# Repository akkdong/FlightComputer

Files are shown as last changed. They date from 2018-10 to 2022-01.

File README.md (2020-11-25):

# Flight Computer(Assistant)

## Hardware 
* Raspberry PI Zero
* E-Ink
* STM32H7 Dual core
* Peripherals
  * 10DOF IMU
  * GPS
  * SD-Card
  * Battery change
  * Codec
  * ...
  <p>
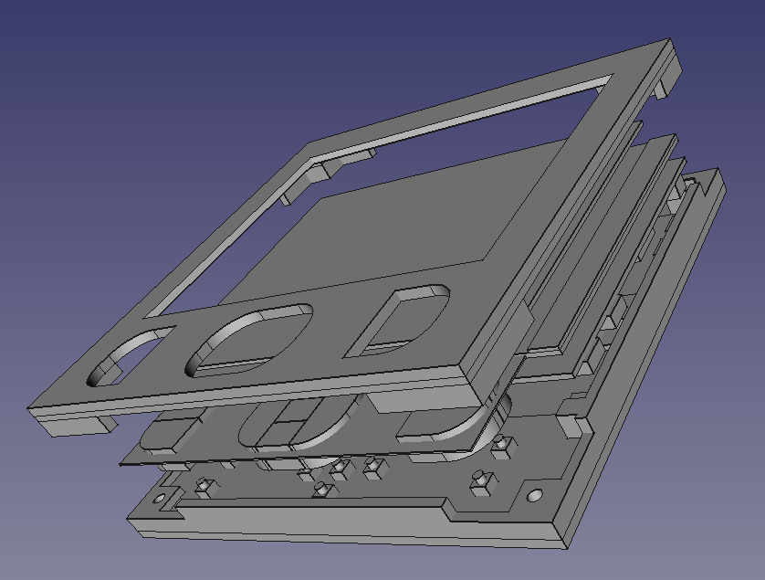
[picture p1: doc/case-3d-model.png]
  
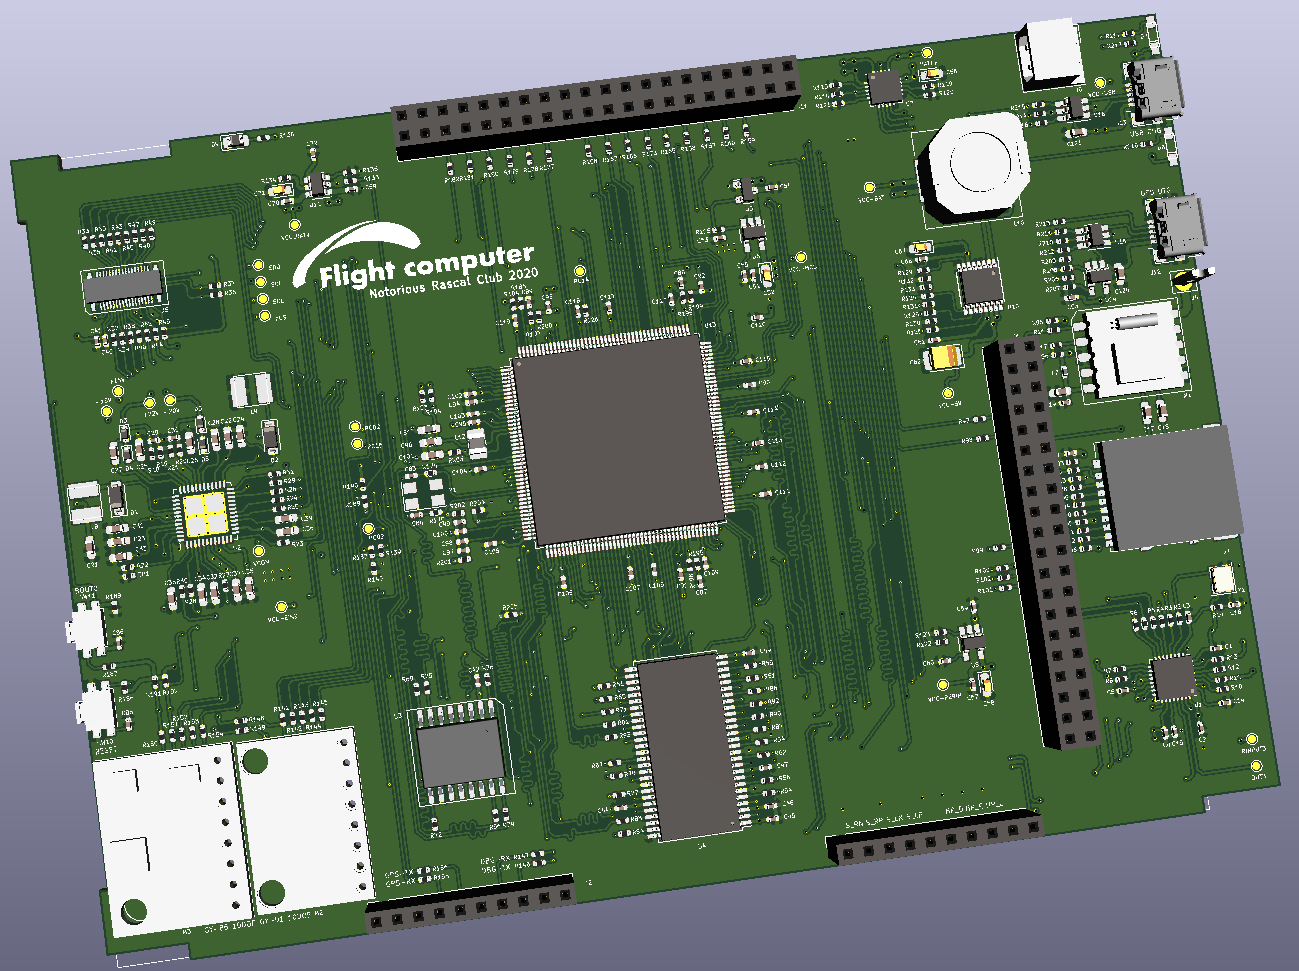
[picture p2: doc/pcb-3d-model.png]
  
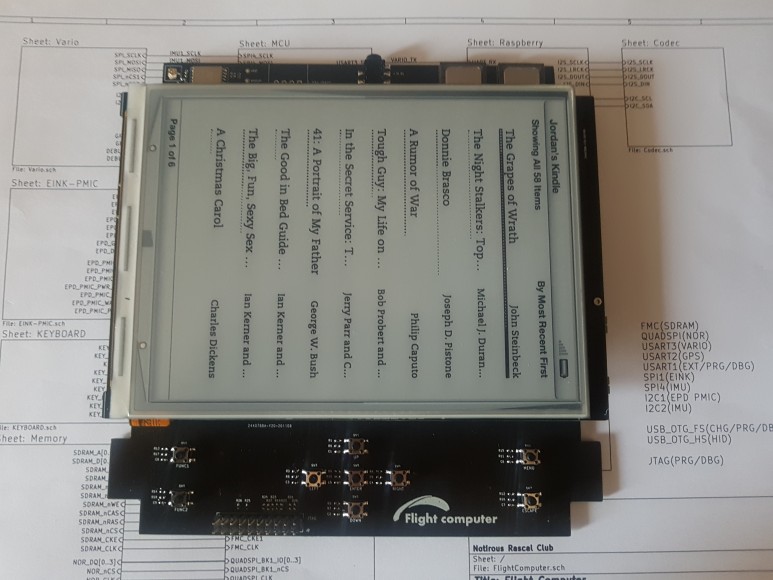
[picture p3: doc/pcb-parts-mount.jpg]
  
  <p>
* ...

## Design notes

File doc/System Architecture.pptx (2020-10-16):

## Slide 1

E-INK

GPIO

STM32H745IIT

RPi

GPS

UART

GPIO/I2C

E-INK PMU

USB

OTG

IMU

SPI

I2C

GPIO

Power booster

SDIO

SD-CARD

KEYs

GPIO

GPIO

Regulator

Regulator

LEDs

EXT

GPIO

UART

Charger

I2S, I2C

CODEC

16bit Bus

SDRAM(32M)

I2C

RADIO(?)

USB Device
Debug(Power)

USBFS

QSPI

QSPI Flash(32M)

USB Host
(HID)

USBHS

UART, SPI

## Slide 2

External
Power
(USB-FS)

Battery

VCC_USB

+BATT

Charger

VCC_BAT

VCC_BAT

REG 3V3

VCC_MCU

MCU

Load
SW

ADC_BATTERY

LED

VCC_BAT+

IMU

REG 3V3

VCC_PERIH

VCC_PERIH

KEYs

UART-EXT

REG 3V3

E-INK PMIU

Power booster
5V

VCC_MEM

GPS

MEMs

+22/-20/+15/-15/VCC_EINK

E-INK

VCC_3V3

USB-HS

CODEC

VCC_5V

RPI

VCC_3V3

SD-CARD/Radio

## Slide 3

GPS w/t Antenna

Debug Port

Audio Jack

Speaker-L

Speaker-R

E-INK

USB-OTG #1

SD-Card

HDMI

USB Device
&
Charge

USB-OTG #2

Up

Func1

Left

Enter/
Power

Right

Func2

Menu

Down

Escape

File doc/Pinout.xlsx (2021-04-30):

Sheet: STM32L4x1_LQFP48
Pins | Pin name | Type | I/O Level | Main | Alternate
 |  |  |  |  | Default | Remap
1 | Vbat | S |  | Vbat |  |  | VCC
2 | PC13-TAMPER-RTC | I/O |  | PC13 | TAMPER-RTC
3 | PC14-OSS32_IN | I/O |  | PC14 | OSC32_IN
4 | PC15-OSC32_OUT | I/O |  | PC15 | OSC32_OUT
5 | OSC_IN | I |  | OSC_IN |  |  | OSC_IN
6 | OSC_OUT | O |  | OSC_OUT |  |  | OSC_OUT
7 | NRST | I/O |  | NRST |  |  | nRST
8 | VSSA | S |  | VSSA |  |  | GND
9 | VDDA | S |  | VDDA |  |  | VCC
10 | PA0-WKUP | I/O |  | PA0 | WKUP/USART2_CTS/ADC12_IN0/TIM2_CH1_ETR
11 | PA1 | I/O |  | PA1 | USART2_RTS/ADC12_IN1/TIM2_CH2
12 | PA2 | I/O |  | PA2 | USART2_TX/ADC12_IN2/TIM2_CH3 |  | UART2_TX
13 | PA3 | I/O |  | PA3 | USART2_RX/ADC12_IN3/TIM2_CH4 |  | UART2_RX
14 | PA4 | I/O |  | PA4 | SP1I_NSS/USART2_CK/ADC12_IN4 |  | SPI_nCS
15 | PA5 | I/O |  | PA5 | SPI1_SCK/ADC12_IN5 |  | SPI_SCLK
16 | PA6 | I/O |  | PA6 | SPI1_MISO/ADC12_IN6/TIM3_CH1 | TIM1_BKIN | SPI_MISO
17 | PA7 | I/O |  | PA7 | SPI1_MOSI/ADC12_IN7/TIM3_CH2 | TIM1_CH1N | SPI_MOSI
18 | PB0 | I/O |  | PB0 | ADC12_IN8/TIM3_CH3 | TIM1_CH2N
19 | PB1 | I/O |  | PB1 | ADC12_IN9/TIM3_CH4 | TIM1_CH3N
20 | PB2 | I/O | FT | PB2/BOOT1 |  |  | BOOT1
21 | PB10 | I/O | FT | PB10 | I2C2_SCL/USART3_TX | TIM2_CH3
22 | PB11 | I/O | FT | PB11 | I2C2_SDA/USART3_RX | TIM2_CH4
23 | VSS_1 | S |  | VSS_1 |  |  | GND
24 | VDD_1 | S |  | VDD_1 |  |  | VCC
25 | PB12 | I/O | FT | PB12 | SPI2_NSS/I2C2_SMBAI/USART3_CK/TIM1_BKIN
26 | PB13 | I/O | FT | PB13 | SPI2_SCK/USART3_CTS/TIM1_CH1N
27 | PB14 | I/O | FT | PB14 | SPI2_MISO/USART3_RTS/TIM1_CH2N
28 | PB15 | I/O | FT | PB15 | SPI2_MOSI/TIM1_CH3N
29 | PA8 | I/O | FT | PA8 | USART1_CK/TIM1_CH1/MCO
30 | PA9 | I/O | FT | PA9 | USART1_TX/TIM1_CH2 |  | UART1_TX
31 | PA10 | I/O | FT | PA10 | USART1_RX/TIM1_CH3 |  | UART1_RX
32 | PA11 | I/O | FT | PA11 | USART1_CTS/CANRX/USBDM/TIM1_CH4 |  | USB_DN
33 | PA12 | I/O | FT | PA12 | USART1_RTS/CANTX/USBDP/TIM1_ETR |  | USB_DP
34 | PA13 | I/O | FT | JTMS/SWDIO |  | PA13 | JTAG_TMS
35 | VSS_2 | S |  | VSS_2 |  |  | GND
36 | VDD_2 | S |  | VDD_2 |  |  | VCC
37 | PA14 | I/O | FT | JTCK/SWCLK |  | PA14 | JTAG_TCK
38 | PA15 | I/O | FT | JTDI |  | TIM2_CH1_ETR/PA15/SPI1_NSS | JTAG_TDI
39 | PB3 | I/O | FT | JTDO |  | TIM2_CH2/PB3/TRACESWO/SPI1_SCK | JTAG_TDO
40 | PB4 | I/O | FT | JNTRST |  | TIM3_CH1/PB4/SPI1_MISO | JTAG_RST
41 | PB5 | I/O |  | PB5 | I2C1_SMBAI | TIM3_CH2/SPI1_MOSI
42 | PB6 | I/O | FT | PB6 | I2C1_SCL/TIM4_CH1 | USART1_TX | I2C_SCL
43 | PB7 | I/O | FT | PB7 | I2C1_SDA/TIM4_CH2 | USART1_RX | I2C_SDA
44 | PH3/BOOT0 | I |  | BOOT0 |  |  | KEY0_BOOT0
45 | PB8 | I/O | FT | PB8 | TIM4_CH3 | I2C1_SCL/CANRX
46 | PB9 | I/O | FT | PB9 | TIM4_CH4 | I2C1_SDA/CANTX
47 | VSS_3 | S |  | VSS_3 |  |  | GND
48 | VDD_3 | S |  | VDD_3 |  |  | VCC
FT = 5V tolerant
I = input, O = output, S = supply

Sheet: STM32F103xx_LQFP48
Pins | Pin name | Type | I/O Level | Main | Alternate
 |  |  |  |  | Default | Remap | Revision 1
1 | Vbat | S |  | Vbat |  |  | Vbat
2 | PC13-TAMPER-RTC | I/O |  | PC13 | TAMPER-RTC |  |  |  | Key
3 | PC14-OSS32_IN | I/O |  | PC14 | OSC32_IN |  |  |  | Up
4 | PC15-OSC32_OUT | I/O |  | PC15 | OSC32_OUT |  |  |  | Down
5 | OSC_IN | I |  | OSC_IN |  |  | OSC |  | Left
6 | OSC_OUT | O |  | OSC_OUT |  |  | OSC |  | Right
7 | NRST | I/O |  | NRST |  |  | RESET |  | Enter
8 | VSSA | S |  | VSSA |  |  | AGND |  | Escape
9 | VDDA | S |  | VDDA |  |  | ACC |  | Func1
10 | PA0-WKUP | I/O |  | PA0 | WKUP/USART2_CTS/ADC12_IN0/TIM2_CH1_ETR |  | Wakeup/KEY_ENTER |  | Func2
11 | PA1 | I/O |  | PA1 | USART2_RTS/ADC12_IN1/TIM2_CH2 |  | KEY_ESC
12 | PA2 | I/O |  | PA2 | USART2_TX/ADC12_IN2/TIM2_CH3 |  | UART2_TX(RPI)
13 | PA3 | I/O |  | PA3 | USART2_RX/ADC12_IN3/TIM2_CH4 |  | UART2_RX(RPI)
14 | PA4 | I/O |  | PA4 | SP1I_NSS/USART2_CK/ADC12_IN4 |  | ADC_BATTERY
15 | PA5 | I/O |  | PA5 | SPI1_SCK/ADC12_IN5 |  | SPI1_SCK
16 | PA6 | I/O |  | PA6 | SPI1_MISO/ADC12_IN6/TIM3_CH1 | TIM1_BKIN | SPI1_MISO |  | IMU1
17 | PA7 | I/O |  | PA7 | SPI1_MOSI/ADC12_IN7/TIM3_CH2 | TIM1_CH1N | SPI1_MOSI |  | I2C
18 | PB0 | I/O |  | PB0 | ADC12_IN8/TIM3_CH3 | TIM1_CH2N | SPI1_CS1 |  | RDY
19 | PB1 | I/O |  | PB1 | ADC12_IN9/TIM3_CH4 | TIM1_CH3N | SPI1_CS2 |  | INT
20 | PB2 | I/O | FT | PB2/BOOT1 |  |  | BOOT1 |  | SYNC
21 | PB10 | I/O | FT | PB10 | I2C2_SCL/USART3_TX | TIM2_CH3 | UART3_TX(GPS)
22 | PB11 | I/O | FT | PB11 | I2C2_SDA/USART3_RX | TIM2_CH4 | UART3_RX(GPS)
23 | VSS_1 | S |  | VSS_1 |  |  | GND
24 | VDD_1 | S |  | VDD_1 |  |  | VCC |  | IM2
25 | PB12 | I/O | FT | PB12 | SPI2_NSS/I2C2_SMBAI/USART3_CK/TIM1_BKIN |  | KEY_UP |  | SPI
26 | PB13 | I/O | FT | PB13 | SPI2_SCK/USART3_CTS/TIM1_CH1N |  | KEY_DOWN |  | CS1
27 | PB14 | I/O | FT | PB14 | SPI2_MISO/USART3_RTS/TIM1_CH2N |  | KEY_RIGHT |  | CS2
28 | PB15 | I/O | FT | PB15 | SPI2_MOSI/TIM1_CH3N |  | KEY_LEFT
29 | PA8 | I/O | FT | PA8 | USART1_CK/TIM1_CH1/MCO |  | LED_STATUS |  | USB_DETECT
30 | PA9 | I/O | FT | PA9 | USART1_TX/TIM1_CH2 |  | UART1_TX(DEBUG) |  | ADC_BAT
31 | PA10 | I/O | FT | PA10 | USART1_RX/TIM1_CH3 |  | UART1_RX(DEBUG)
32 | PA11 | I/O | FT | PA11 | USART1_CTS/CANRX/USBDM/TIM1_CH4 |  | KEY_FUNC1 |  | ENABLE
33 | PA12 | I/O | FT | PA12 | USART1_RTS/CANTX/USBDP/TIM1_ETR |  | KEY_FUNC2 |  | RPI_5V
34 | PA13 | I/O | FT | JTMS/SWDIO |  | PA13 | IMU_DRDY | Input PU on reset | LCD_5V
35 | VSS_2 | S |  | VSS_2 |  |  | GND |  | EN_PERIPH
36 | VDD_2 | S |  | VDD_2 |  |  | VCC |  | EN_BAT
37 | PA14 | I/O | FT | JTCK/SWCLK |  | PA14 | IMU_FSYNC | Input PD on reset
38 | PA15 | I/O | FT | JTDI |  | TIM2_CH1_ETR/PA15/SPI1_NSS | IMU_INT | Input PU on reset
39 | PB3 | I/O | FT | JTDO |  | TIM2_CH2/PB3/TRACESWO/SPI1_SCK |  | Input floating on reset
40 | PB4 | I/O | FT | JNTRST |  | TIM3_CH1/PB4/SPI1_MISO | ENABLE_PERIPH | Input PU on reset
41 | PB5 | I/O |  | PB5 | I2C1_SMBAI | TIM3_CH2/SPI1_MOSI | ENABLE_BAT
42 | PB6 | I/O | FT | PB6 | I2C1_SCL/TIM4_CH1 | USART1_TX | I2C1_SCL
43 | PB7 | I/O | FT | PB7 | I2C1_SDA/TIM4_CH2 | USART1_RX | I2C1_SDA
44 | BOOT0 | I |  | BOOT0 |  |  | BOOT0
45 | PB8 | I/O | FT | PB8 | TIM4_CH3 | I2C1_SCL/CANRX | ENABLE_5V
46 | PB9 | I/O | FT | PB9 | TIM4_CH4 | I2C1_SDA/CANTX | ENABLE_LCD
47 | VSS_3 | S |  | VSS_3 |  |  | GND
48 | VDD_3 | S |  | VDD_3 |  |  | VCC
FT = 5V tolerant
I = input, O = output, S = supply

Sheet: Raspberry PI
Pins | Pin name | SDIO | UART | PCM | WiringPi | I2C | SPI | E-INK | GPIO
 |  |  |  |  |  |  |  |  |  | Revision 1
1 | 3v3 Power
2 | 5v Power
3 | BCM 2 |  |  |  | GPIO 8 | DAT1 |  |  |  | I2C_DAT
4 | 5v Power
5 | BCM 3 |  |  |  | GPIO 9 | SCL1 |  |  |  | I2C_SCL
6 | GND
7 | BCM 4 |  |  |  | GPIO 7
8 | BCM 14 |  | TXD |  | GPIO 15 |  |  |  |  | UART_TXD
9 | GND
10 | BCM 15 |  | RXD |  | GPIO 16 |  |  |  |  | UART_RXD
11 | BCM 17 |  |  |  | GPIO 0 |  | SPI1 CE1
12 | BCM 18 |  |  | CLK | GPIO 1 |  | SPI1 CE0 |  |  | I2S_SCLK
13 | BCM 27 | DAT3 |  |  | GPIO 2 |  |  |  |  | SDIO_DAT3
14 | GND
15 | BCM 22 | CLK |  |  | GPIO 3 |  |  |  |  | SDIO_CLK
16 | BCM 23 | CMD |  |  | GPIO 4 |  |  |  |  | SDIO_CMD
17 | 3v3 Power
18 | BCM 24 | DAT0 |  |  | GPIO 5 |  |  |  |  | SDIO_DAT0
19 | BCM 10 |  |  |  | GPIO 12 |  | SPI0 MOSI | DIN
20 | GND
21 | BCM 9 |  |  |  | GPIO13 |  | SPI0 MISO
22 | BCM 25 | DAT1 |  |  | GPIO 6 |  |  |  |  | SDIO_DAT1
23 | BCM 11 |  |  |  | GPIO 14 |  | SPI0 SCLK | CLK
24 | BCM 8 |  |  |  | GPIO 10 |  | SPI0 CE0 | CS
25 | GND
26 | BCM 7 |  |  |  | GPIO 11 |  | SPI0 CE1
27 | BCM 0 |  |  |  | GPIO 30 | DAT0
28 | BCM 1 |  |  |  | GPIO 31 | SCL0
29 | BCM 5 |  |  |  | GPIO 21 |  |  | DC
30 | GND
31 | BCM 6 |  |  |  | GPIO 22 |  |  | RST
32 | BCM 12 |  |  |  | GPIO 26
33 | BCM 13 |  |  |  | GPIO 23 |  |  | BUSY
34 | GND
35 | BCM 19 |  |  | FS | GPIO 24 |  | SPI1 MISO |  |  | I2S_LRCK
36 | BCM 16 |  |  |  | GPIO 27 |  | SPI1 CE2 |  | EN_OTG
37 | BCM 26 | DAT2 |  |  | GPIO 25 |  |  |  |  | SDIO_DAT2
38 | BCM 20 |  |  | DIN | GPIO 28 |  | SPI1 MOSI |  |  | I2S_DIN
39 | GND
40 | BCM 21 |  |  | DOUT | GPIO 29 |  | SPI1 SCLK |  |  | I2S_DCOUT
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

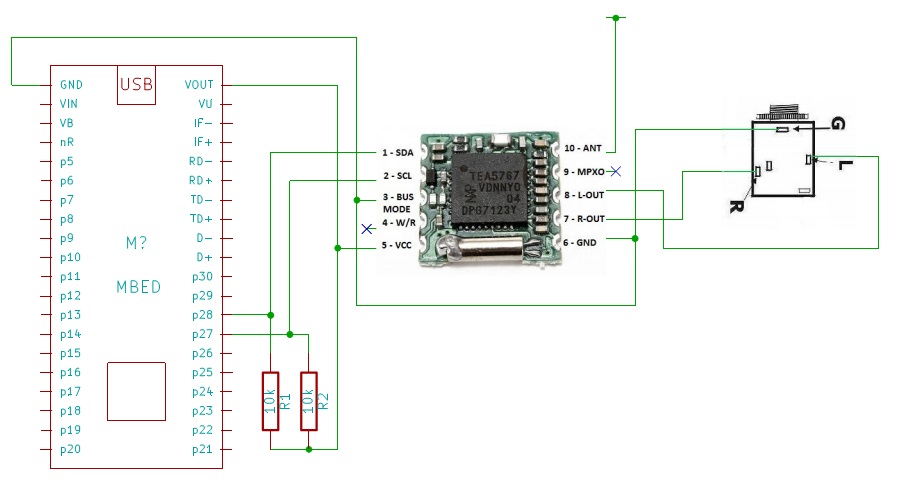
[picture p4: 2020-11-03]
doc/datasheet/tea5767-schematic.jpg

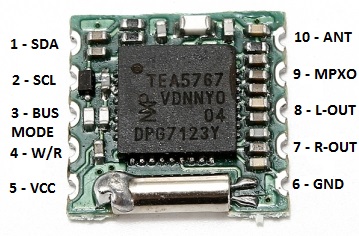
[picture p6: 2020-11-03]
doc/datasheet/tea5767_pinout.jpg

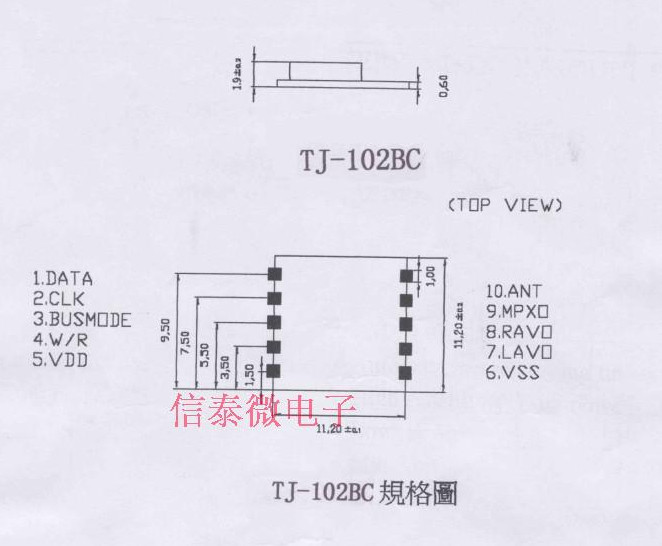
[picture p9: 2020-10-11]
doc/datasheet/TJ-102BC.jpg

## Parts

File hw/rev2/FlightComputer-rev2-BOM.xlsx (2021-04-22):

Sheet: FlightComputer-rev2-BOM
Reference(s) | References | Qty | Flag | Value | Parts | Manufacturer Part# | LibPart | Footprint | Datasheet
C27 | C27 | 1 |  | 0.01uF | a |  | Device:C_Small | Capacitor_SMD:C_0603_1608Metric_Pad1.05x0.95mm_HandSolder | Multilayer Ceramic Capacitors MLCC - SMD/SMT 25V 0.01uF X7R 0603 10% AEC-Q200
C28 | C27, C28 | 2 | Last | 0.01uF | a |  | Device:C_Small | Capacitor_SMD:C_0603_1608Metric_Pad1.05x0.95mm_HandSolder | Multilayer Ceramic Capacitors MLCC - SMD/SMT 25V 0.01uF X7R 0603 10% AEC-Q200
C25 | C25 | 1 |  | 0.1uF | b |  | Device:C_Small | Capacitor_SMD:C_0603_1608Metric_Pad1.05x0.95mm_HandSolder | Multilayer Ceramic Capacitors MLCC - SMD/SMT .1uF 25V 10% AEC-Q200
C26 | C25, C26 | 2 | Last | 0.1uF | b |  | Device:C_Small | Capacitor_SMD:C_0603_1608Metric_Pad1.05x0.95mm_HandSolder | Multilayer Ceramic Capacitors MLCC - SMD/SMT .1uF 25V 10% AEC-Q200
C1 | C1 | 1 |  | 0.1uF | C0402 |  | Device:C_Small | FlightComputer_Library:C_0402_1005Metric_Pad0.74x0.62mm_HandSolder | ~
C100 | C1, C100 | 2 |  | 0.1uF | C0402 |  | Device:C_Small | FlightComputer_Library:C_0402_1005Metric_Pad0.74x0.62mm_HandSolder | ~
C1005 | C1, C100, C1005 | 3 |  | 0.1uF | C0402 |  | Device:C_Small | FlightComputer_Library:C_0402_1005Metric_Pad0.74x0.62mm_HandSolder | ~
C1006 | C1, C100, C1005, C1006 | 4 |  | 0.1uF | C0402 |  | Device:C_Small | FlightComputer_Library:C_0402_1005Metric_Pad0.74x0.62mm_HandSolder | ~
C1007 | C1, C100, C1005, C1006, C1007 | 5 |  | 0.1uF | C0402 |  | Device:C_Small | FlightComputer_Library:C_0402_1005Metric_Pad0.74x0.62mm_HandSolder | ~
C1017 | C1, C100, C1005, C1006, C1007, C1017 | 6 |  | 0.1uF | C0402 |  | Device:C_Small | FlightComputer_Library:C_0402_1005Metric_Pad0.74x0.62mm_HandSolder | ~
C1018 | C1, C100, C1005, C1006, C1007, C1017, C1018 | 7 |  | 0.1uF | C0402 |  | Device:C_Small | FlightComputer_Library:C_0402_1005Metric_Pad0.74x0.62mm_HandSolder | ~
C1019 | C1, C100, C1005, C1006, C1007, C1017, C1018, C1019 | 8 |  | 0.1uF | C0402 |  | Device:C_Small | FlightComputer_Library:C_0402_1005Metric_Pad0.74x0.62mm_HandSolder | ~
C102 | C1, C100, C1005, C1006, C1007, C1017, C1018, C1019, C102 | 9 |  | 0.1uF | C0402 |  | Device:C_Small | FlightComputer_Library:C_0402_1005Metric_Pad0.74x0.62mm_HandSolder | ~
C103 | C1, C100, C1005, C1006, C1007, C1017, C1018, C1019, C102, C103 | 10 |  | 0.1uF | C0402 |  | Device:C_Small | FlightComputer_Library:C_0402_1005Metric_Pad0.74x0.62mm_HandSolder | ~
C104 | C1, C100, C1005, C1006, C1007, C1017, C1018, C1019, C102, C103, C104 | 11 |  | 0.1uF | C0402 |  | Device:C_Small | FlightComputer_Library:C_0402_1005Metric_Pad0.74x0.62mm_HandSolder | ~
C105 | C1, C100, C1005, C1006, C1007, C1017, C1018, C1019, C102, C103, C104, C105 | 12 |  | 0.1uF | C0402 |  | Device:C_Small | FlightComputer_Library:C_0402_1005Metric_Pad0.74x0.62mm_HandSolder | ~
C106 | C1, C100, C1005, C1006, C1007, C1017, C1018, C1019, C102, C103, C104, C105, C106 | 13 |  | 0.1uF | C0402 |  | Device:C_Small | FlightComputer_Library:C_0402_1005Metric_Pad0.74x0.62mm_HandSolder | ~
C107 | C1, C100, C1005, C1006, C1007, C1017, C1018, C1019, C102, C103, C104, C105, C106, C107 | 14 |  | 0.1uF | C0402 |  | Device:C_Small | FlightComputer_Library:C_0402_1005Metric_Pad0.74x0.62mm_HandSolder | ~
C108 | C1, C100, C1005, C1006, C1007, C1017, C1018, C1019, C102, C103, C104, C105, C106, C107, C108 | 15 |  | 0.1uF | C0402 |  | Device:C_Small | FlightComputer_Library:C_0402_1005Metric_Pad0.74x0.62mm_HandSolder | ~
C109 | C1, C100, C1005, C1006, C1007, C1017, C1018, C1019, C102, C103, C104, C105, C106, C107, C108, C109 | 16 |  | 0.1uF | C0402 |  | Device:C_Small | FlightComputer_Library:C_0402_1005Metric_Pad0.74x0.62mm_HandSolder | ~
C111 | C1, C100, C1005, C1006, C1007, C1017, C1018, C1019, C102, C103, C104, C105, C106, C107, C108, C109, C111 | 17 |  | 0.1uF | C0402 |  | Device:C_Small | FlightComputer_Library:C_0402_1005Metric_Pad0.74x0.62mm_HandSolder | ~
C112 | C1, C100, C1005, C1006, C1007, C1017, C1018, C1019, C102, C103, C104, C105, C106, C107, C108, C109, C111, C112 | 18 |  | 0.1uF | C0402 |  | Device:C_Small | FlightComputer_Library:C_0402_1005Metric_Pad0.74x0.62mm_HandSolder | ~
C113 | C1, C100, C1005, C1006, C1007, C1017, C1018, C1019, C102, C103, C104, C105, C106, C107, C108, C109, C111, C112, C113 | 19 |  | 0.1uF | C0402 |  | Device:C_Small | FlightComputer_Library:C_0402_1005Metric_Pad0.74x0.62mm_HandSolder | ~
C114 | C1, C100, C1005, C1006, C1007, C1017, C1018, C1019, C102, C103, C104, C105, C106, C107, C108, C109, C111, C112, C113, C114 | 20 |  | 0.1uF | C0402 |  | Device:C_Small | FlightComputer_Library:C_0402_1005Metric_Pad0.74x0.62mm_HandSolder | ~
C115 | C1, C100, C1005, C1006, C1007, C1017, C1018, C1019, C102, C103, C104, C105, C106, C107, C108, C109, C111, C112, C113, C114, C115 | 21 |  | 0.1uF | C0402 |  | Device:C_Small | FlightComputer_Library:C_0402_1005Metric_Pad0.74x0.62mm_HandSolder | ~
C116 | C1, C100, C1005, C1006, C1007, C1017, C1018, C1019, C102, C103, C104, C105, C106, C107, C108, C109, C111, C112, C113, C114, C115, C116 | 22 |  | 0.1uF | C0402 |  | Device:C_Small | FlightComputer_Library:C_0402_1005Metric_Pad0.74x0.62mm_HandSolder | ~
C117 | C1, C100, C1005, C1006, C1007, C1017, C1018, C1019, C102, C103, C104, C105, C106, C107, C108, C109, C111, C112, C113, C114, C115, C116, C117 | 23 |  | 0.1uF | C0402 |  | Device:C_Small | FlightComputer_Library:C_0402_1005Metric_Pad0.74x0.62mm_HandSolder | ~
C118 | C1, C100, C1005, C1006, C1007, C1017, C1018, C1019, C102, C103, C104, C105, C106, C107, C108, C109, C111, C112, C113, C114, C115, C116, C117, C118 | 24 |  | 0.1uF | C0402 |  | Device:C_Small | FlightComputer_Library:C_0402_1005Metric_Pad0.74x0.62mm_HandSolder | ~
C119 | C1, C100, C1005, C1006, C1007, C1017, C1018, C1019, C102, C103, C104, C105, C106, C107, C108, C109, C111, C112, C113, C114, C115, C116, C117, C118, C119 | 25 |  | 0.1uF | C0402 |  | Device:C_Small | FlightComputer_Library:C_0402_1005Metric_Pad0.74x0.62mm_HandSolder | ~
C16 | C1, C100, C1005, C1006, C1007, C1017, C1018, C1019, C102, C103, C104, C105, C106, C107, C108, C109, C111, C112, C113, C114, C115, C116, C117, C118, C119, C16 | 26 |  | 0.1uF | C0402 |  | Device:C_Small | FlightComputer_Library:C_0402_1005Metric_Pad0.74x0.62mm_HandSolder | ~
C19 | C1, C100, C1005, C1006, C1007, C1017, C1018, C1019, C102, C103, C104, C105, C106, C107, C108, C109, C111, C112, C113, C114, C115, C116, C117, C118, C119, C16, C19 | 27 |  | 0.1uF | C0402 |  | Device:C_Small | FlightComputer_Library:C_0402_1005Metric_Pad0.74x0.62mm_HandSolder | ~
C2 | C1, C100, C1005, C1006, C1007, C1017, C1018, C1019, C102, C103, C104, C105, C106, C107, C108, C109, C111, C112, C113, C114, C115, C116, C117, C118, C119, C16, C19, C2 | 28 |  | 0.1uF | C0402 |  | Device:C_Small | FlightComputer_Library:C_0402_1005Metric_Pad0.74x0.62mm_HandSolder | ~
C3 | C1, C100, C1005, C1006, C1007, C1017, C1018, C1019, C102, C103, C104, C105, C106, C107, C108, C109, C111, C112, C113, C114, C115, C116, C117, C118, C119, C16, C19, C2, C3 | 29 |  | 0.1uF | C0402 |  | Device:C_Small | FlightComputer_Library:C_0402_1005Metric_Pad0.74x0.62mm_HandSolder | ~
C41 | C1, C100, C1005, C1006, C1007, C1017, C1018, C1019, C102, C103, C104, C105, C106, C107, C108, C109, C111, C112, C113, C114, C115, C116, C117, C118, C119, C16, C19, C2, C3, C41 | 30 |  | 0.1uF | C0402 |  | Device:C_Small | FlightComputer_Library:C_0402_1005Metric_Pad0.74x0.62mm_HandSolder | ~
C42 | C1, C100, C1005, C1006, C1007, C1017, C1018, C1019, C102, C103, C104, C105, C106, C107, C108, C109, C111, C112, C113, C114, C115, C116, C117, C118, C119, C16, C19, C2, C3, C41, C42 | 31 |  | 0.1uF | C0402 |  | Device:C_Small | FlightComputer_Library:C_0402_1005Metric_Pad0.74x0.62mm_HandSolder | ~
C43 | C1, C100, C1005, C1006, C1007, C1017, C1018, C1019, C102, C103, C104, C105, C106, C107, C108, C109, C111, C112, C113, C114, C115, C116, C117, C118, C119, C16, C19, C2, C3, C41, C42, C43 | 32 |  | 0.1uF | C0402 |  | Device:C_Small | FlightComputer_Library:C_0402_1005Metric_Pad0.74x0.62mm_HandSolder | ~
C44 | C1, C100, C1005, C1006, C1007, C1017, C1018, C1019, C102, C103, C104, C105, C106, C107, C108, C109, C111, C112, C113, C114, C115, C116, C117, C118, C119, C16, C19, C2, C3, C41, C42, C43, C44 | 33 |  | 0.1uF | C0402 |  | Device:C_Small | FlightComputer_Library:C_0402_1005Metric_Pad0.74x0.62mm_HandSolder | ~
C45 | C1, C100, C1005, C1006, C1007, C1017, C1018, C1019, C102, C103, C104, C105, C106, C107, C108, C109, C111, C112, C113, C114, C115, C116, C117, C118, C119, C16, C19, C2, C3, C41, C42, C43, C44, C45 | 34 |  | 0.1uF | C0402 |  | Device:C_Small | FlightComputer_Library:C_0402_1005Metric_Pad0.74x0.62mm_HandSolder | ~
C46 | C1, C100, C1005, C1006, C1007, C1017, C1018, C1019, C102, C103, C104, C105, C106, C107, C108, C109, C111, C112, C113, C114, C115, C116, C117, C118, C119, C16, C19, C2, C3, C41, C42, C43, C44, C45, C46 | 35 |  | 0.1uF | C0402 |  | Device:C_Small | FlightComputer_Library:C_0402_1005Metric_Pad0.74x0.62mm_HandSolder | ~
C47 | C1, C100, C1005, C1006, C1007, C1017, C1018, C1019, C102, C103, C104, C105, C106, C107, C108, C109, C111, C112, C113, C114, C115, C116, C117, C118, C119, C16, C19, C2, C3, C41, C42, C43, C44, C45, C46, C47 | 36 |  | 0.1uF | C0402 |  | Device:C_Small | FlightComputer_Library:C_0402_1005Metric_Pad0.74x0.62mm_HandSolder | ~
C48 | C1, C100, C1005, C1006, C1007, C1017, C1018, C1019, C102, C103, C104, C105, C106, C107, C108, C109, C111, C112, C113, C114, C115, C116, C117, C118, C119, C16, C19, C2, C3, C41, C42, C43, C44, C45, C46, C47, C48 | 37 |  | 0.1uF | C0402 |  | Device:C_Small | FlightComputer_Library:C_0402_1005Metric_Pad0.74x0.62mm_HandSolder | ~
C49 | C1, C100, C1005, C1006, C1007, C1017, C1018, C1019, C102, C103, C104, C105, C106, C107, C108, C109, C111, C112, C113, C114, C115, C116, C117, C118, C119, C16, C19, C2, C3, C41, C42, C43, C44, C45, C46, C47, C48, C49 | 38 |  | 0.1uF | C0402 |  | Device:C_Small | FlightComputer_Library:C_0402_1005Metric_Pad0.74x0.62mm_HandSolder | ~
C50 | C1, C100, C1005, C1006, C1007, C1017, C1018, C1019, C102, C103, C104, C105, C106, C107, C108, C109, C111, C112, C113, C114, C115, C116, C117, C118, C119, C16, C19, C2, C3, C41, C42, C43, C44, C45, C46, C47, C48, C49, C50 | 39 |  | 0.1uF | C0402 |  | Device:C_Small | FlightComputer_Library:C_0402_1005Metric_Pad0.74x0.62mm_HandSolder | ~
C51 | C1, C100, C1005, C1006, C1007, C1017, C1018, C1019, C102, C103, C104, C105, C106, C107, C108, C109, C111, C112, C113, C114, C115, C116, C117, C118, C119, C16, C19, C2, C3, C41, C42, C43, C44, C45, C46, C47, C48, C49, C50, C51 | 40 |  | 0.1uF | C0402 |  | Device:C_Small | FlightComputer_Library:C_0402_1005Metric_Pad0.74x0.62mm_HandSolder | ~
C57 | C1, C100, C1005, C1006, C1007, C1017, C1018, C1019, C102, C103, C104, C105, C106, C107, C108, C109, C111, C112, C113, C114, C115, C116, C117, C118, C119, C16, C19, C2, C3, C41, C42, C43, C44, C45, C46, C47, C48, C49, C50, C51, C57 | 41 |  | 0.1uF | C0402 |  | Device:C_Small | FlightComputer_Library:C_0402_1005Metric_Pad0.74x0.62mm_HandSolder | ~
C70 | C1, C100, C1005, C1006, C1007, C1017, C1018, C1019, C102, C103, C104, C105, C106, C107, C108, C109, C111, C112, C113, C114, C115, C116, C117, C118, C119, C16, C19, C2, C3, C41, C42, C43, C44, C45, C46, C47, C48, C49, C50, C51, C57, C70 | 42 |  | 0.1uF | C0402 |  | Device:C_Small | FlightComputer_Library:C_0402_1005Metric_Pad0.74x0.62mm_HandSolder | ~
C76 | C1, C100, C1005, C1006, C1007, C1017, C1018, C1019, C102, C103, C104, C105, C106, C107, C108, C109, C111, C112, C113, C114, C115, C116, C117, C118, C119, C16, C19, C2, C3, C41, C42, C43, C44, C45, C46, C47, C48, C49, C50, C51, C57, C70, C76 | 43 |  | 0.1uF | C0402 |  | Device:C_Small | FlightComputer_Library:C_0402_1005Metric_Pad0.74x0.62mm_HandSolder | ~
C80 | C1, C100, C1005, C1006, C1007, C1017, C1018, C1019, C102, C103, C104, C105, C106, C107, C108, C109, C111, C112, C113, C114, C115, C116, C117, C118, C119, C16, C19, C2, C3, C41, C42, C43, C44, C45, C46, C47, C48, C49, C50, C51, C57, C70, C76, C80 | 44 |  | 0.1uF | C0402 |  | Device:C_Small | FlightComputer_Library:C_0402_1005Metric_Pad0.74x0.62mm_HandSolder | ~
C81 | C1, C100, C1005, C1006, C1007, C1017, C1018, C1019, C102, C103, C104, C105, C106, C107, C108, C109, C111, C112, C113, C114, C115, C116, C117, C118, C119, C16, C19, C2, C3, C41, C42, C43, C44, C45, C46, C47, C48, C49, C50, C51, C57, C70, C76, C80, C81 | 45 |  | 0.1uF | C0402 |  | Device:C_Small | FlightComputer_Library:C_0402_1005Metric_Pad0.74x0.62mm_HandSolder | ~
C85 | C1, C100, C1005, C1006, C1007, C1017, C1018, C1019, C102, C103, C104, C105, C106, C107, C108, C109, C111, C112, C113, C114, C115, C116, C117, C118, C119, C16, C19, C2, C3, C41, C42, C43, C44, C45, C46, C47, C48, C49, C50, C51, C57, C70, C76, C80, C81, C85 | 46 |  | 0.1uF | C0402 |  | Device:C_Small | FlightComputer_Library:C_0402_1005Metric_Pad0.74x0.62mm_HandSolder | ~
C86 | C1, C100, C1005, C1006, C1007, C1017, C1018, C1019, C102, C103, C104, C105, C106, C107, C108, C109, C111, C112, C113, C114, C115, C116, C117, C118, C119, C16, C19, C2, C3, C41, C42, C43, C44, C45, C46, C47, C48, C49, C50, C51, C57, C70, C76, C80, C81, C85, C86 | 47 |  | 0.1uF | C0402 |  | Device:C_Small | FlightComputer_Library:C_0402_1005Metric_Pad0.74x0.62mm_HandSolder | ~
C87 | C1, C100, C1005, C1006, C1007, C1017, C1018, C1019, C102, C103, C104, C105, C106, C107, C108, C109, C111, C112, C113, C114, C115, C116, C117, C118, C119, C16, C19, C2, C3, C41, C42, C43, C44, C45, C46, C47, C48, C49, C50, C51, C57, C70, C76, C80, C81, C85, C86, C87 | 48 |  | 0.1uF | C0402 |  | Device:C_Small | FlightComputer_Library:C_0402_1005Metric_Pad0.74x0.62mm_HandSolder | ~
C88 | C1, C100, C1005, C1006, C1007, C1017, C1018, C1019, C102, C103, C104, C105, C106, C107, C108, C109, C111, C112, C113, C114, C115, C116, C117, C118, C119, C16, C19, C2, C3, C41, C42, C43, C44, C45, C46, C47, C48, C49, C50, C51, C57, C70, C76, C80, C81, C85, C86, C87, C88 | 49 |  | 0.1uF | C0402 |  | Device:C_Small | FlightComputer_Library:C_0402_1005Metric_Pad0.74x0.62mm_HandSolder | ~
C89 | C1, C100, C1005, C1006, C1007, C1017, C1018, C1019, C102, C103, C104, C105, C106, C107, C108, C109, C111, C112, C113, C114, C115, C116, C117, C118, C119, C16, C19, C2, C3, C41, C42, C43, C44, C45, C46, C47, C48, C49, C50, C51, C57, C70, C76, C80, C81, C85, C86, C87, C88, C89 | 50 |  | 0.1uF | C0402 |  | Device:C_Small | FlightComputer_Library:C_0402_1005Metric_Pad0.74x0.62mm_HandSolder | ~
C94 | C1, C100, C1005, C1006, C1007, C1017, C1018, C1019, C102, C103, C104, C105, C106, C107, C108, C109, C111, C112, C113, C114, C115, C116, C117, C118, C119, C16, C19, C2, C3, C41, C42, C43, C44, C45, C46, C47, C48, C49, C50, C51, C57, C70, C76, C80, C81, C85, C86, C87, C88, C89, C94 | 51 |  | 0.1uF | C0402 |  | Device:C_Small | FlightComputer_Library:C_0402_1005Metric_Pad0.74x0.62mm_HandSolder | ~
C98 | C1, C100, C1005, C1006, C1007, C1017, C1018, C1019, C102, C103, C104, C105, C106, C107, C108, C109, C111, C112, C113, C114, C115, C116, C117, C118, C119, C16, C19, C2, C3, C41, C42, C43, C44, C45, C46, C47, C48, C49, C50, C51, C57, C70, C76, C80, C81, C85, C86, C87, C88, C89, C94, C98 | 52 | Last | 0.1uF | C0402 |  | Device:C_Small | FlightComputer_Library:C_0402_1005Metric_Pad0.74x0.62mm_HandSolder | ~
C122 | C122 | 1 | Last | 0.47uF |  |  | Device:C_Small | FlightComputer_Library:C_0402_1005Metric_Pad0.74x0.62mm_HandSolder | ~
R124 | R124 | 1 |  | 0R |  |  | Device:R_US | FlightComputer_Library:R_0402_1005Metric_Pad0.72x0.64mm_HandSolder | ~
R125 | R124, R125 | 2 |  | 0R |  |  | Device:R_US | FlightComputer_Library:R_0402_1005Metric_Pad0.72x0.64mm_HandSolder | ~
R127 | R124, R125, R127 | 3 |  | 0R |  |  | Device:R_US | FlightComputer_Library:R_0402_1005Metric_Pad0.72x0.64mm_HandSolder | ~
R128 | R124, R125, R127, R128 | 4 |  | 0R |  |  | Device:R_US | FlightComputer_Library:R_0402_1005Metric_Pad0.72x0.64mm_HandSolder | ~
R129 | R124, R125, R127, R128, R129 | 5 |  | 0R |  |  | Device:R_US | FlightComputer_Library:R_0402_1005Metric_Pad0.72x0.64mm_HandSolder | ~
R131 | R124, R125, R127, R128, R129, R131 | 6 |  | 0R |  |  | Device:R_US | FlightComputer_Library:R_0402_1005Metric_Pad0.72x0.64mm_HandSolder | ~
R139 | R124, R125, R127, R128, R129, R131, R139 | 7 |  | 0R |  |  | Device:R_US | FlightComputer_Library:R_0402_1005Metric_Pad0.72x0.64mm_HandSolder | ~
R15 | R124, R125, R127, R128, R129, R131, R139, R15 | 8 |  | 0R |  |  | Device:R_US | FlightComputer_Library:R_0402_1005Metric_Pad0.72x0.64mm_HandSolder | ~
R157 | R124, R125, R127, R128, R129, R131, R139, R15, R157 | 9 |  | 0R |  |  | Device:R_US | FlightComputer_Library:R_0402_1005Metric_Pad0.72x0.64mm_HandSolder | ~
R158 | R124, R125, R127, R128, R129, R131, R139, R15, R157, R158 | 10 |  | 0R |  |  | Device:R_US | FlightComputer_Library:R_0402_1005Metric_Pad0.72x0.64mm_HandSolder | ~
R159 | R124, R125, R127, R128, R129, R131, R139, R15, R157, R158, R159 | 11 |  | 0R |  |  | Device:R_US | FlightComputer_Library:R_0402_1005Metric_Pad0.72x0.64mm_HandSolder | ~
R160 | R124, R125, R127, R128, R129, R131, R139, R15, R157, R158, R159, R160 | 12 |  | 0R |  |  | Device:R_US | FlightComputer_Library:R_0402_1005Metric_Pad0.72x0.64mm_HandSolder | ~
R165 | R124, R125, R127, R128, R129, R131, R139, R15, R157, R158, R159, R160, R165 | 13 |  | 0R |  |  | Device:R_US | FlightComputer_Library:R_0402_1005Metric_Pad0.72x0.64mm_HandSolder | ~
R166 | R124, R125, R127, R128, R129, R131, R139, R15, R157, R158, R159, R160, R165, R166 | 14 |  | 0R |  |  | Device:R_US | FlightComputer_Library:R_0402_1005Metric_Pad0.72x0.64mm_HandSolder | ~
R167 | R124, R125, R127, R128, R129, R131, R139, R15, R157, R158, R159, R160, R165, R166, R167 | 15 |  | 0R |  |  | Device:R_US | FlightComputer_Library:R_0402_1005Metric_Pad0.72x0.64mm_HandSolder | ~
R168 | R124, R125, R127, R128, R129, R131, R139, R15, R157, R158, R159, R160, R165, R166, R167, R168 | 16 |  | 0R |  |  | Device:R_US | FlightComputer_Library:R_0402_1005Metric_Pad0.72x0.64mm_HandSolder | ~
R173 | R124, R125, R127, R128, R129, R131, R139, R15, R157, R158, R159, R160, R165, R166, R167, R168, R173 | 17 |  | 0R |  |  | Device:R_US | FlightComputer_Library:R_0402_1005Metric_Pad0.72x0.64mm_HandSolder | ~
R174 | R124, R125, R127, R128, R129, R131, R139, R15, R157, R158, R159, R160, R165, R166, R167, R168, R173, R174 | 18 |  | 0R |  |  | Device:R_US | FlightComputer_Library:R_0402_1005Metric_Pad0.72x0.64mm_HandSolder | ~
R175 | R124, R125, R127, R128, R129, R131, R139, R15, R157, R158, R159, R160, R165, R166, R167, R168, R173, R174, R175 | 19 | Last | 0R |  |  | Device:R_US | FlightComputer_Library:R_0402_1005Metric_Pad0.72x0.64mm_HandSolder | ~
L11 | L11 | 1 | Last | 1.0uH |  |  | pspice:INDUCTOR | FlightComputer_Library:SRP1038C-1R0M | ~
R1005 | R1005 | 1 |  | 100K |  |  | Device:R_US | FlightComputer_Library:R_0402_1005Metric_Pad0.72x0.64mm_HandSolder | ~
R1006 | R1005, R1006 | 2 |  | 100K |  |  | Device:R_US | FlightComputer_Library:R_0402_1005Metric_Pad0.72x0.64mm_HandSolder | ~
R1008 | R1005, R1006, R1008 | 3 |  | 100K |  |  | Device:R_US | FlightComputer_Library:R_0402_1005Metric_Pad0.72x0.64mm_HandSolder | ~
R1009 | R1005, R1006, R1008, R1009 | 4 |  | 100K |  |  | Device:R_US | FlightComputer_Library:R_0402_1005Metric_Pad0.72x0.64mm_HandSolder | ~
R1010 | R1005, R1006, R1008, R1009, R1010 | 5 |  | 100K |  |  | Device:R_US | FlightComputer_Library:R_0402_1005Metric_Pad0.72x0.64mm_HandSolder | ~
R113 | R1005, R1006, R1008, R1009, R1010, R113 | 6 |  | 100K |  |  | Device:R_US | FlightComputer_Library:R_0402_1005Metric_Pad0.72x0.64mm_HandSolder | ~
R116 | R1005, R1006, R1008, R1009, R1010, R113, R116 | 7 |  | 100K |  |  | Device:R_US | FlightComputer_Library:R_0402_1005Metric_Pad0.72x0.64mm_HandSolder | ~
R120 | R1005, R1006, R1008, R1009, R1010, R113, R116, R120 | 8 |  | 100K |  |  | Device:R_US | FlightComputer_Library:R_0402_1005Metric_Pad0.72x0.64mm_HandSolder | ~
R123 | R1005, R1006, R1008, R1009, R1010, R113, R116, R120, R123 | 9 |  | 100K |  |  | Device:R_US | FlightComputer_Library:R_0402_1005Metric_Pad0.72x0.64mm_HandSolder | ~
R130 | R1005, R1006, R1008, R1009, R1010, R113, R116, R120, R123, R130 | 10 |  | 100K |  |  | Device:R_US | FlightComputer_Library:R_0402_1005Metric_Pad0.72x0.64mm_HandSolder | ~
R136 | R1005, R1006, R1008, R1009, R1010, R113, R116, R120, R123, R130, R136 | 11 |  | 100K |  |  | Device:R_US | FlightComputer_Library:R_0402_1005Metric_Pad0.72x0.64mm_HandSolder | ~
R186 | R1005, R1006, R1008, R1009, R1010, R113, R116, R120, R123, R130, R136, R186 | 12 |  | 100K |  |  | Device:R_US | FlightComputer_Library:R_0402_1005Metric_Pad0.72x0.64mm_HandSolder | ~
R188 | R1005, R1006, R1008, R1009, R1010, R113, R116, R120, R123, R130, R136, R186, R188 | 13 |  | 100K |  |  | Device:R_US | FlightComputer_Library:R_0402_1005Metric_Pad0.72x0.64mm_HandSolder | ~
R193 | R1005, R1006, R1008, R1009, R1010, R113, R116, R120, R123, R130, R136, R186, R188, R193 | 14 |  | 100K |  |  | Device:R_US | FlightComputer_Library:R_0402_1005Metric_Pad0.72x0.64mm_HandSolder | ~
RV1001 | R1005, R1006, R1008, R1009, R1010, R113, R116, R120, R123, R130, R136, R186, R188, R193, RV1001 | 15 | Last | 100K |  |  | Device:R_POT_TRIM_US | Potentiometer_SMD:Potentiometer_Bourns_3214J_Horizontal | ~
C1011 | C1011 | 1 |  | 100pF |  |  | Device:C_Small | FlightComputer_Library:C_0402_1005Metric_Pad0.74x0.62mm_HandSolder | ~
C1012 | C1011, C1012 | 2 | Last | 100pF |  |  | Device:C_Small | FlightComputer_Library:C_0402_1005Metric_Pad0.74x0.62mm_HandSolder | ~
C64 | C64 | 1 |  | 100uF |  |  | Device:CP1_Small | Capacitor_Tantalum_SMD:CP_EIA-3216-10_Kemet-I_Pad1.58x1.35mm_HandSolder | ~
C75 | C64, C75 | 2 | Last | 100uF |  |  | Device:CP1_Small | Capacitor_Tantalum_SMD:CP_EIA-3528-15_AVX-H_Pad1.50x2.35mm_HandSolder | ~
R1017 | R1017 | 1 |  | 10K |  |  | Device:R_US | FlightComputer_Library:R_0402_1005Metric_Pad0.72x0.64mm_HandSolder | ~
R14 | R1017, R14 | 2 |  | 10K |  |  | Device:R_US | FlightComputer_Library:R_0402_1005Metric_Pad0.72x0.64mm_HandSolder | ~
R184 | R1017, R14, R184 | 3 |  | 10K |  |  | Device:R_US | FlightComputer_Library:R_0402_1005Metric_Pad0.72x0.64mm_HandSolder | ~
R189 | R1017, R14, R184, R189 | 4 |  | 10K |  |  | Device:R_US | FlightComputer_Library:R_0402_1005Metric_Pad0.72x0.64mm_HandSolder | ~
R190 | R1017, R14, R184, R189, R190 | 5 |  | 10K |  |  | Device:R_US | FlightComputer_Library:R_0402_1005Metric_Pad0.72x0.64mm_HandSolder | ~
R191 | R1017, R14, R184, R189, R190, R191 | 6 |  | 10K |  |  | Device:R_US | FlightComputer_Library:R_0402_1005Metric_Pad0.72x0.64mm_HandSolder | ~
R192 | R1017, R14, R184, R189, R190, R191, R192 | 7 |  | 10K |  |  | Device:R_US | FlightComputer_Library:R_0402_1005Metric_Pad0.72x0.64mm_HandSolder | ~
R207 | R1017, R14, R184, R189, R190, R191, R192, R207 | 8 |  | 10K |  |  | Device:R_US | FlightComputer_Library:R_0402_1005Metric_Pad0.72x0.64mm_HandSolder | ~
R36 | R1017, R14, R184, R189, R190, R191, R192, R207, R36 | 9 |  | 10K |  |  | Device:R_US | FlightComputer_Library:R_0402_1005Metric_Pad0.72x0.64mm_HandSolder | ~
R37 | R1017, R14, R184, R189, R190, R191, R192, R207, R36, R37 | 10 |  | 10K |  |  | Device:R_US | FlightComputer_Library:R_0402_1005Metric_Pad0.72x0.64mm_HandSolder | ~
R46 | R1017, R14, R184, R189, R190, R191, R192, R207, R36, R37, R46 | 11 | Last | 10K |  |  | Device:R_US | FlightComputer_Library:R_0402_1005Metric_Pad0.72x0.64mm_HandSolder | ~
C78 | C78 | 1 | Last | 10nF |  |  | Device:C_Small | FlightComputer_Library:C_0402_1005Metric_Pad0.74x0.62mm_HandSolder | ~
C101 | C101 | 1 |  | 10uF |  |  | Device:C_Small | Capacitor_SMD:C_0603_1608Metric_Pad1.05x0.95mm_HandSolder | ~
C120 | C101, C120 | 2 |  | 10uF |  |  | Device:C_Small | Capacitor_SMD:C_0603_1608Metric_Pad1.05x0.95mm_HandSolder | ~
C121 | C101, C120, C121 | 3 |  | 10uF |  |  | Device:C_Small | Capacitor_SMD:C_0603_1608Metric_Pad1.05x0.95mm_HandSolder | ~
C123 | C101, C120, C121, C123 | 4 |  | 10uF |  |  | Device:C_Small | Capacitor_SMD:C_0603_1608Metric_Pad1.05x0.95mm_HandSolder | ~
C17 | C101, C120, C121, C123, C17 | 5 |  | 10uF |  |  | Device:C_Small | Capacitor_SMD:C_0603_1608Metric_Pad1.05x0.95mm_HandSolder | ~
C18 | C101, C120, C121, C123, C17, C18 | 6 |  | 10uF |  |  | Device:C_Small | Capacitor_SMD:C_0603_1608Metric_Pad1.05x0.95mm_HandSolder | ~
C20 | C101, C120, C121, C123, C17, C18, C20 | 7 |  | 10uF |  |  | Device:CP1_Small | Capacitor_SMD:C_0603_1608Metric_Pad1.05x0.95mm_HandSolder | ~
C21 | C101, C120, C121, C123, C17, C18, C20, C21 | 8 |  | 10uF |  |  | Device:C_Small | Capacitor_SMD:C_0603_1608Metric_Pad1.05x0.95mm_HandSolder | ~
C22 | C101, C120, C121, C123, C17, C18, C20, C21, C22 | 9 |  | 10uF |  |  | Device:C_Small | Capacitor_SMD:C_0603_1608Metric_Pad1.05x0.95mm_HandSolder | ~
C35 | C101, C120, C121, C123, C17, C18, C20, C21, C22, C35 | 10 |  | 10uF |  |  | Device:C_Small | Capacitor_SMD:C_0603_1608Metric_Pad1.05x0.95mm_HandSolder | ~
C61 | C101, C120, C121, C123, C17, C18, C20, C21, C22, C35, C61 | 11 |  | 10uF |  |  | Device:C_Small | Capacitor_SMD:C_0603_1608Metric_Pad1.05x0.95mm_HandSolder | ~
C65 | C101, C120, C121, C123, C17, C18, C20, C21, C22, C35, C61, C65 | 12 |  | 10uF |  |  | Device:C_Small | Capacitor_SMD:C_0603_1608Metric_Pad1.05x0.95mm_HandSolder | ~
C82 | C101, C120, C121, C123, C17, C18, C20, C21, C22, C35, C61, C65, C82 | 13 |  | 10uF |  |  | Device:CP1_Small | Capacitor_SMD:C_0603_1608Metric_Pad1.05x0.95mm_HandSolder | ~
C96 | C101, C120, C121, C123, C17, C18, C20, C21, C22, C35, C61, C65, C82, C96 | 14 |  | 10uF |  |  | Device:C_Small | Capacitor_SMD:C_0603_1608Metric_Pad1.05x0.95mm_HandSolder | ~
C52 | C101, C120, C121, C123, C17, C18, C20, C21, C22, C35, C61, C65, C82, C96, C52 | 15 |  | 10uF |  |  | Device:CP1_Small | Capacitor_Tantalum_SMD:CP_EIA-1608-08_AVX-J_Pad1.25x1.05mm_HandSolder | ~
C56 | C101, C120, C121, C123, C17, C18, C20, C21, C22, C35, C61, C65, C82, C96, C52, C56 | 16 |  | 10uF |  |  | Device:CP1_Small | Capacitor_Tantalum_SMD:CP_EIA-1608-08_AVX-J_Pad1.25x1.05mm_HandSolder | ~
C58 | C101, C120, C121, C123, C17, C18, C20, C21, C22, C35, C61, C65, C82, C96, C52, C56, C58 | 17 |  | 10uF |  |  | Device:CP1_Small | Capacitor_Tantalum_SMD:CP_EIA-1608-08_AVX-J_Pad1.25x1.05mm_HandSolder | ~
C71 | C101, C120, C121, C123, C17, C18, C20, C21, C22, C35, C61, C65, C82, C96, C52, C56, C58, C71 | 18 |  | 10uF |  |  | Device:CP1_Small | Capacitor_Tantalum_SMD:CP_EIA-1608-08_AVX-J_Pad1.25x1.05mm_HandSolder | ~
C79 | C101, C120, C121, C123, C17, C18, C20, C21, C22, C35, C61, C65, C82, C96, C52, C56, C58, C71, C79 | 19 |  | 10uF |  |  | Device:CP1_Small | Capacitor_Tantalum_SMD:CP_EIA-1608-08_AVX-J_Pad1.25x1.05mm_HandSolder | ~
C8 | C101, C120, C121, C123, C17, C18, C20, C21, C22, C35, C61, C65, C82, C96, C52, C56, C58, C71, C79, C8 | 20 |  | 10uF |  |  | Device:CP1_Small | Capacitor_Tantalum_SMD:CP_EIA-1608-08_AVX-J_Pad1.25x1.05mm_HandSolder | ~
C9 | C101, C120, C121, C123, C17, C18, C20, C21, C22, C35, C61, C65, C82, C96, C52, C56, C58, C71, C79, C8, C9 | 21 | Last | 10uF |  |  | Device:CP1_Small | Capacitor_Tantalum_SMD:CP_EIA-1608-08_AVX-J_Pad1.25x1.05mm_HandSolder | ~
C1010 | C1010 | 1 | Last | 10uF | a |  | Device:CP1_Small | FlightComputer_Library:C_0402_1005Metric_Pad0.74x0.62mm_HandSolder | ~
R1018 | R1018 | 1 | Last | 110K |  |  | Device:R_US | FlightComputer_Library:R_0402_1005Metric_Pad0.72x0.64mm_HandSolder | ~
R1012 | R1012 | 1 | Last | 120K |  |  | Device:R_US | FlightComputer_Library:R_0402_1005Metric_Pad0.72x0.64mm_HandSolder | ~
R121 | R121 | 1 | Last | 15K |  |  | Device:R_US | FlightComputer_Library:R_0402_1005Metric_Pad0.72x0.64mm_HandSolder | ~
C83 | C83 | 1 |  | 18pF |  |  | Device:C_Small | FlightComputer_Library:C_0402_1005Metric_Pad0.74x0.62mm_HandSolder | ~
C84 | C83, C84 | 2 | Last | 18pF |  |  | Device:C_Small | FlightComputer_Library:C_0402_1005Metric_Pad0.74x0.62mm_HandSolder | ~
R118 | R118 | 1 |  | 1K |  |  | Device:R_US | FlightComputer_Library:R_0402_1005Metric_Pad0.72x0.64mm_HandSolder | ~
R119 | R118, R119 | 2 |  | 1K |  |  | Device:R_US | FlightComputer_Library:R_0402_1005Metric_Pad0.72x0.64mm_HandSolder | ~
R132 | R118, R119, R132 | 3 |  | 1K |  |  | Device:R_US | FlightComputer_Library:R_0402_1005Metric_Pad0.72x0.64mm_HandSolder | ~
R133 | R118, R119, R132, R133 | 4 |  | 1K |  |  | Device:R_US | FlightComputer_Library:R_0402_1005Metric_Pad0.72x0.64mm_HandSolder | ~
R134 | R118, R119, R132, R133, R134 | 5 |  | 1K |  |  | Device:R_US | FlightComputer_Library:R_0402_1005Metric_Pad0.72x0.64mm_HandSolder | ~
R138 | R118, R119, R132, R133, R134, R138 | 6 |  | 1K |  |  | Device:R_US | FlightComputer_Library:R_0402_1005Metric_Pad0.72x0.64mm_HandSolder | ~
R171 | R118, R119, R132, R133, R134, R138, R171 | 7 |  | 1K |  |  | Device:R_US | FlightComputer_Library:R_0402_1005Metric_Pad0.72x0.64mm_HandSolder | ~
R187 | R118, R119, R132, R133, R134, R138, R171, R187 | 8 |  | 1K |  |  | Device:R_US | FlightComputer_Library:R_0402_1005Metric_Pad0.72x0.64mm_HandSolder | ~
R217 | R118, R119, R132, R133, R134, R138, R171, R187, R217 | 9 |  | 1K |  |  | Device:R_US | FlightComputer_Library:R_0402_1005Metric_Pad0.72x0.64mm_HandSolder | ~
R28 | R118, R119, R132, R133, R134, R138, R171, R187, R217, R28 | 10 |  | 1K |  |  | Device:R_US | FlightComputer_Library:R_0402_1005Metric_Pad0.72x0.64mm_HandSolder | ~
R29 | R118, R119, R132, R133, R134, R138, R171, R187, R217, R28, R29 | 11 |  | 1K |  |  | Device:R_US | FlightComputer_Library:R_0402_1005Metric_Pad0.72x0.64mm_HandSolder | ~
R30 | R118, R119, R132, R133, R134, R138, R171, R187, R217, R28, R29, R30 | 12 |  | 1K |  |  | Device:R_US | FlightComputer_Library:R_0402_1005Metric_Pad0.72x0.64mm_HandSolder | ~
R31 | R118, R119, R132, R133, R134, R138, R171, R187, R217, R28, R29, R30, R31 | 13 | Last | 1K |  |  | Device:R_US | FlightComputer_Library:R_0402_1005Metric_Pad0.72x0.64mm_HandSolder | ~
R115 | R115 | 1 |  | 1M |  |  | Device:R_US | FlightComputer_Library:R_0402_1005Metric_Pad0.72x0.64mm_HandSolder | ~
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

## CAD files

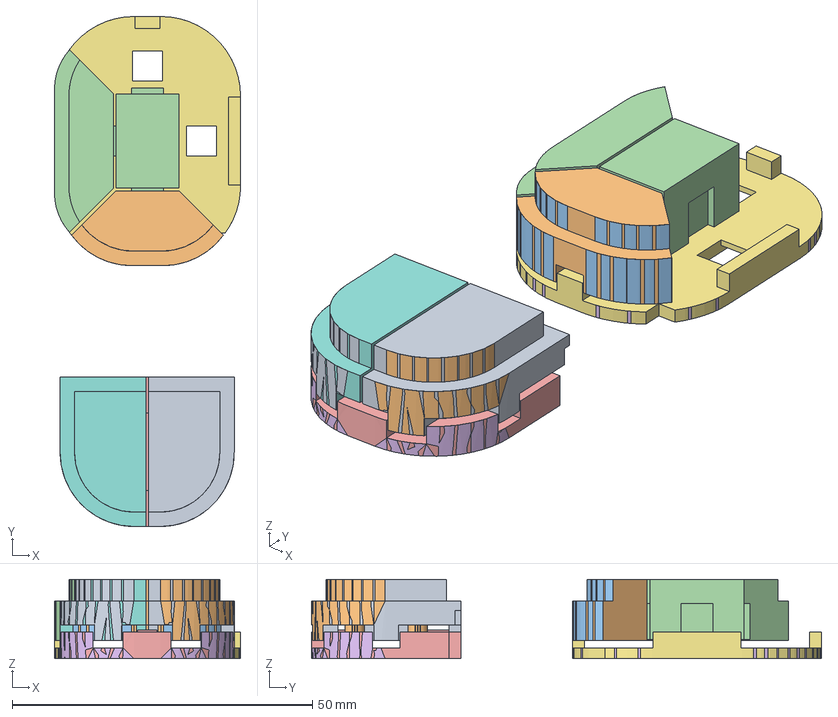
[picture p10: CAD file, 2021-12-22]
hw/case/FlightComputer_ButtonDesign.FCStd
31.0 x 85.0 x 13.2 mm
BTN-Side-Up
BTN_Side-Down
BTN-Center-LeftRight
BTN-Center-UpDown
BTN-Center-Center
BTN-Side-Guide
BTN-Center-Guide
BTN-Side-Up (Meshed)
BTN_Side-Down (Meshed)
BTN-Center-LeftRight (Meshed)
BTN-Center-UpDown (Meshed)
BTN-Center-Center (Meshed)
BTN-Side-Guide (Meshed)
BTN-Center-Guide (Meshed)

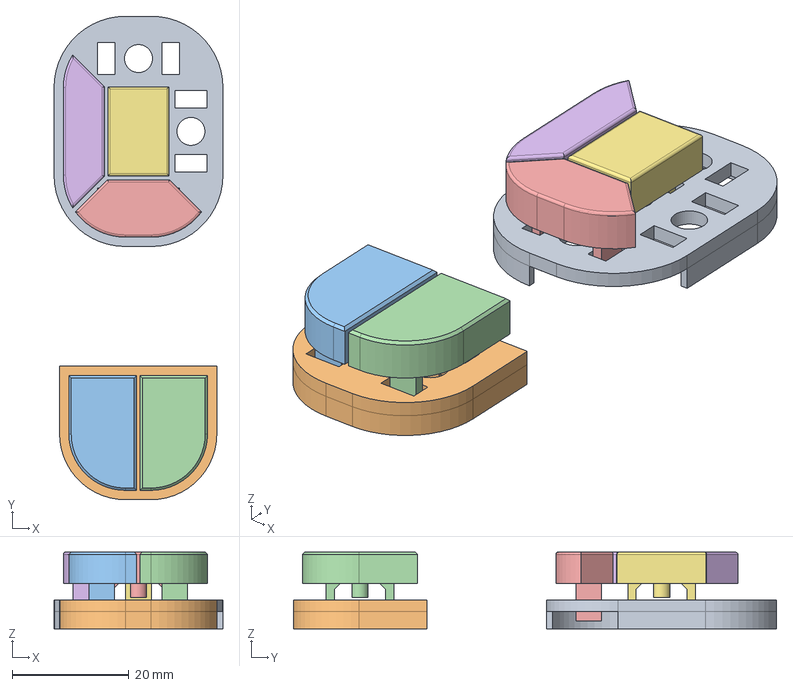
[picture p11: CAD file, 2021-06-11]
hw/case/FlightComputer.FCStd
29.0 x 83.0 x 13.2 mm
BTN-Fix-Center
BTN-Fix-Side
BTN-Side-Up
BTN_Side-Down
BTN-Center-LeftRight
BTN-Center-UpDown
BTN-Center-Center

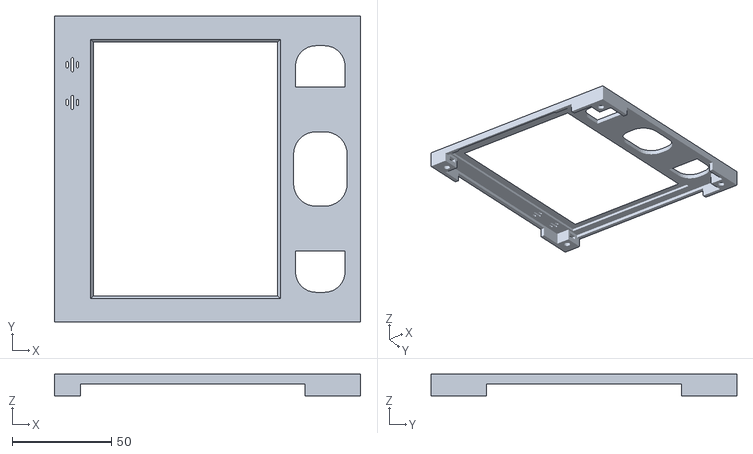
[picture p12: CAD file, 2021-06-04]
hw/case/FC-Cover.stl
154.4 x 154.4 x 11.0

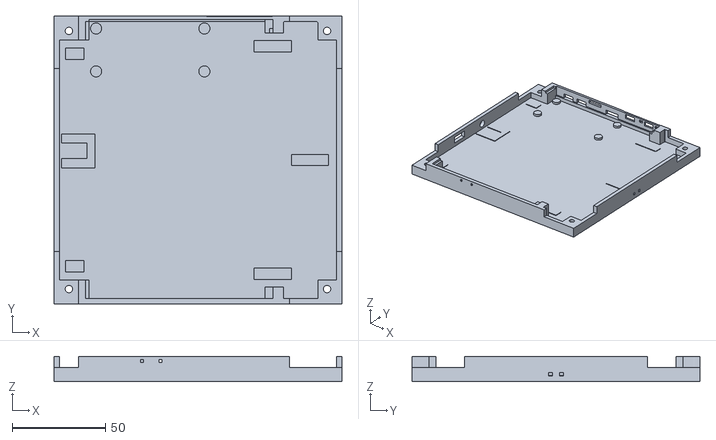
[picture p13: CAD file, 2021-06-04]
hw/case/FC-Bottom-Fix.stl
154.4 x 154.4 x 13.6

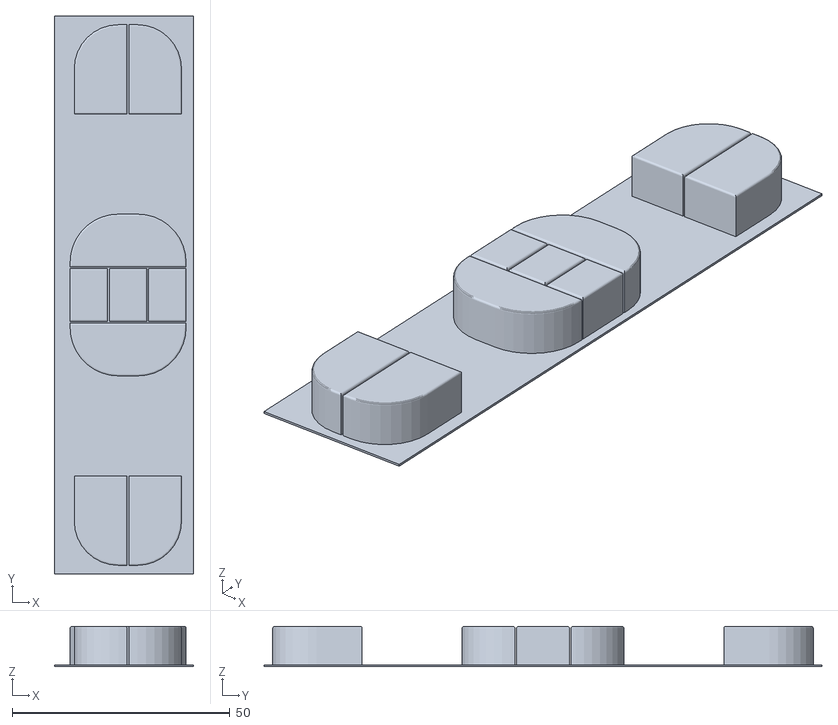
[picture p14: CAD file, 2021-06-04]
hw/case/FC-Button.stl
32.0 x 128.0 x 9.20

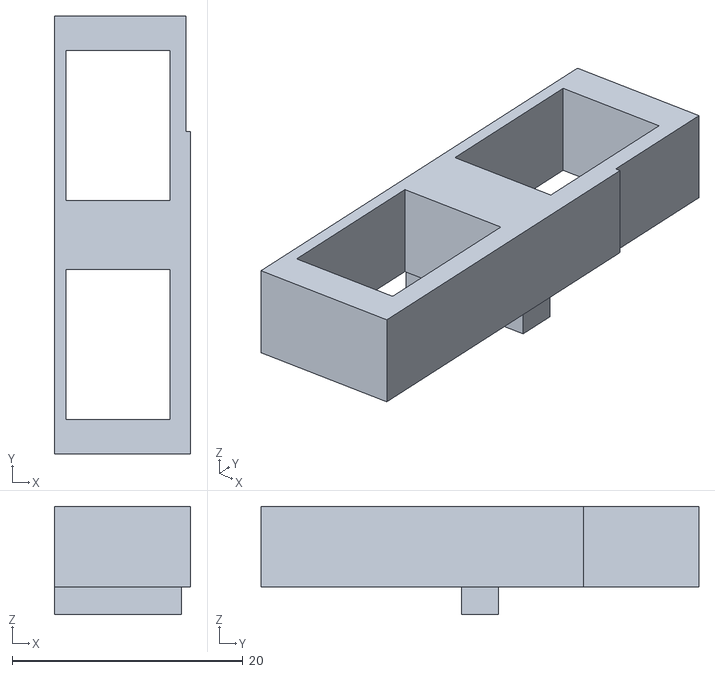
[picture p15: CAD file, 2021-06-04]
hw/case/FC-Enclosure.stl
11.8 x 38.0 x 9.40

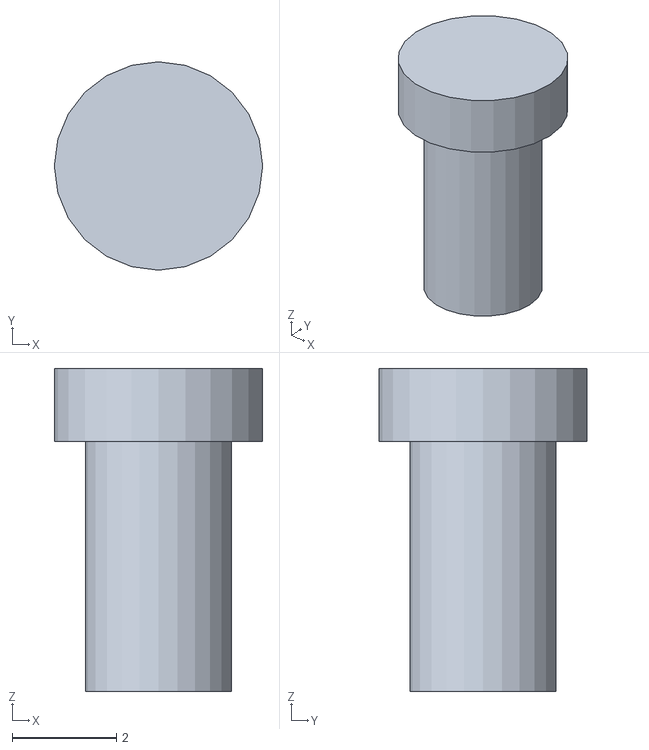
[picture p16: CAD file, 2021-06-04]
hw/case/FC-ButtonGuide.stl
4.00 x 4.00 x 6.20

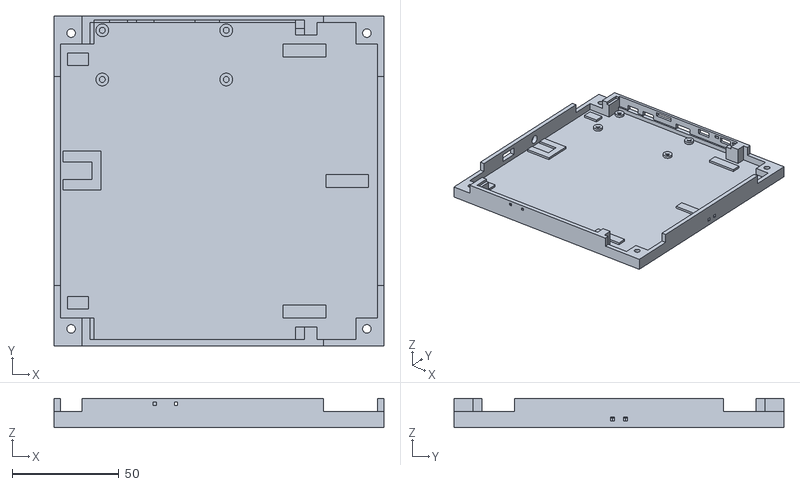
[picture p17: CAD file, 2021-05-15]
hw/case/FC-Bottom.stl
154.4 x 154.4 x 13.6

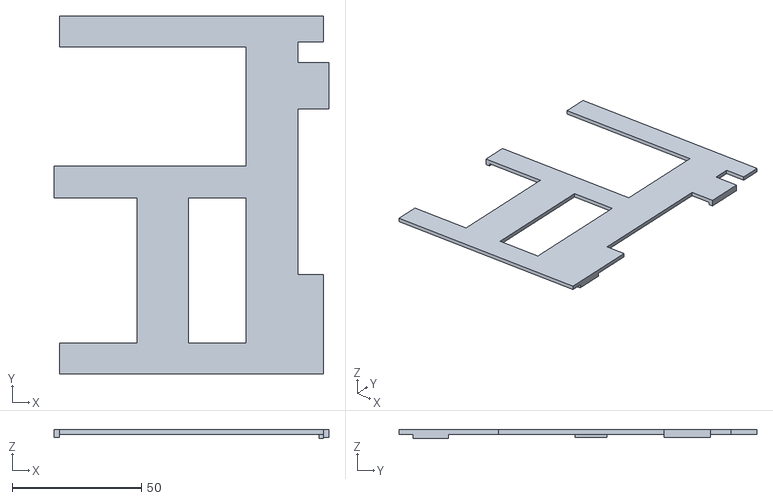
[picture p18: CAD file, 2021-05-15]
hw/case/FC-EPaperSpacer.stl
106.2 x 138.4 x 3.40

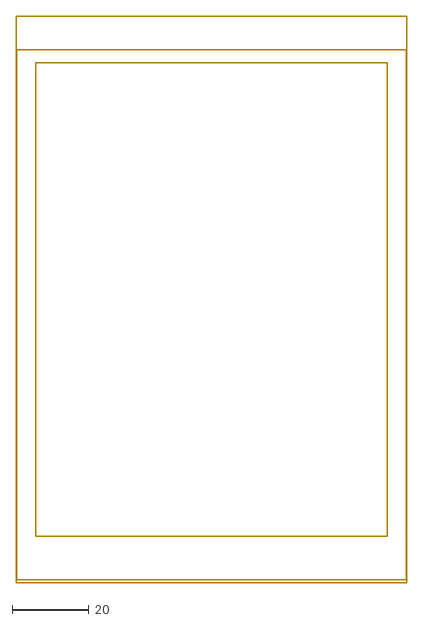
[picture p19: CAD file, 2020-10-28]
hw/case/FlightComputer-EINK.dxf
102.0 x 148.0

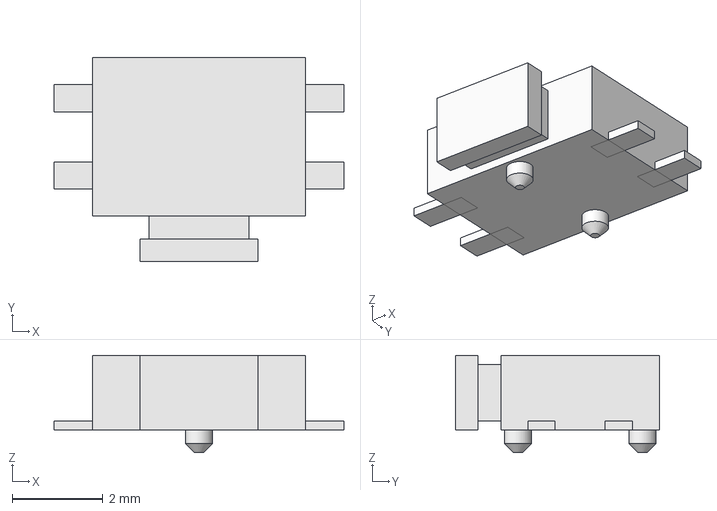
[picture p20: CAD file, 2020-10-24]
hw/case/FlightComputer_Library.3dshapes.FCStd
6.40 x 4.50 x 2.15 mm

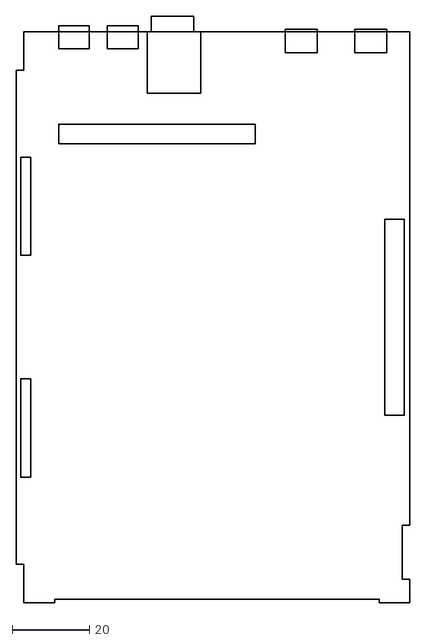
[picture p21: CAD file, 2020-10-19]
hw/case/FlightComputer-Parts.dxf
102.0 x 152.0

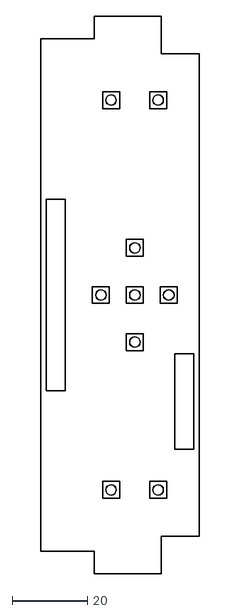
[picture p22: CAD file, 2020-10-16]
hw/case/FlightComputer-Keypad.dxf
42.0 x 148.0

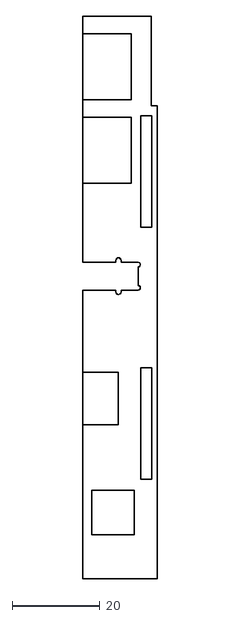
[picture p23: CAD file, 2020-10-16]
hw/case/FlightComputer-Extra-Parts.dxf
16.9 x 128.0

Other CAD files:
hw/case/FlightComputer-Extra-Outline.dxf
hw/case/FlightComputer-Keypad-Parts.dxf
hw/case/FlightComputer.dxf

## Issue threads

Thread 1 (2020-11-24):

H/W Check

akkdong, 2020-11-24:
CHARGING:
POWER-MCU: OK
POWER-BAT+: OK
POWER-PERIPH: OK
POWER-5V: OK

MCU-JTAG: OK
MCU-SERIAL: OK(?)
MCU-RESET: OK
MCU-BOOTMODE: OK
MCU-FS-USB:
MCU-HS-USB

SDRAM: OK
QSPI: ...

PMIC-COMMUNICATION
PMIC-POWER-RAIL

IMU-GY91: FAILED (PIN MISSMATCH)
IMU-GY86: N/A

GPS: OK

RPI ZERO:
  UART
  SPI
  CODEC
  SDCARD

FM-TUNER: N/A

akkdong, 2020-11-25:
GPS: OK
NOR-FLASH: Direct(OK), MemoryMapped(FAIL: NEED MORE TIME)
IMU(SPI): H/W Fault -> swapped Pin 3,4
PMIC: Communication(OK), Turn on Power Rail(FAIL)

akkdong, 2020-11-26:
PMIC: read/write register is OK but enable power rail not work properly --> it may be caused by H/W fault. i think....
IMU: spi communication work well(may be) but imu does not response (sometimes it response with dummy(?) data)
  --> change communication interface to i2c & test it!

akkdong, 2020-11-27:
Test MSC for QSPI NOR --> Device recongnize, READ & WRTE OK --> BUT Format FAILED on Windows

akkdong, 2020-11-29:
All features are OK except PMIC --> no power up : VN under current!!

akkdong, 2020-12-08:
IMU SPI tested --> CS pin swapped.  nCS1: MPU9250, nCS2: BMP280

rework PCB --> redesign PMIC, added connection between MCU & RPI(EINK-CMD, EINK_BUSY, RPI_STATUS), change 5V booster chip

Closed 2020-12-08.

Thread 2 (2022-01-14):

A Wire.requestFrom() should not be followed by a Wire.endTransmission().

Koepel, 2022-01-14:
The Wire.requestFrom() is followed by the Wire.endTransmission() in three files: EPaperPMIC.cpp, EPaperDisplayB.cpp and MS4525DO.cpp. The Wire.endTransmission() does not work together with Wire.requestFrom().

Explanation: [Common-mistakes#2](https://github.com/Koepel/How-to-use-the-Arduino-Wire-library/wiki/Common-mistakes#2)
See also my [alternative explanation of the functions of the Wire library](https://github.com/Koepel/How-to-use-the-Arduino-Wire-library/wiki/Explanation-of-the-functions-of-the-Wire-library).

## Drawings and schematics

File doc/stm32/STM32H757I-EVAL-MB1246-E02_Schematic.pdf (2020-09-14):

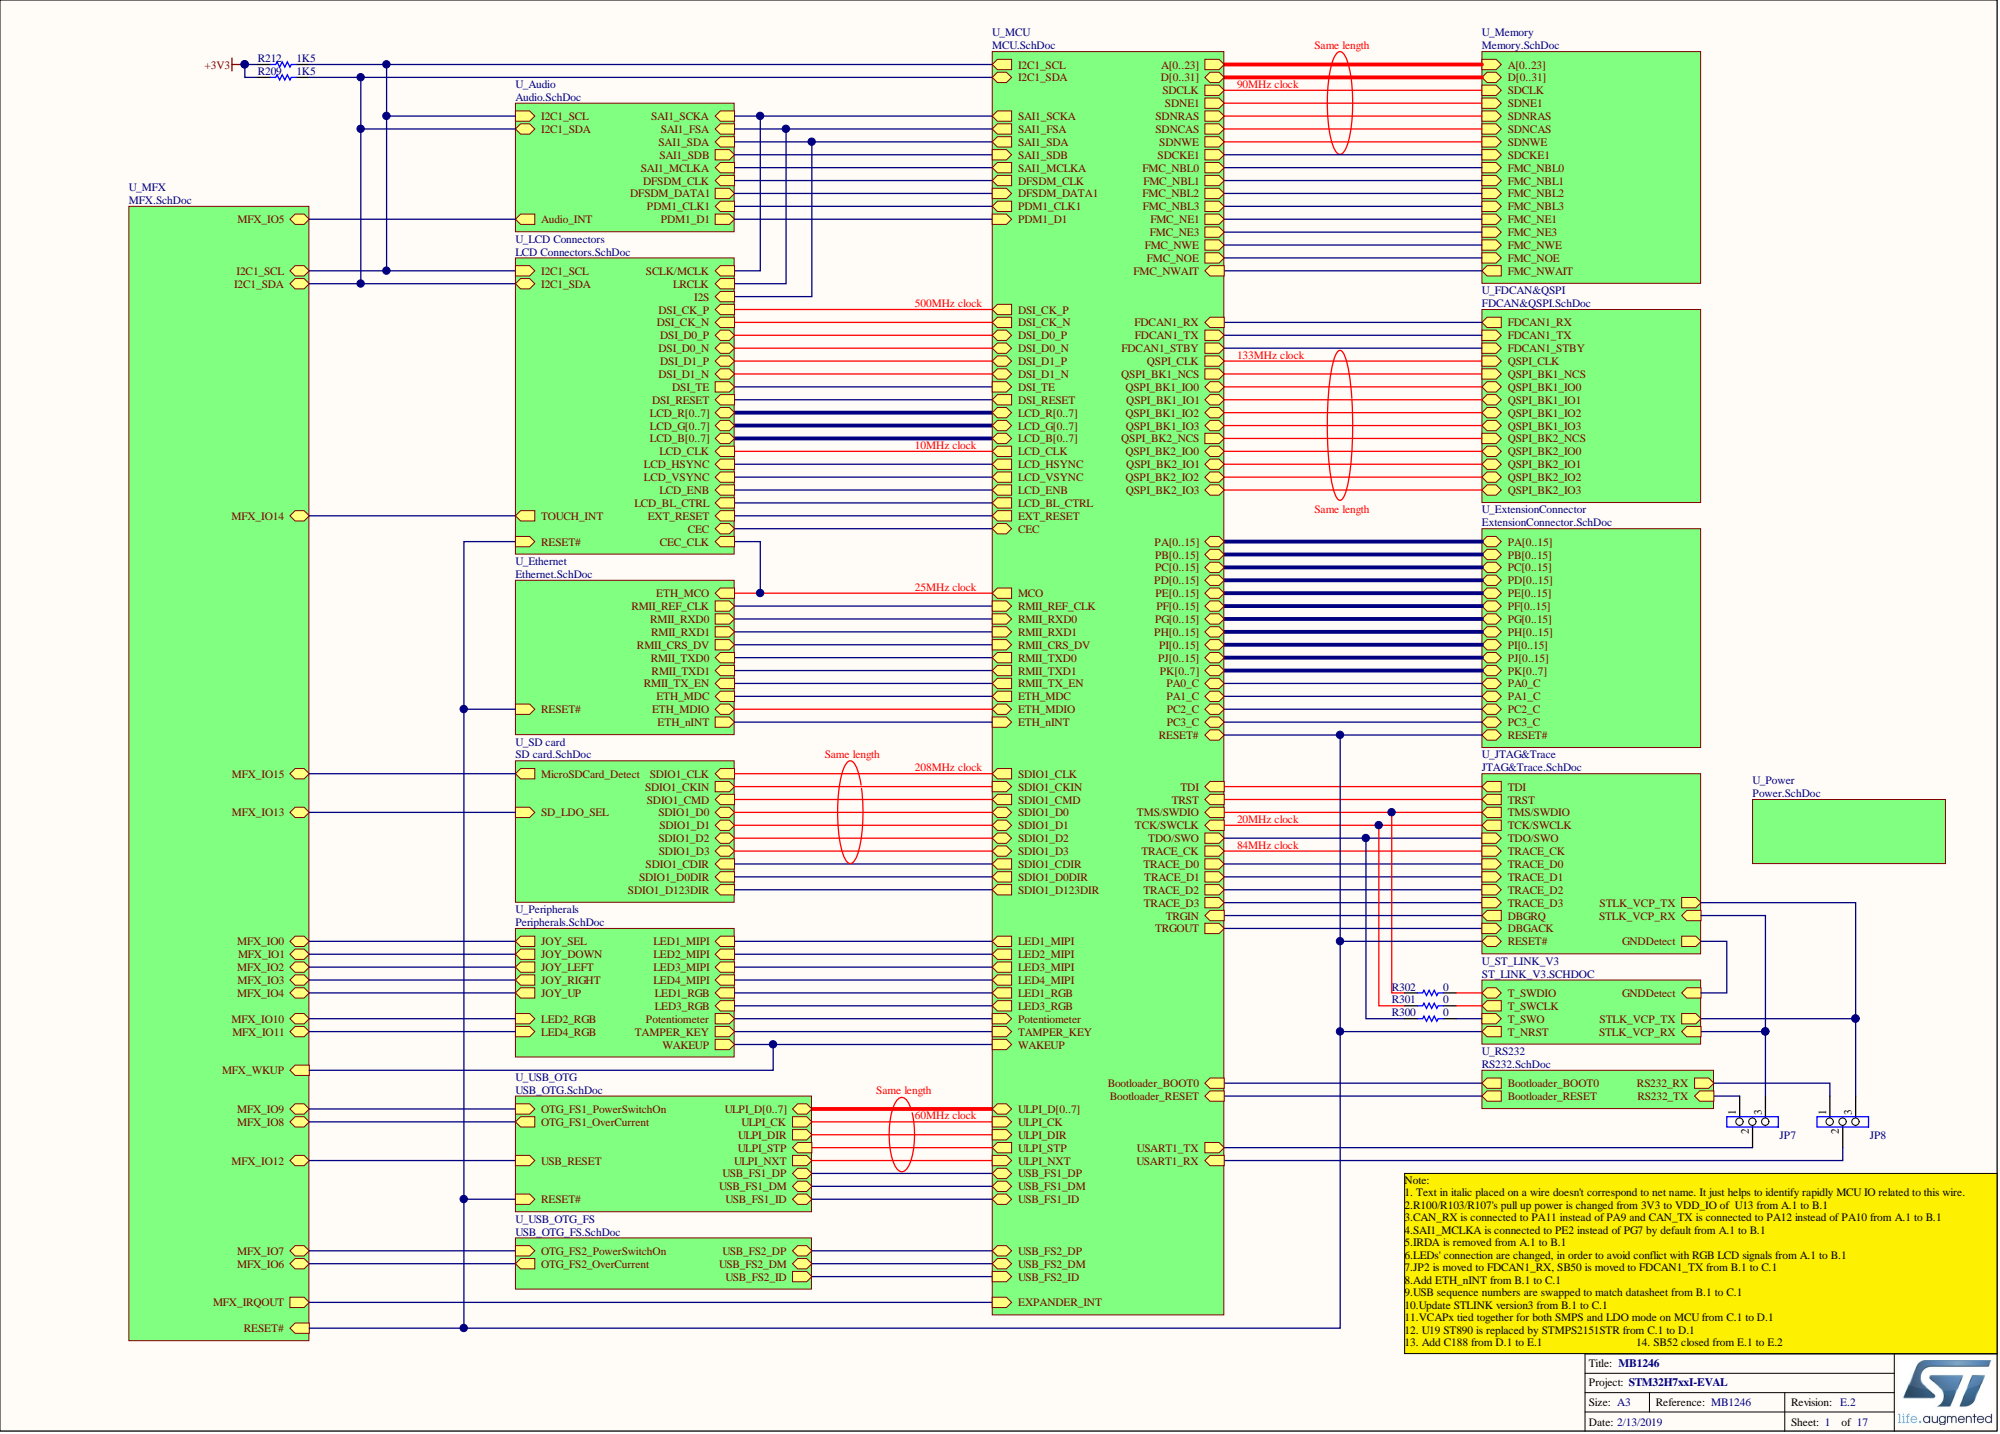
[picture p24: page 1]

Same length | U_RS232 RS232.SchDoc

U_USB_OTG USB_OTG.SchDoc

Note:
1. Text in italic placed on a wire doesn't correspond to net name. It just helps to identify rapidly MCU IO related to this wire.
2.R100/R103/R107's pull up power is changed from 3V3 to VDD_IO of U13 from A.1 to B.1
3.CAN_RX is connected to PA11 instead of PA9 and CAN_TX is connected to PA12 instead of PA10 from A.1 to B.1
4.SAI1_MCLKA is connected to PE2 instead of PG7 by default from A.1 to B.1
5.IRDA is removed from A.1 to B.1
6.LEDs' connection are changed, in order to avoid conflict with RGB LCD signals from A.1 to B.1
7.JP2 is moved to FDCAN1_RX, SB50 is moved to FDCAN1_TX from B.1 to C.1
8.Add ETH_nINT from B.1 to C.1
9.USB sequence numbers are swapped to match datasheet from B.1 to C.1
10.Update STLINK version3 from B.1 to C.1
11.VCAPx tied together for both SMPS and LDO mode on MCU from C.1 to D.1
12. U19 ST890 is replaced by STMPS2151STR from C.1 to D.1

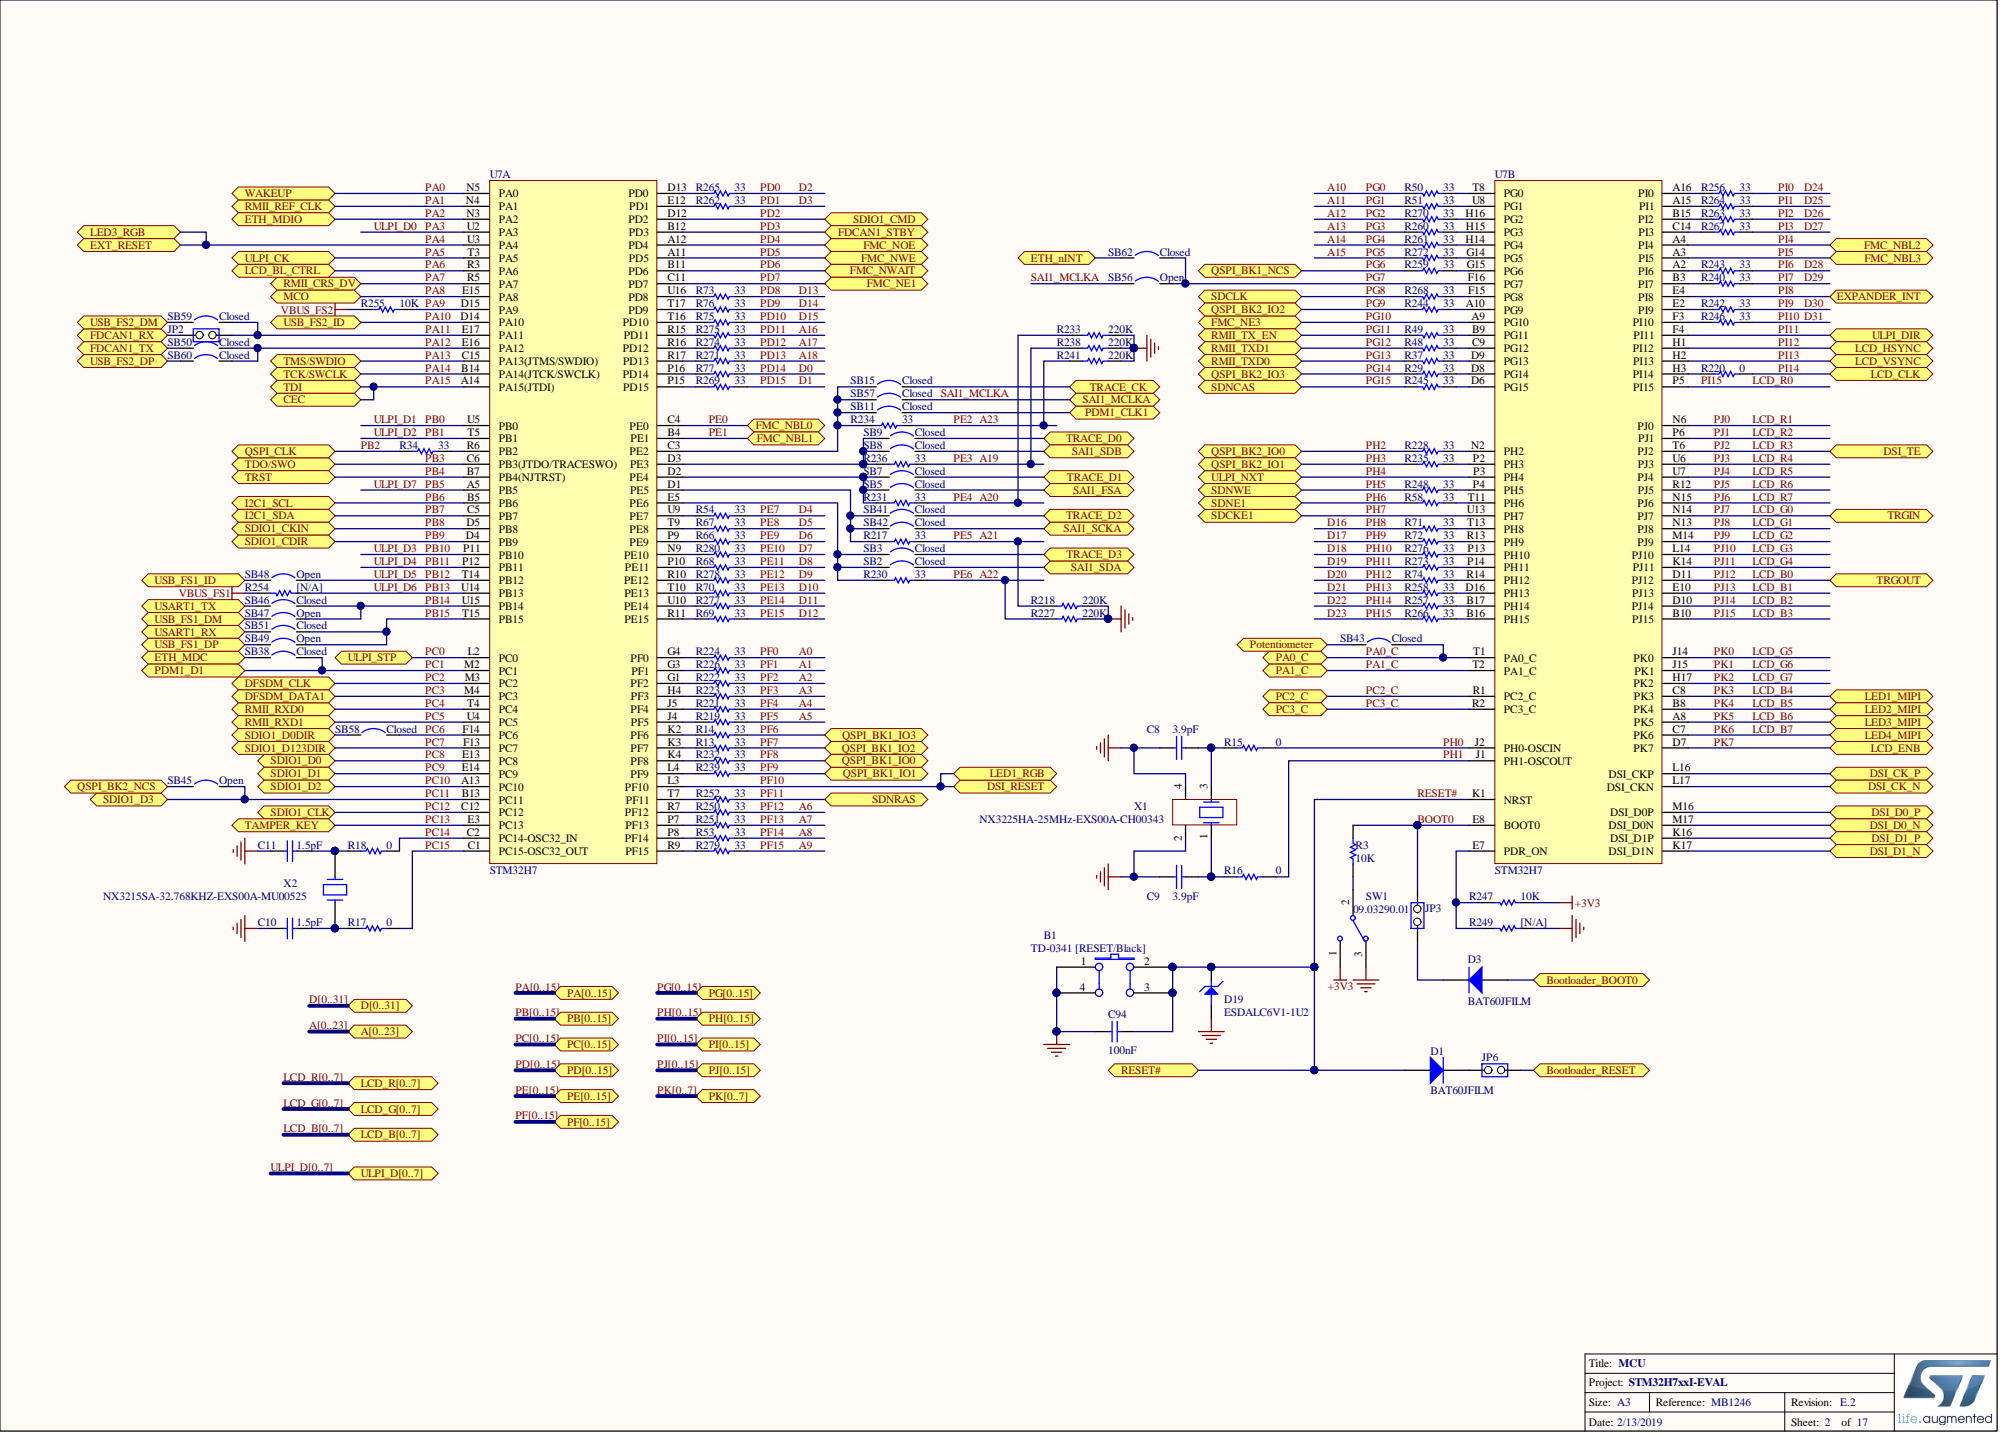
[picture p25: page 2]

BOOT0 | BOOT0 E8

PC14-OSC32_IN C2
PC15-OSC32_OUT C1

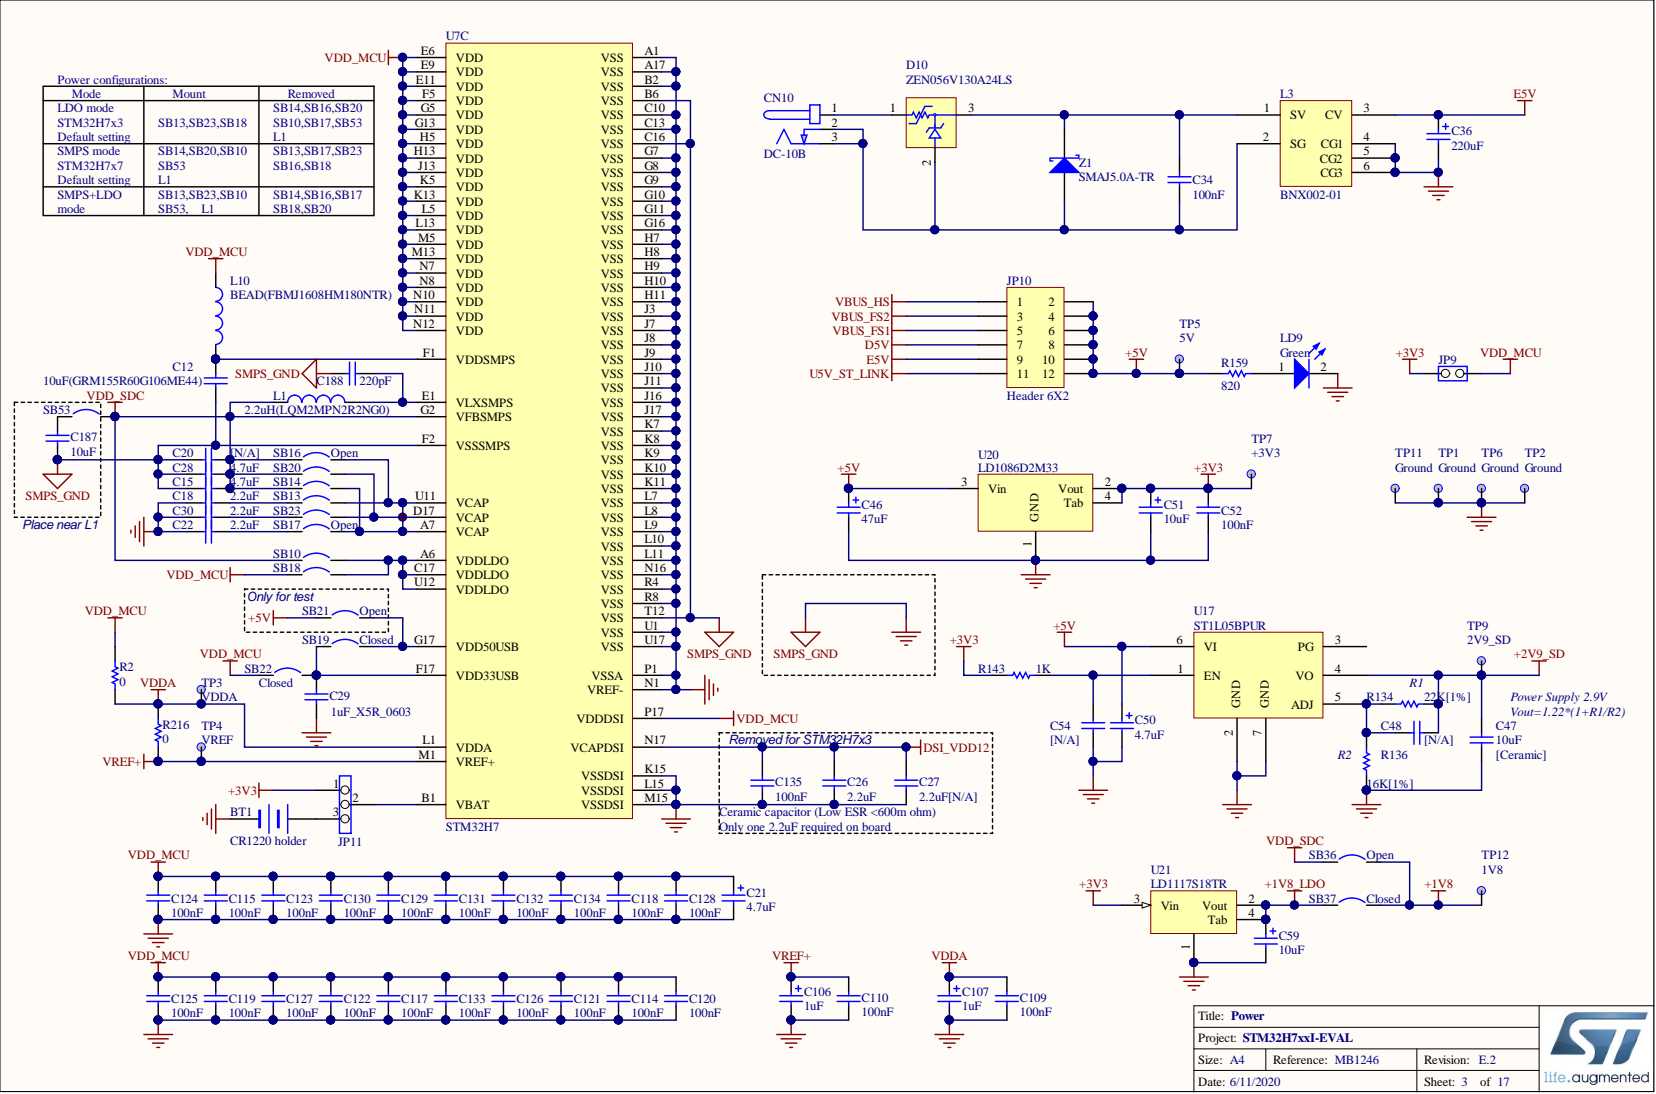
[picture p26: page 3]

VFBSMPS G2 VLXSMPS E1

VSSSMPS F2

VCAP D17

VDDLDO C17

Only for test | VDD50USB G17

Ceramic capacitor (Low ESR <600m ohm)
Only one 2.2uF required on board

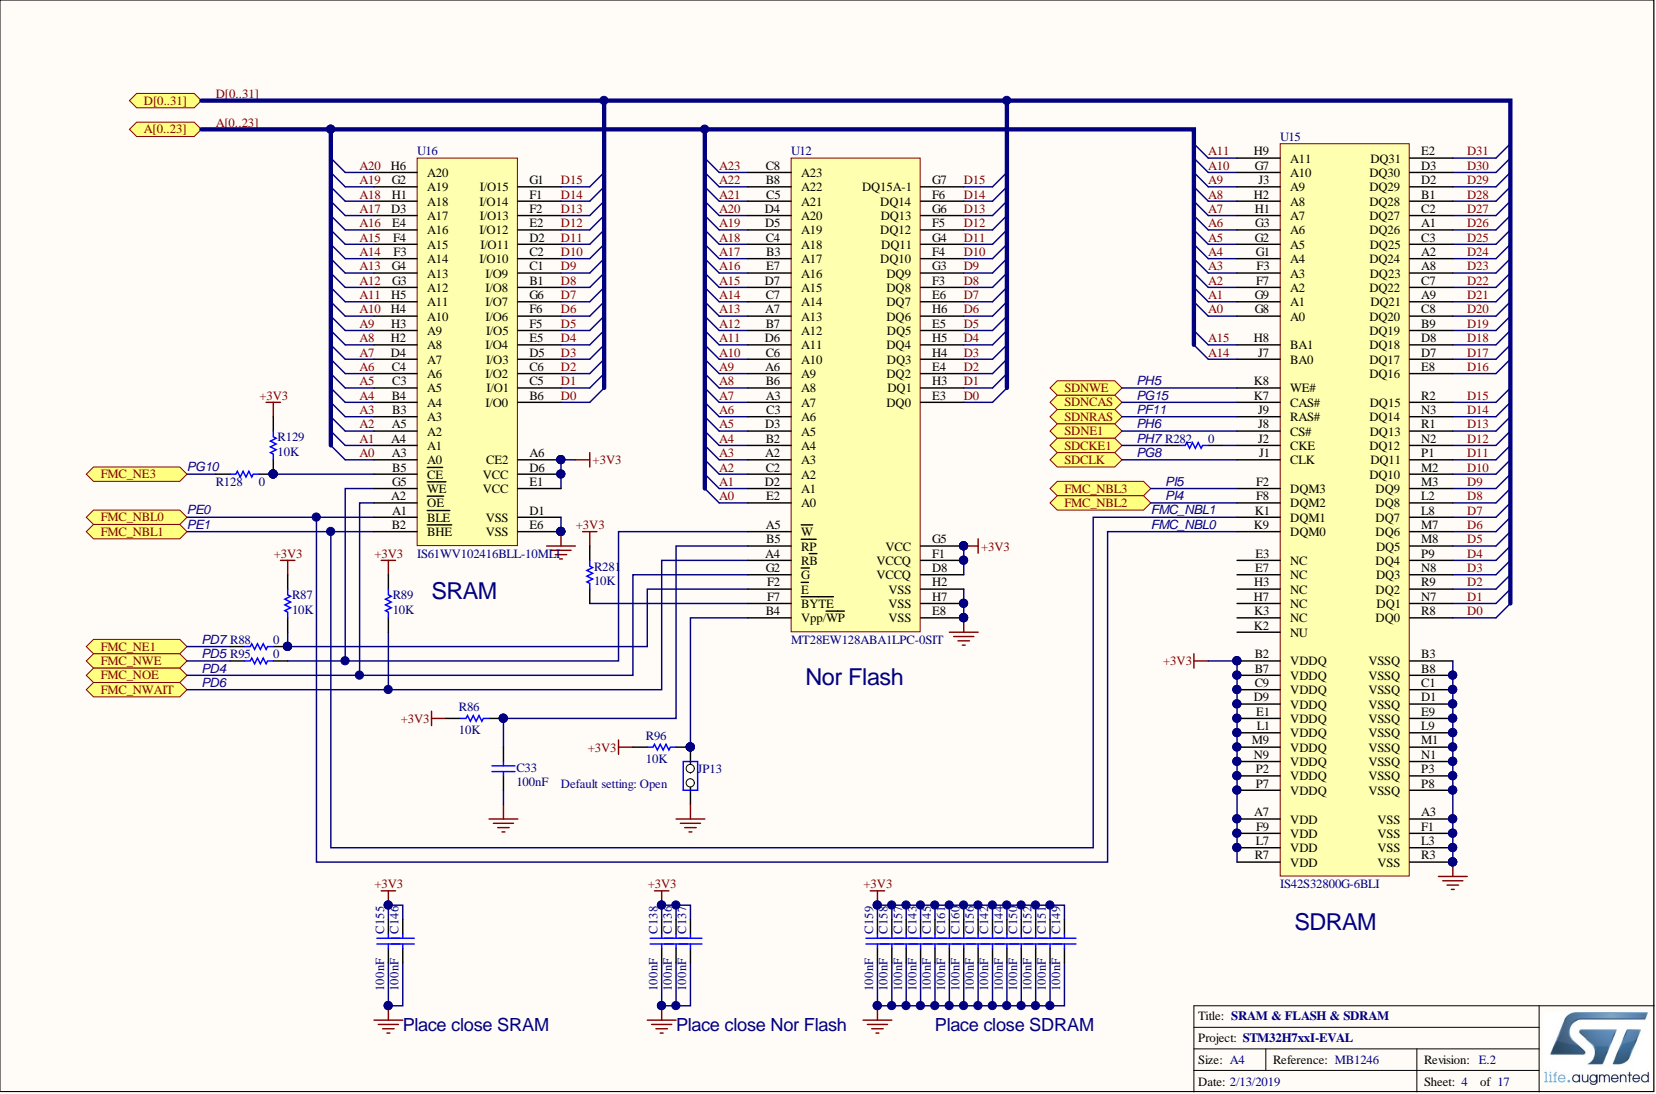
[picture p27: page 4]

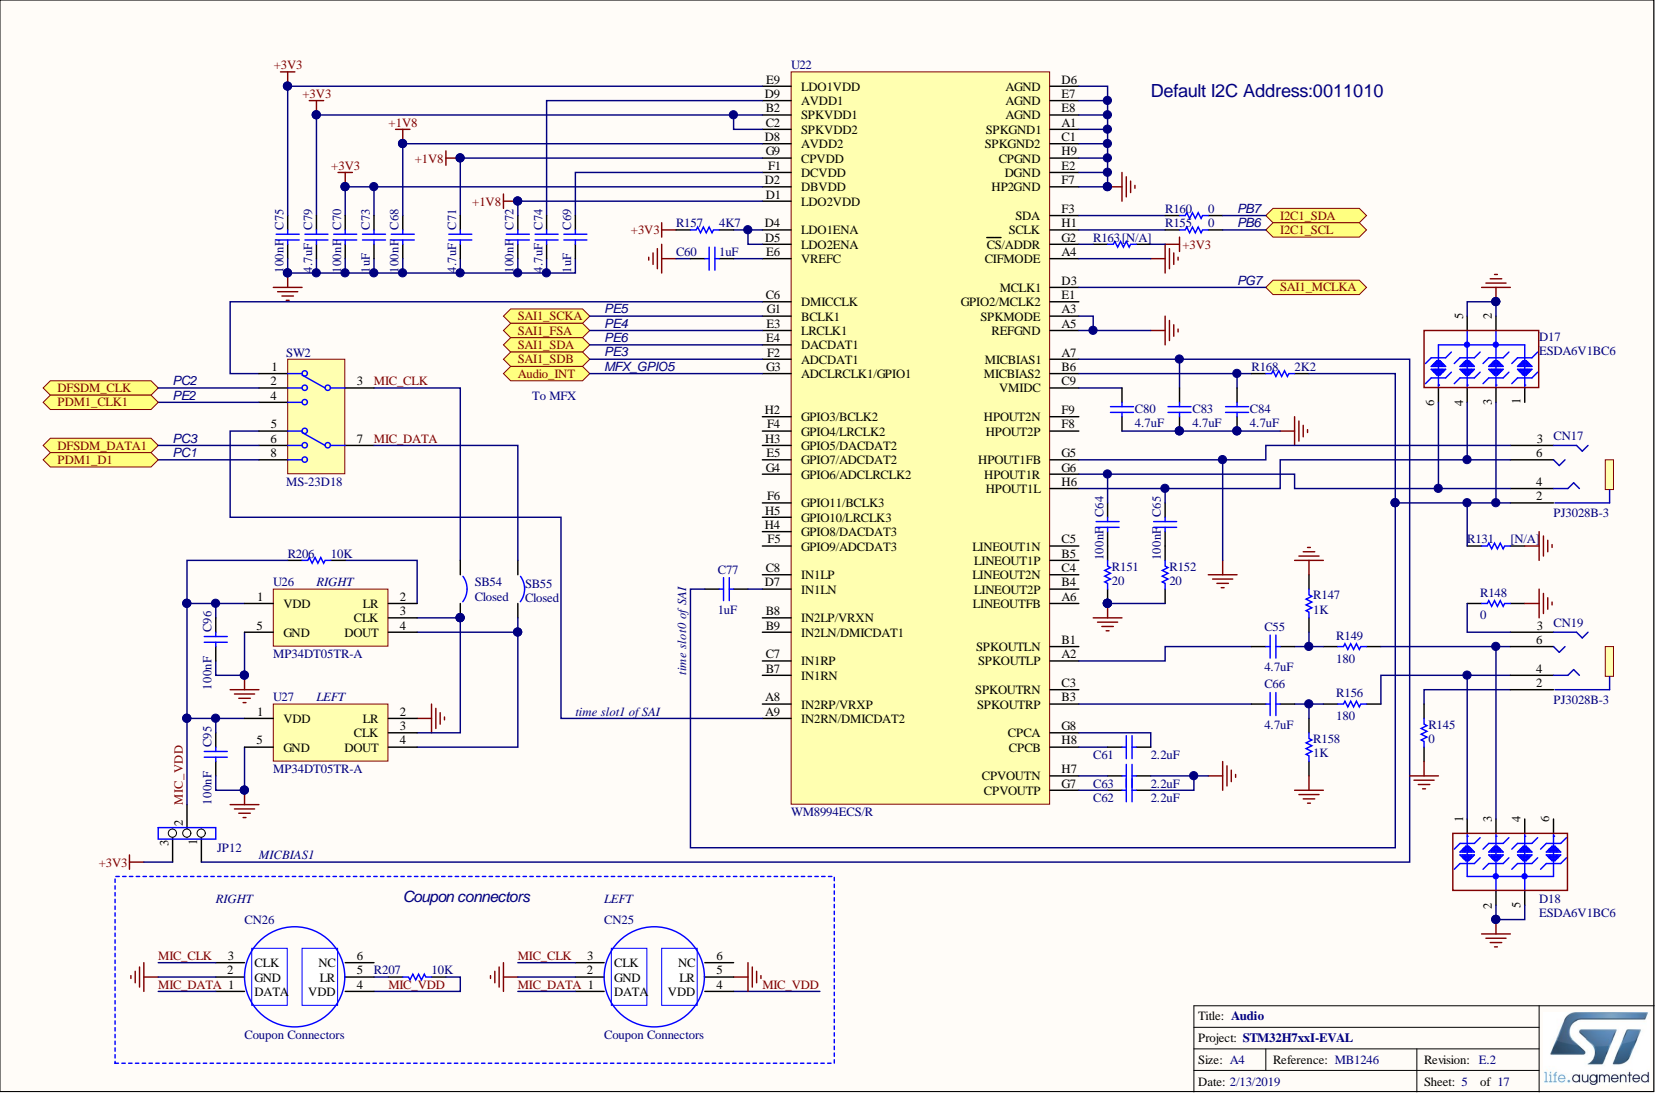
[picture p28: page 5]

DCVDD F1

LDO2VDD D1

LDO2ENA D5

C77 1uF | GPIO10/LRCLK3 H5 GPIO11/BCLK3 F6

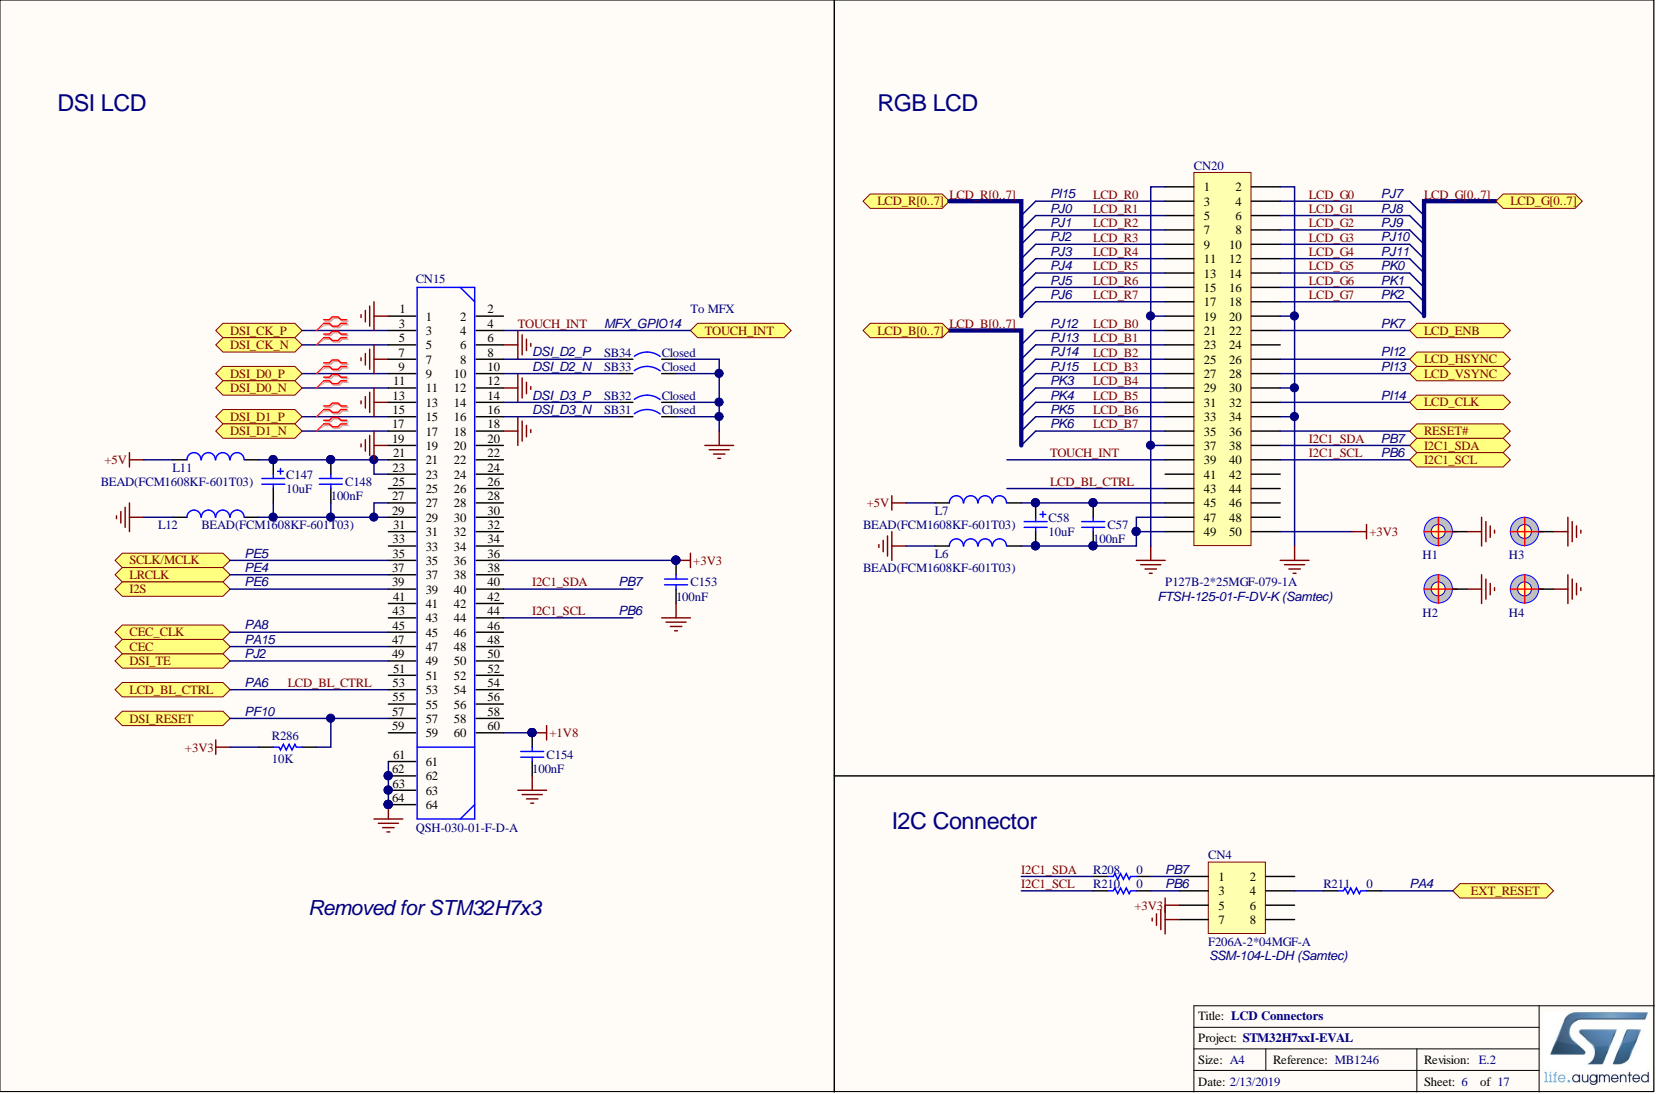
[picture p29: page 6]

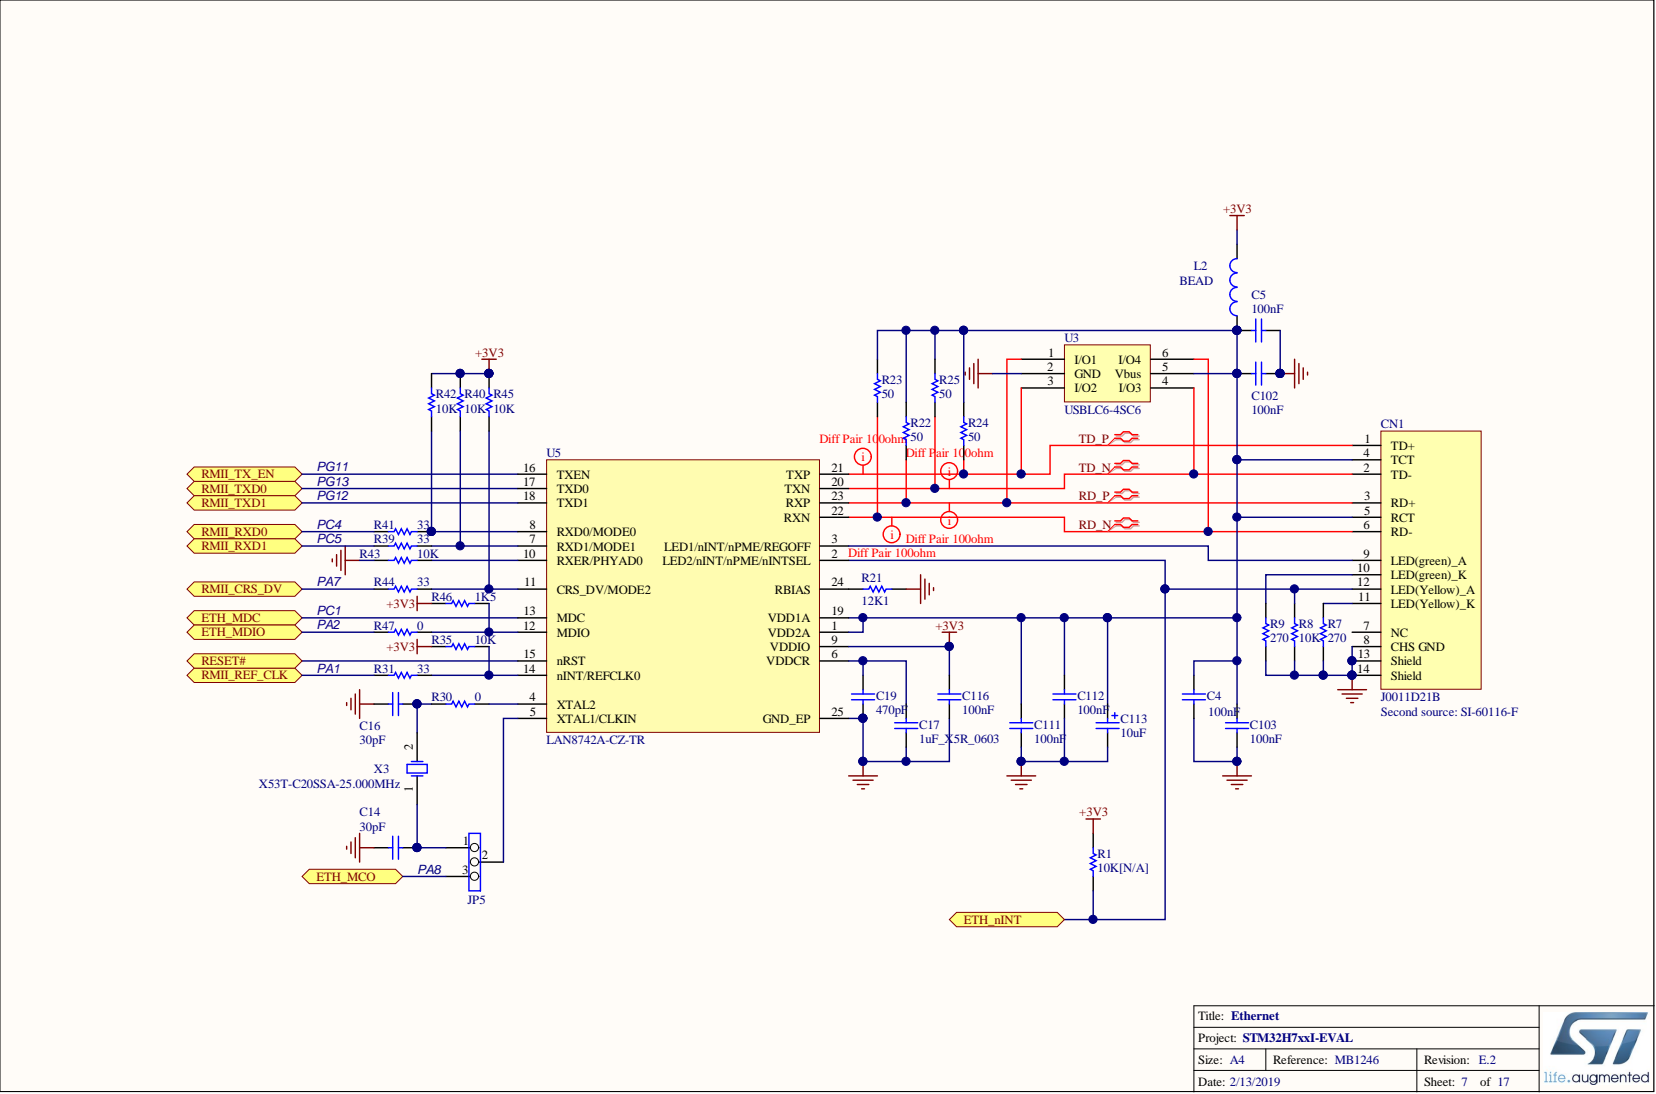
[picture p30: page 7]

i | Diff Pair 100ohm | | TCT 4

RXER/PHYAD0 10 | Diff Pair 100ohm
CRS_DV/MODE2 11 | | LED(green)_K 10

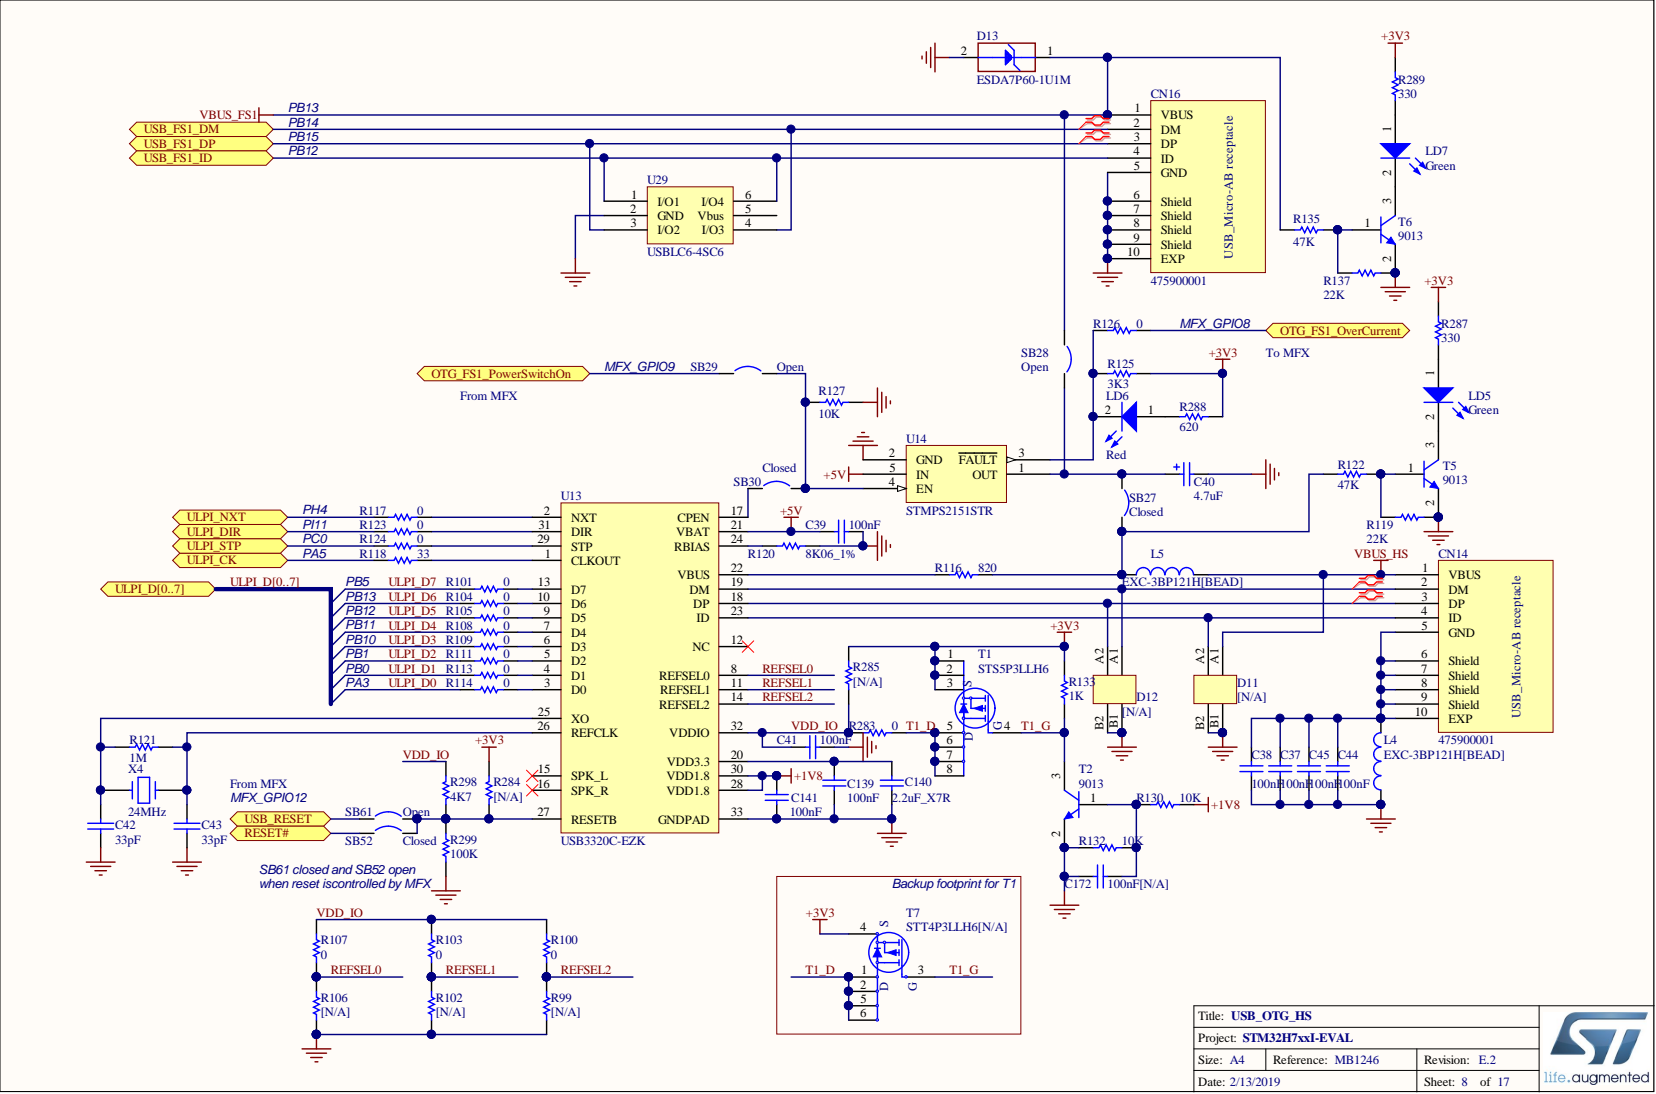
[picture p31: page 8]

PB15 | | DP 3
PB12 | | | ID 4

U29 | | GND 5

DM 2
DP 3
ID 4

+3V3 | | | GND 5

Shield 6

SB61 closed and SB52 open
when reset iscontrolled by MFX

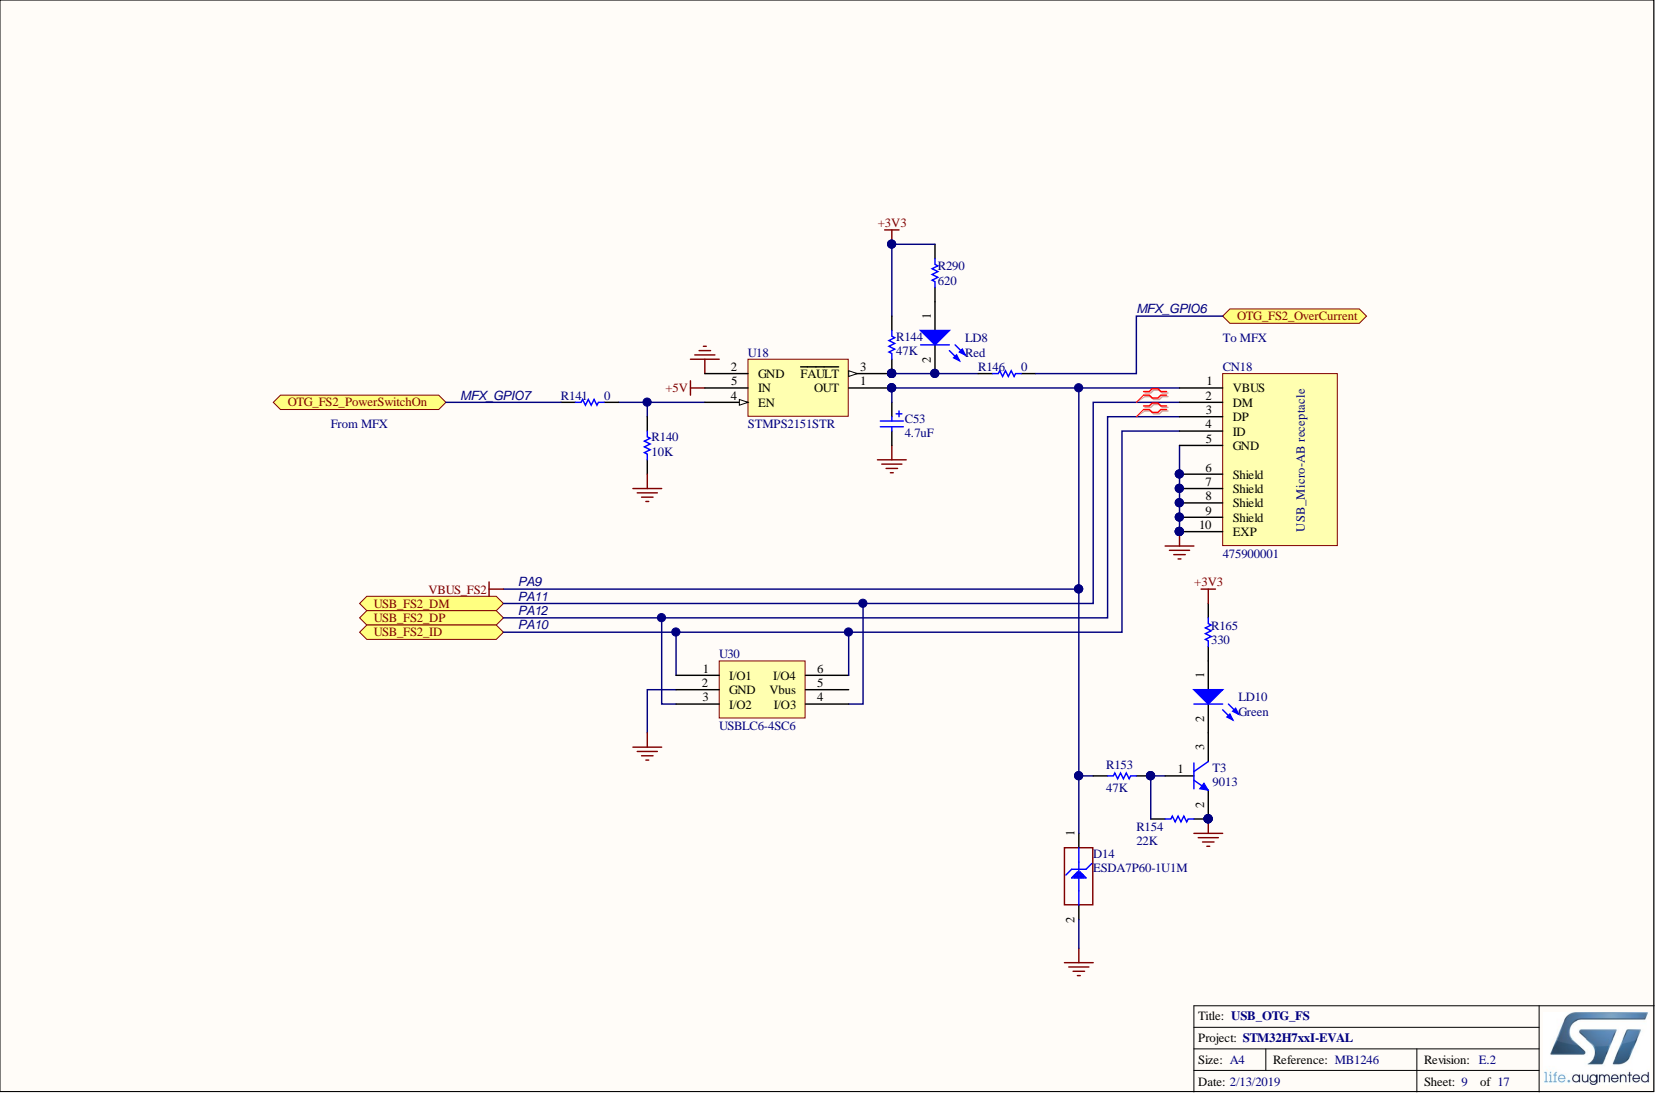
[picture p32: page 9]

C53 STMPS2151STR | ID 4

GND 5

PA11
PA12
PA10

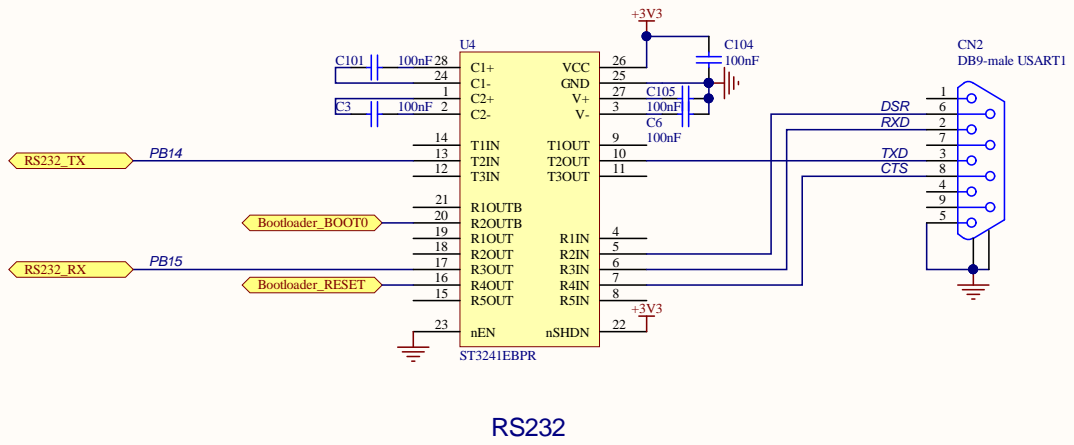
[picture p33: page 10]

2 4 | | 2
3 R1IN 4 R2IN 5 R3IN 6 R4IN 7 R5IN 8 1

2 7 C 1 | 0 5
9 | C 6 | RXD TXD CTS DSR

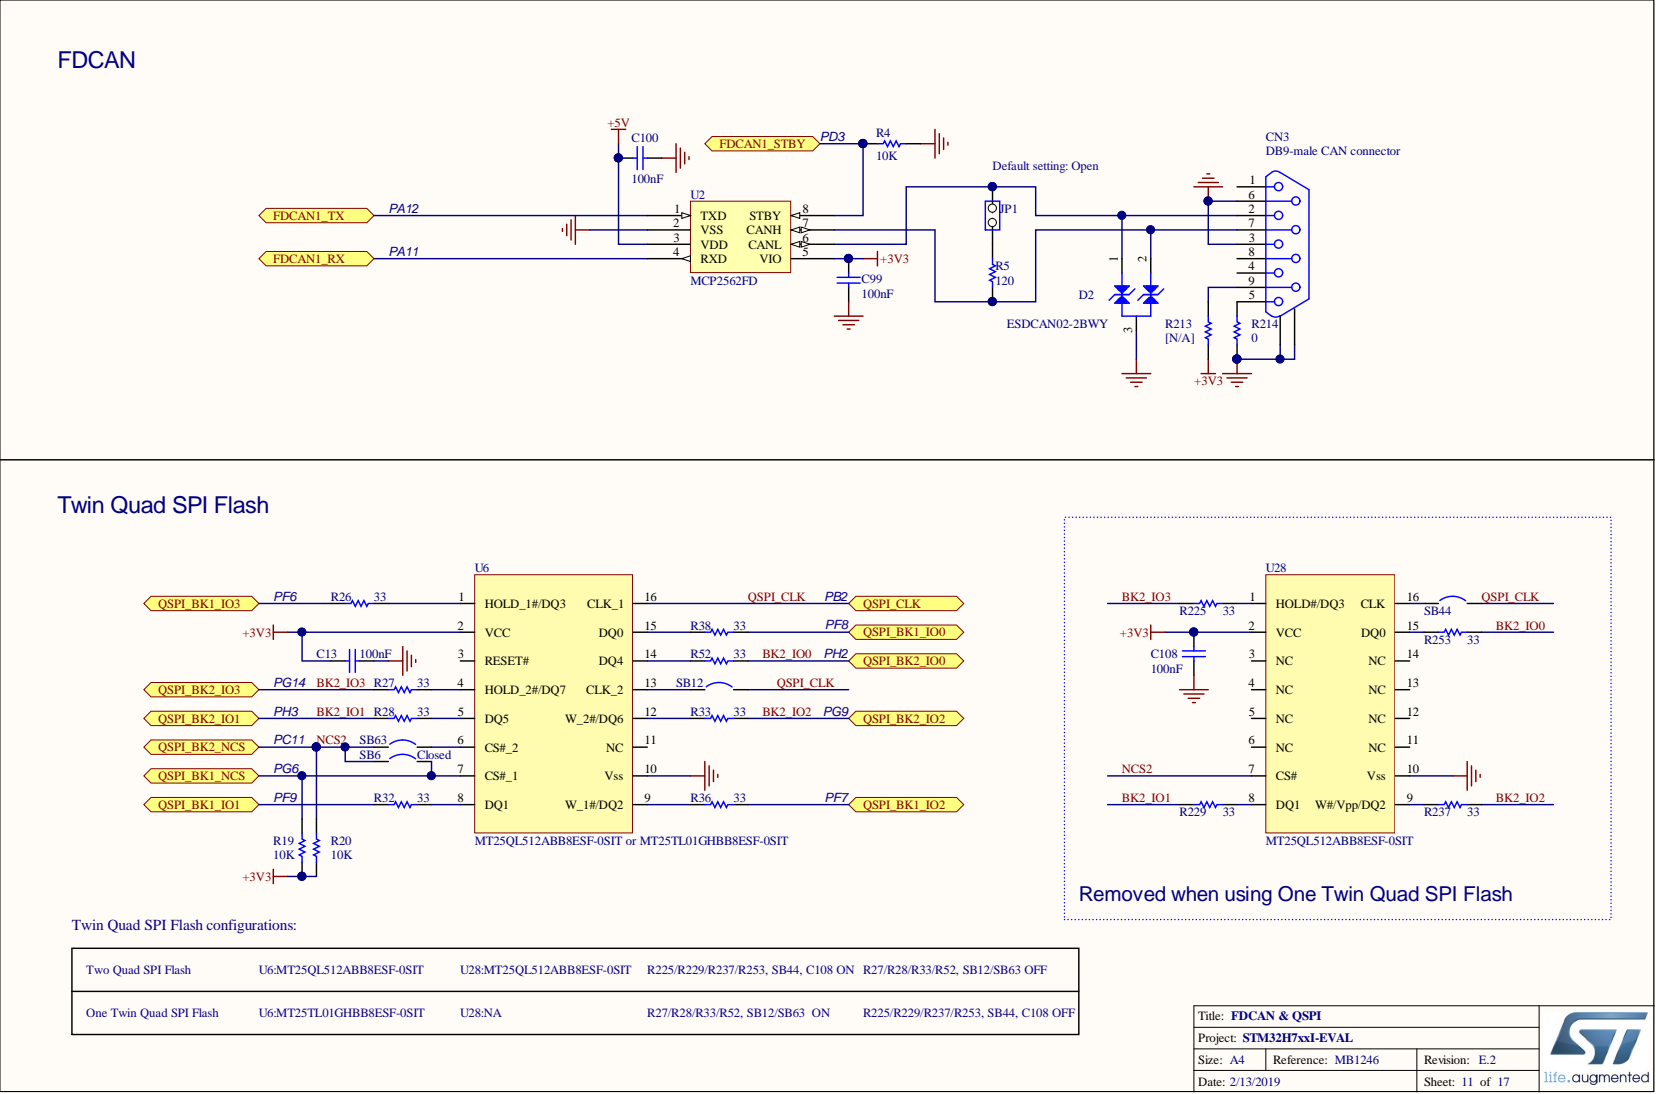
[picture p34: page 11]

Twin Quad SPI Flash

Removed when using One Twin Quad SPI Flash

Twin Quad SPI Flash configurations:

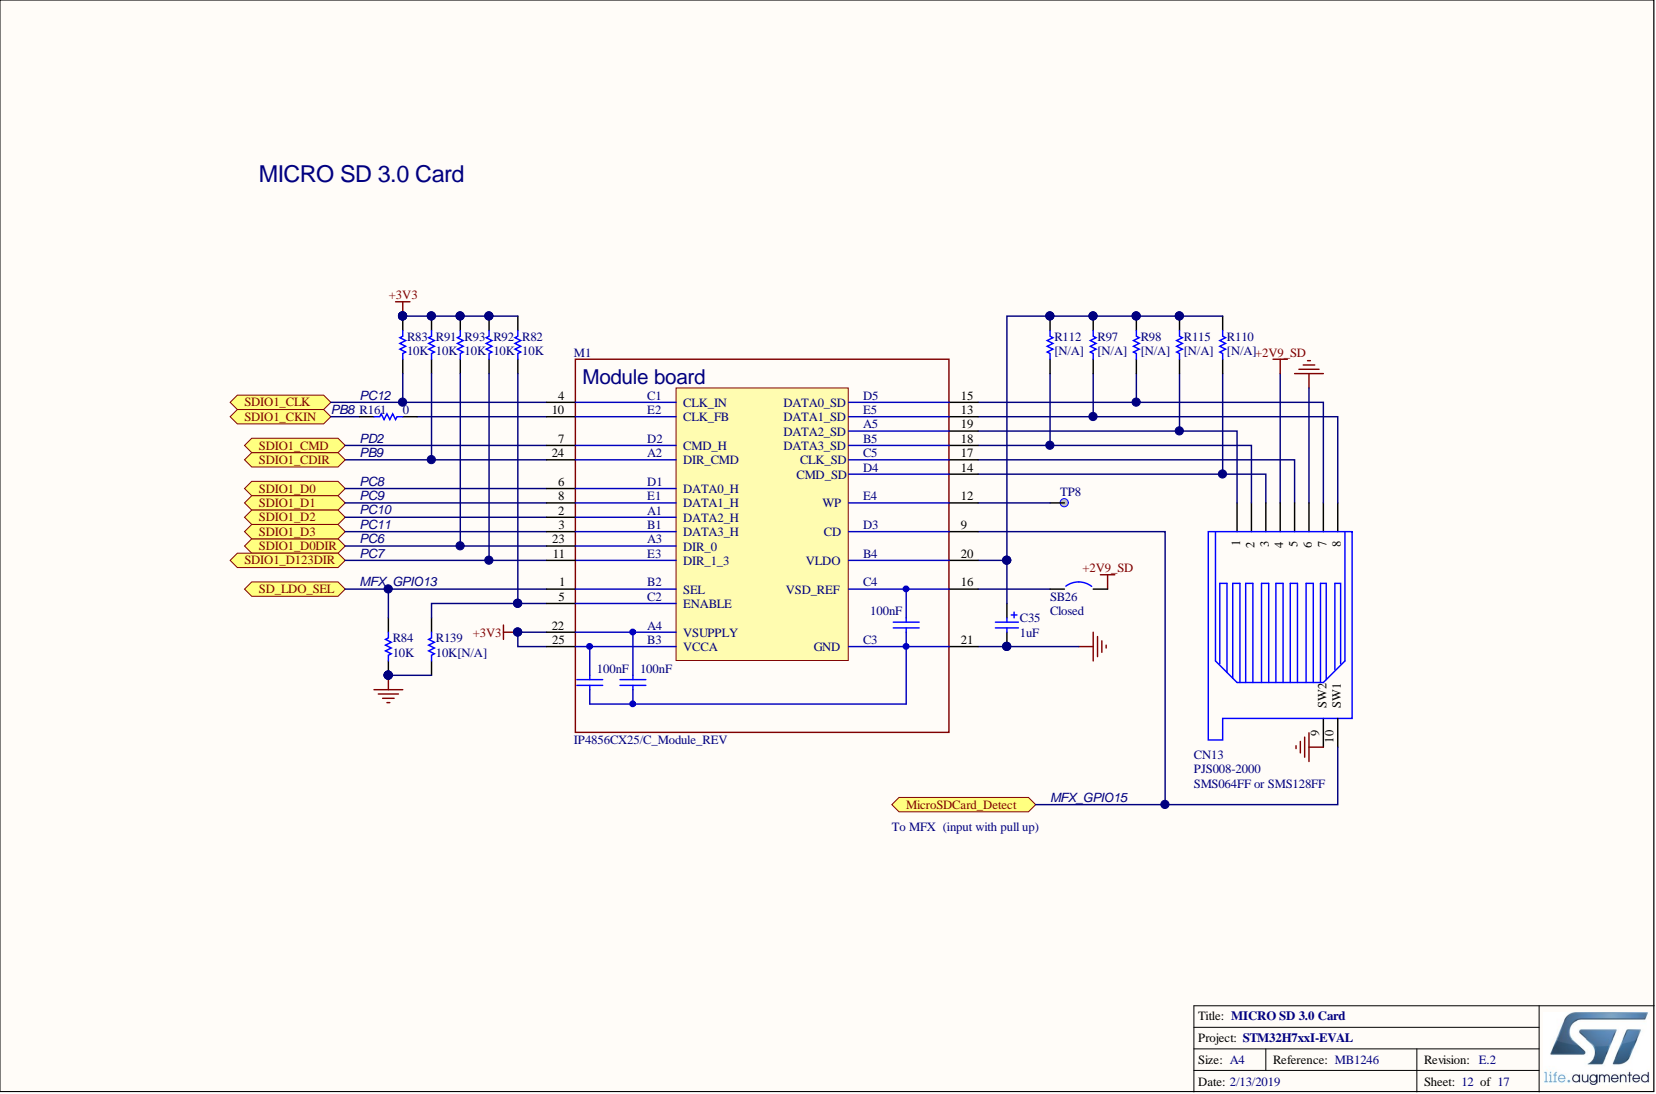
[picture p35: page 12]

Module board

7 24 6 8 2 3 23 11 1 5 | D1 E1 A1 B1 | DIR_CMD A2 CMD_H D2 DATA3_H A3 DIR_1_3 E3 ENABLE C2 SEL B2 | A5 | 19

B5 | 18
C5 | 17
D4 | 14

B4 | 20
C4 | 16 21 | +2V9_SD

VCCA B3 VSUPPLY A4

To MFX (input with pull up)


Two pin header for external analog input

Close to MCU on PCB

DWON 3
LEFT 1
RIGHT 4
UP 6



STLK_SWCLK | STLK_SWCLK/PA14 A14

USB_DEV_HS_N/PB14 R14 | | T_SWDIO

OSC_IN/PH0 G1 | STLK_VCP_RX | 10K

R175 | | | OSC_OUT/PH1 H1 | STLK_VCP_TX

VSS M9 VSS G12 VSS D8 VSS D7 VSS F2 VSS H12 VSS D9 VSS F6

VDD J13
VDD H13
VDD C8
VDD C7
VDD F3 | C174 C183 C170
VDD J12
VDD C9
VDDA R1
VREF+ P1

Impedance Constraint [Min = 85.00 Max = 95.00 ]
Matched Net Lengths [Tolerance = 0.2mm]

Ceramic capacitor (Low ESR)

ESDA7P60-1U1M
Closed to Pin1 of Mirco-B



PA14
PB3
PA15
PB4

STDC14 Receiver
T_VCC must be to connected to VDD_MCU of the Target

5 6 | T_TCK/SWCLK
7 8 | T_TDO/SWO

T_TDI

PE4
PE3
PE2

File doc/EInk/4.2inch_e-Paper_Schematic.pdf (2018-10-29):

GND | BS | 3-line SPI | 4-line SPI GND


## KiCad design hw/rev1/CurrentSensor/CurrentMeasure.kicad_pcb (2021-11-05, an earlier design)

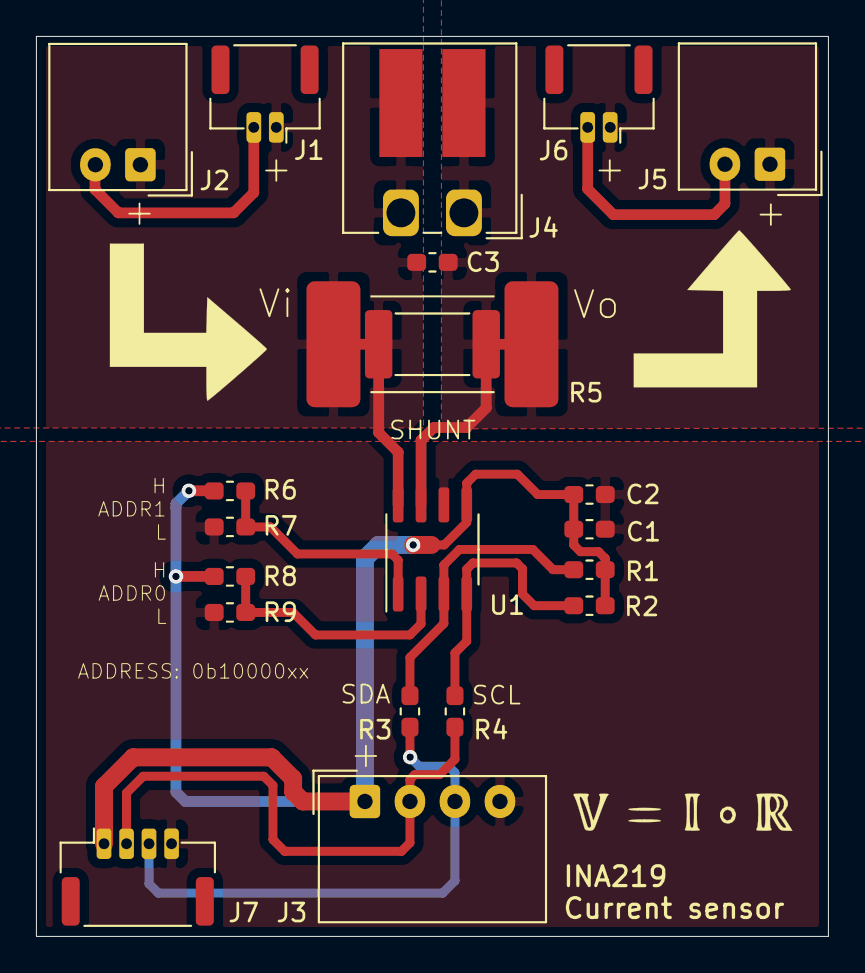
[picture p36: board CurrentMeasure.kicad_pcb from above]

Board: 2 copper layers, 44.0 x 50.0 mm, 21 parts (0 on the bottom side), 10 nets.

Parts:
C1, C3: 0.1uF; C_0603_1608Metric_Pad1.05x0.95mm_HandSolder
C2: 10Uf; C_0603_1608Metric_Pad1.05x0.95mm_HandSolder
J1, J6: Conn_01x02; Molex_CLIK-Mate_502386-0270_1x02-1MP_P1.25mm_Horizontal
J2, J5: Conn_01x02; Molex_SPOX_5268-02A_1x02_P2.50mm_Horizontal
J3: Conn_01x04; Molex_SPOX_5268-04A_1x04_P2.50mm_Horizontal
J4: Conn_01x02; Wago_734-162_1x02_P3.50mm_Horizontal
J7: Conn_01x04; Molex_CLIK-Mate_502386-0470_1x04-1MP_P1.25mm_Horizontal
R1, R2: 10K; R_0603_1608Metric_Pad1.05x0.95mm_HandSolder
R3, R4: 33R; R_0603_1608Metric_Pad1.05x0.95mm_HandSolder
R5: 2mR; R_2512_6332Metric_Pad1.52x3.35mm_HandSolder
R6, R7, R8, R9: 100R; R_0603_1608Metric_Pad1.05x0.95mm_HandSolder
R10: N/C; R_4527
U1: INA219AxD; SOIC-8_3.9x4.9mm_P1.27mm

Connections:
/VIN: C3.1, J1.1, J2.1, J4.2, R5.1, R10.1, U1.8
/VOUT: C3.2, J4.1, J5.1, J6.1, R5.2, R10.2, U1.7
GND: C1.2, C2.2, J1.2, J2.2, J3.4, J5.2, J6.2, J7.4, R7.2, R9.2, U1.6
unnamed: J3.2, J7.2, R4.1
unnamed: J3.3, J7.3, R3.1
unnamed: R1.2, R3.2, U1.3
unnamed: R2.2, R4.2, U1.4
unnamed: R6.1, R7.1, U1.1
unnamed: R8.1, R9.1, U1.2
VCC: C1.1, C2.1, J3.1, J7.1, R1.1, R2.1, R6.2, R8.2, U1.5

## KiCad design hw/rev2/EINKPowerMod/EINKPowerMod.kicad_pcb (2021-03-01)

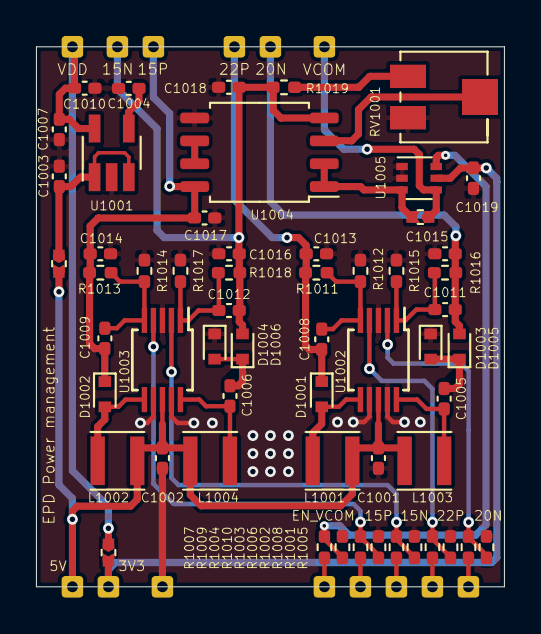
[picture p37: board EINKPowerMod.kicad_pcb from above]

Board: 2 copper layers, 26.0 x 30.0 mm, 71 parts (0 on the bottom side), 35 nets.

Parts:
C1001, C1002: 4.7uF; C_0402_1005Metric_Pad0.74x0.62mm_HandSolder
C1003, C1004, C1013, C1014, C1015, C1016: 1uF; C_0402_1005Metric_Pad0.74x0.62mm_HandSolder
C1005, C1006, C1007, C1017, C1018, C1019: 0.1uF; C_0402_1005Metric_Pad0.74x0.62mm_HandSolder
C1008, C1009: 4.7pF; C_0402_1005Metric_Pad0.74x0.62mm_HandSolder
C1010: 10uF; C_0402_1005Metric_Pad0.74x0.62mm_HandSolder
C1011, C1012: 100pF; C_0402_1005Metric_Pad0.74x0.62mm_HandSolder
D1001, D1002, D1003, D1004, D1005, D1006: 1N4001; D_SOD-523
J1001, J1002, J1003, J1004, J1005, J1006, J1007, J1008, J1009, J1010, J1011, J1012, J1013, J1014: Conn_01x01; PMIC_HOLE
JP1001: Close; Jumper_0402_1005Metric
JP1002, JP1003: Open; Jumper_0402_1005Metric
L1001, L1002, L1003, L1004: 22uH; L_Taiyo-Yuden_MD-3030
R1001, R1002, R1003, R1004, R1007: 33R; R_0402_1005Metric_Pad0.72x0.64mm_HandSolder
R1005, R1006, R1008, R1009, R1010: 100K; R_0402_1005Metric_Pad0.72x0.64mm_HandSolder
R1011: 2M; R_0402_1005Metric_Pad0.72x0.64mm_HandSolder
R1012: 120K; R_0402_1005Metric_Pad0.72x0.64mm_HandSolder
R1013: 300K; R_0402_1005Metric_Pad0.72x0.64mm_HandSolder
R1014: 27K; R_0402_1005Metric_Pad0.72x0.64mm_HandSolder
R1015: 39K; R_0402_1005Metric_Pad0.72x0.64mm_HandSolder
R1016: 560K; R_0402_1005Metric_Pad0.72x0.64mm_HandSolder
R1017: 10K; R_0402_1005Metric_Pad0.72x0.64mm_HandSolder
R1018: 110K; R_0402_1005Metric_Pad0.72x0.64mm_HandSolder
R1019: 200K; R_0402_1005Metric_Pad0.72x0.64mm_HandSolder
RV1001: 100K; Potentiometer_Bourns_3214J_Horizontal
U1001: XC6220B331MR-G; SOT-23-5_HandSoldering
U1002, U1003: LT1945; MSOP-10_3x3mm_P0.5mm
U1004: LM358; SOIC-8_5.275x5.275mm_P1.27mm
U1005: NC7SB3157P6X; SOT-363_SC-70-6

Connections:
+15V: C1009.1, C1014.1, C1017.1, D1002.1, J1012.1, R1013.2, U1004.8
+22V: C1008.1, C1013.1, D1001.1, J1009.1, R1011.2
-15V: C1012.2, C1016.1, C1018.2, D1006.2, J1013.1, R1018.2, R1019.2, U1004.4
-20V: C1011.2, C1015.1, D1005.2, J1010.1, R1016.2
/EN_15N: J1005.1, R1003.2
/EN_15P: J1004.1, R1004.2
/EN_20N: J1007.1, R1001.2
/EN_22P: J1006.1, R1002.2
/EN_VCOM: J1008.1, R1007.1
GND: C1001.2, C1002.2, C1003.1, C1004.1, C1007.1, C1010.2, C1013.2, C1014.2, C1015.2, C1016.2, C1017.2, C1018.1, C1019.1, D1003.1, D1004.1, J1003.1, R1005.2, R1006.2, R1008.2, R1009.2, R1010.2, R1012.2, R1014.2, R1015.2, R1017.2, RV1001.1, U1001.2, U1002.3, U1002.7, U1002.9, U1003.3, U1003.7, U1003.9, U1004.5, U1005.1, U1005.2
unnamed: C1003.2, JP1001.2, U1001.1, U1001.3
unnamed: C1004.2, U1001.4
unnamed: C1005.1, D1003.2, D1005.1
unnamed: C1005.2, L1003.1, U1002.10
unnamed: C1006.1, D1004.2, D1006.1
unnamed: C1006.2, L1004.1, U1003.10
unnamed: C1008.2, R1011.1, R1012.1, U1002.5
unnamed: C1009.2, R1013.1, R1014.1, U1003.5
unnamed: C1011.1, R1015.1, R1016.1, U1002.1
unnamed: C1012.1, R1017.1, R1018.1, U1003.1
unnamed: D1001.2, L1001.2, U1002.6
unnamed: D1002.2, L1002.2, U1003.6
unnamed: JP1003.1, U1004.1, U1004.2, U1005.3
unnamed: R1001.1, R1005.1, U1002.2
unnamed: R1002.1, R1008.1, U1002.4
unnamed: R1003.1, R1006.1, U1003.2
unnamed: R1004.1, R1010.1, U1003.4
unnamed: R1007.2, R1009.1, U1005.6
unnamed: R1019.1, RV1001.3
unnamed: RV1001.2, U1004.3
unnamed: U1004.6, U1004.7
VCC_3V3: C1019.2, J1002.1, JP1002.1, U1005.5
VCC_5V: C1001.1, C1002.1, J1001.1, JP1001.1, L1001.1, L1002.1, L1003.2, L1004.2, U1002.8, U1003.8
VCC_EINK: C1007.2, C1010.1, J1014.1, JP1002.2, U1001.5
VCOM: J1011.1, JP1003.2, U1005.4

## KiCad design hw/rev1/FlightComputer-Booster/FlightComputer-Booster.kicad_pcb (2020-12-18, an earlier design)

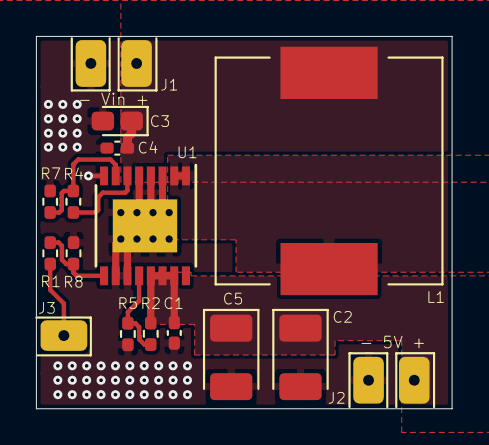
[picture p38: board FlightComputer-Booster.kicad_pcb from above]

Board: 2 copper layers, 23.1 x 20.7 mm, 16 parts (0 on the bottom side), 8 nets.

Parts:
C1: 2.2uF; C_0402_1005Metric_Pad0.74x0.62mm_HandSolder
C2, C5: 100uF; CP_EIA-3528-15_AVX-H_Pad1.50x2.35mm_HandSolder
C3: 10uF; CP_EIA-1608-08_AVX-J_Pad1.25x1.05mm_HandSolder
C4: 0.1uF; C_0402_1005Metric_Pad0.74x0.62mm_HandSolder
J1, J2: Conn_01x02; PinHeader_1x02_P2.54mm_Vertical
J3: Conn_01x01; PinHeader_1x01_P2.54mm_Vertical
L1: 68uH w/2A; L_12x12mm_H6mm
R1: 33R; R_0402_1005Metric_Pad0.72x0.64mm_HandSolder
R2, R4: 1.87M; R_0402_1005Metric_Pad0.72x0.64mm_HandSolder
R5, R7: 340K; R_0402_1005Metric_Pad0.72x0.64mm_HandSolder
R8: 100K; R_0402_1005Metric_Pad0.72x0.64mm_HandSolder
U1: TPS61032PWR; TSSOP-16-1EP_4.4x5mm_P0.65mm

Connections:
/EN: R1.2, R8.1, U1.9
/FB: R2.2, R5.1, U1.12
/LBI: R4.2, R7.1, U1.7
/SW: L1.2, U1.1, U1.2
GND: C1.2, C2.2, C3.2, C4.2, C5.2, J1.2, J2.2, R5.2, R7.2, R8.2, U1.3, U1.4, U1.5, U1.8, U1.10, U1.11, U1.17
unnamed: J3.1, R1.1
VCC_5V: C1.1, C2.1, C5.1, J2.1, R2.1, U1.13, U1.14, U1.15
VCC_BAT: C3.1, C4.1, J1.1, L1.1, R4.1, U1.6

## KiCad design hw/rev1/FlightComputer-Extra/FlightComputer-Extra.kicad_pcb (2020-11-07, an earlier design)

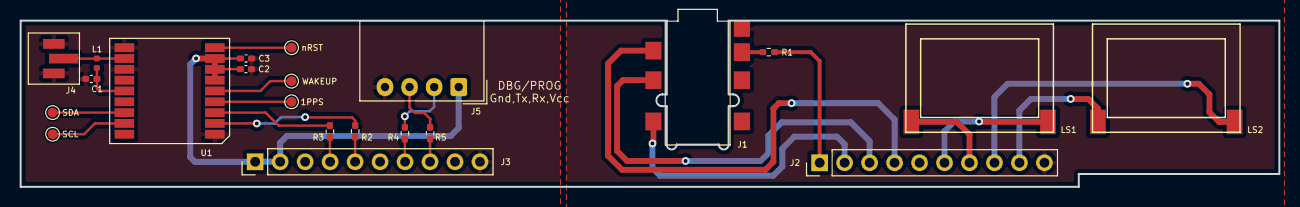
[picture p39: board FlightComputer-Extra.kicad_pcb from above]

Board: 2 copper layers, 128.0 x 16.9 mm, 22 parts (0 on the bottom side), 27 nets.

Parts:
C1: 22pF; C_0402_1005Metric_Pad0.74x0.62mm_HandSolder
C2: 0.1uF; C_0402_1005Metric_Pad0.74x0.62mm_HandSolder
C3: 1uF; C_0402_1005Metric_Pad0.74x0.62mm_HandSolder
J1: SJ-43617-SMT
J2, J3: Conn_01x10; PinHeader_1x10_P2.54mm_Vertical
J4: IPEX_IPX; IPEX-IPX
J5: Conn_DEBUG; Molex_SPOX_5268-04A_1x04_P2.50mm_Horizontal
L1: 33nH; L_0402_1005Metric
LS1, LS2: Speaker; SM150808-8
R1: 100K; R_0402_1005Metric_Pad0.72x0.64mm_HandSolder
R2, R3, R4, R5: 33R; R_0402_1005Metric_Pad0.72x0.64mm_HandSolder
TP1: SCL; TestPoint_Pad_D1.0mm
TP2: SDA; TestPoint_Pad_D1.0mm
TP3: nRST; TestPoint_Pad_D1.0mm
TP4: WAKEUP; TestPoint_Pad_D1.0mm
TP5: 1PPS; TestPoint_Pad_D1.0mm
U1: Teseo-LIV3F

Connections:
/DEBUG_RX: J3.7, R4.2
/DEBUG_TX: J3.8, R5.2
/GPS_RX: J3.4, R3.1
/GPS_TX: J3.5, R2.1
/HP_DETECT: J1.4, J2.4
/HP_LEFT: J1.2, J2.2
/HP_RIGHT: J1.3, J2.3
/SPK_LN: J2.7, LS1.2
/SPK_LP: J2.6, LS1.1
/SPK_RN: J2.9, LS2.2
/SPK_RP: J2.8, LS2.1
GND: C1.1, C2.1, C3.1, J3.10, J4.2, J4.3, J5.4, U1.1, U1.10, U1.12
GNDA: J1.1, J2.10
unnamed: C1.2, L1.1, U1.14
unnamed: J1.12, R1.2
unnamed: J4.1, L1.2, U1.11
unnamed: J5.2, R4.1
unnamed: J5.3, R5.1
unnamed: R2.2, U1.2
unnamed: R3.2, U1.3
unnamed: TP1.1, U1.17
unnamed: TP2.1, U1.16
unnamed: TP3.1, U1.9
unnamed: TP4.1, U1.5
unnamed: TP5.1, U1.4
VCC_3V3: J2.1, R1.1
VCC_PERIH: C2.2, C3.2, J3.1, J3.2, J5.1, U1.6, U1.7, U1.8

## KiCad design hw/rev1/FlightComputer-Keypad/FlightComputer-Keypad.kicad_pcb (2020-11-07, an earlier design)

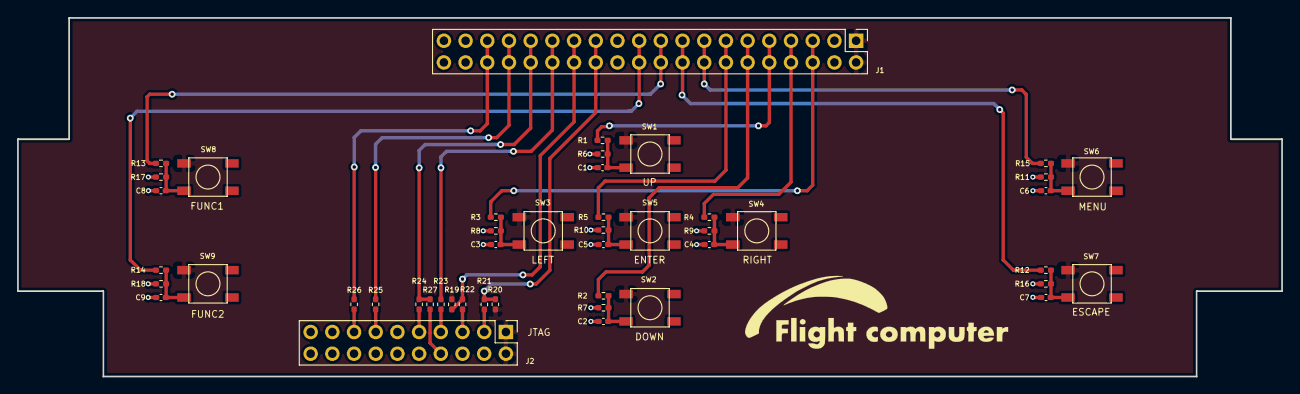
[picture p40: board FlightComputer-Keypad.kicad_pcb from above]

Board: 2 copper layers, 148.0 x 42.0 mm, 47 parts (0 on the bottom side), 32 nets.

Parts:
C1, C2, C3, C4, C5, C6, C7, C8, C9: 0.1uF; C_0402_1005Metric_Pad0.74x0.62mm_HandSolder
J1: Conn_02x20_Odd_Even; PinHeader_2x20_P2.54mm_Vertical
J2: Conn_02x10_Odd_Even; PinHeader_2x10_P2.54mm_Vertical
R1, R2, R3, R4, R5, R11, R12, R13, R14: 1K; R_0402_1005Metric_Pad0.72x0.64mm_HandSolder
R6, R7, R8, R9, R10, R15, R16, R17, R18, R19, R20, R27: 100K; R_0402_1005Metric_Pad0.72x0.64mm_HandSolder
R21, R22, R23, R24, R25, R26: 33R; R_0402_1005Metric_Pad0.72x0.64mm_HandSolder
SW1, SW2, SW3, SW4, SW5, SW6, SW7, SW8, SW9: SW_Push; SW-SPST-PTS647

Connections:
/KEY_DOWN: J1.11, J1.12, R2.2
/KEY_ENTER: J1.13, J1.14, R5.2
/KEY_ESCAPE: J1.17, J1.18, R12.2
/KEY_FUNC1: J1.19, J1.20, R13.2
/KEY_FUNC2: J1.21, J1.22, R14.2
/KEY_LEFT: J1.5, J1.6, R3.2
/KEY_MENU: J1.15, J1.16, R11.2
/KEY_RIGHT: J1.7, J1.8, R4.2
/KEY_UP: J1.9, J1.10, R1.2
/TCLK: J1.31, J1.32, R24.1, R27.1
/TDI: J1.27, J1.28, R19.2, R22.1
/TDO: J1.33, J1.34, R25.1
/TMS: J1.29, J1.30, R23.1
/TRST: J1.25, J1.26, R20.2, R21.1
/nRESET: J1.35, J1.36, R26.1
GND: C1.2, C2.2, C3.2, C4.2, C5.2, C6.2, C7.2, C8.2, C9.2, J1.39, J1.40, J2.4, J2.6, J2.8, J2.10, J2.12, J2.14, J2.16, J2.18, J2.20, R6.1, R7.1, R8.1, R9.1, R10.1, R15.1, R16.1, R17.1, R18.1, R27.2
unnamed: C1.1, R1.1, R6.2, SW1.1
unnamed: C2.1, R2.1, R7.2, SW2.1
unnamed: C3.1, R3.1, R8.2, SW3.1
unnamed: C4.1, R4.1, R9.2, SW4.1
unnamed: C5.1, R5.1, R10.2, SW5.1
unnamed: C6.1, R11.1, R15.2, SW6.1
unnamed: C7.1, R12.1, R16.2, SW7.1
unnamed: C8.1, R13.1, R17.2, SW8.1
unnamed: C9.1, R14.1, R18.2, SW9.1
unnamed: J2.3, R21.2
unnamed: J2.5, R22.2
unnamed: J2.7, R23.2
unnamed: J2.9, R24.2
unnamed: J2.13, R25.2
unnamed: J2.15, R26.2
VCC_MCU: J1.1, J1.2, J2.1, J2.2, R19.1, R20.1, SW1.2, SW2.2, SW3.2, SW4.2, SW5.2, SW6.2, SW7.2, SW8.2, SW9.2

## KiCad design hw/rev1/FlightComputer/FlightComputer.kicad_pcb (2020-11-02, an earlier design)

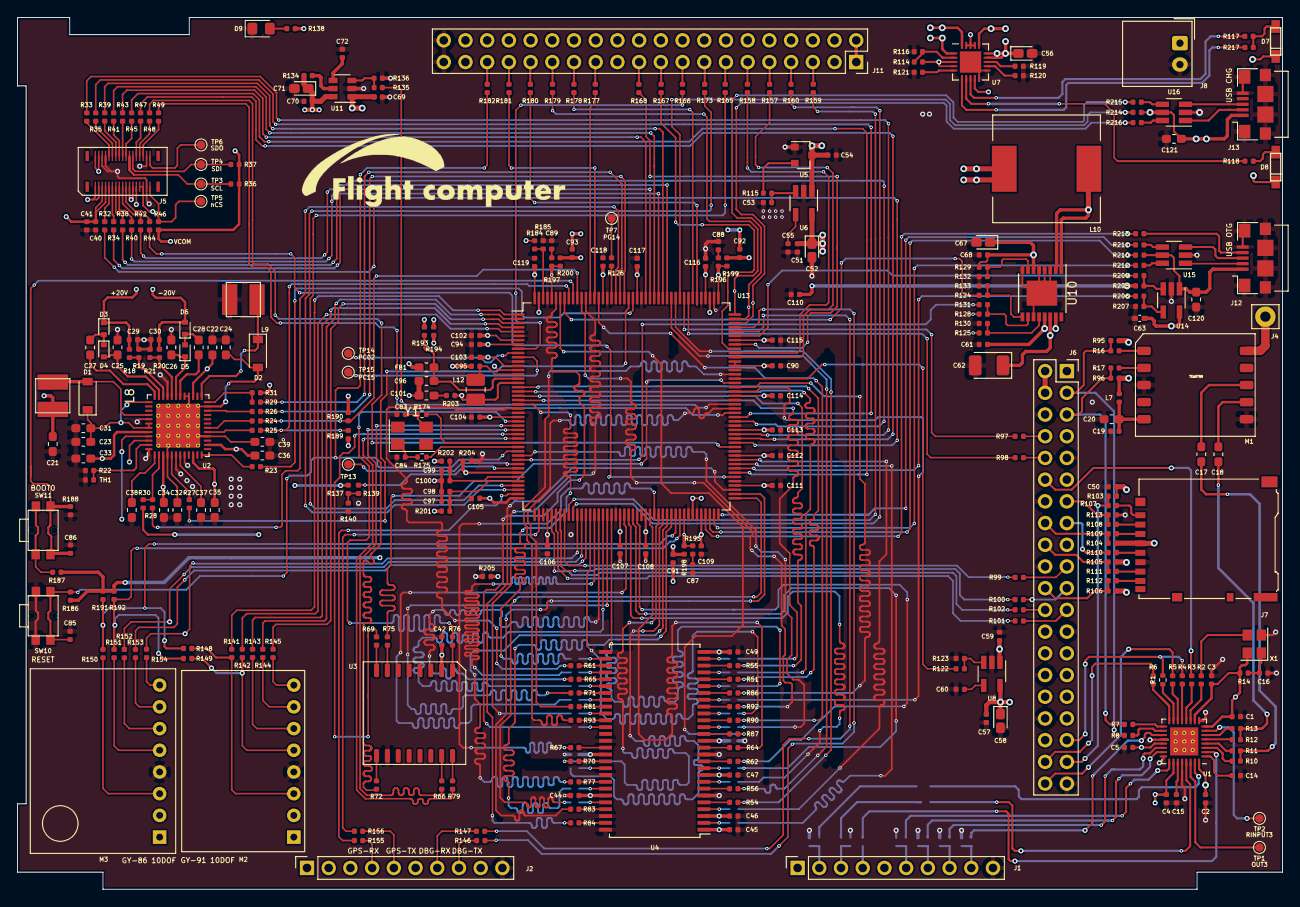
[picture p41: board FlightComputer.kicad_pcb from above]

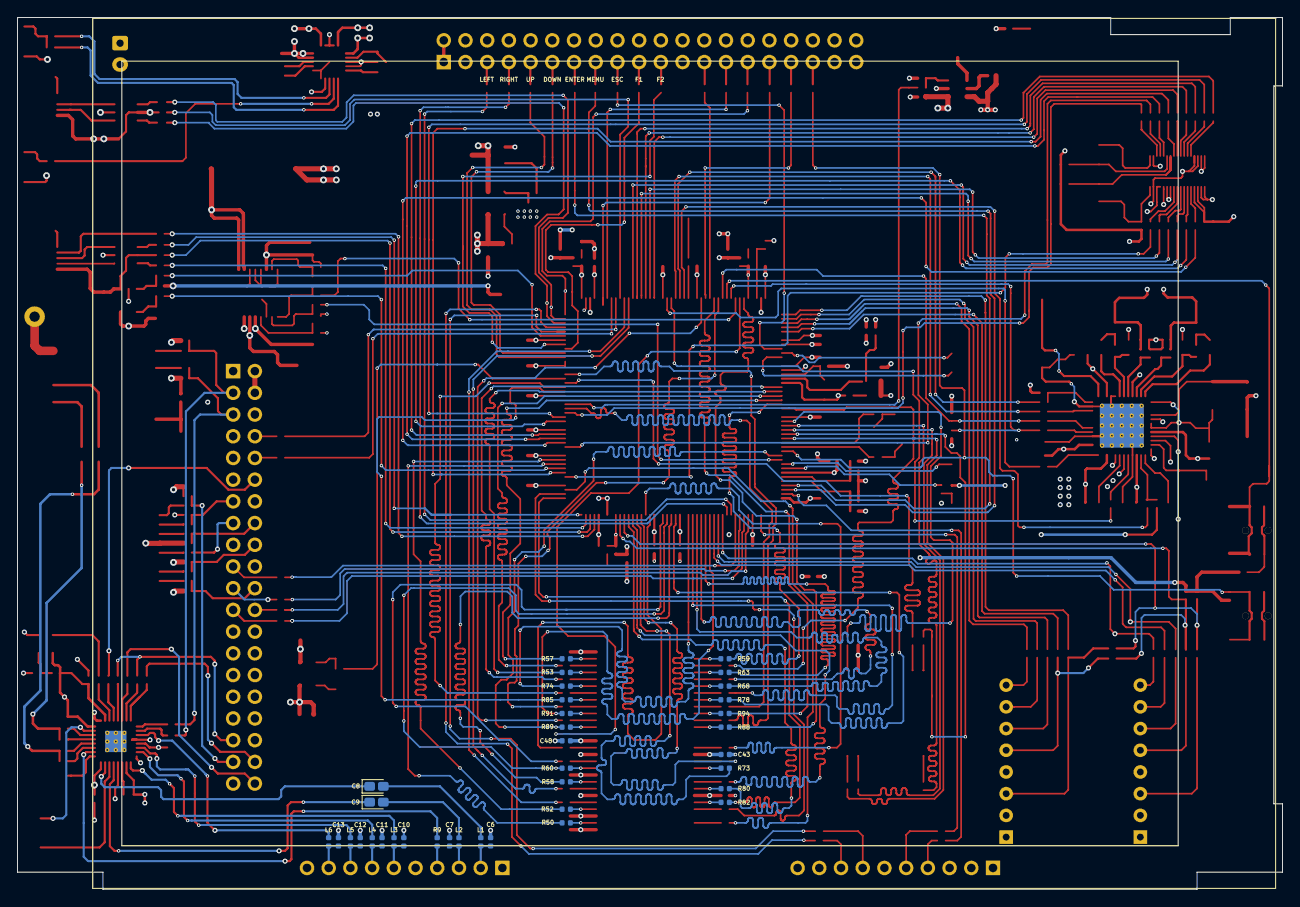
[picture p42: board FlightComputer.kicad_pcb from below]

Board: 4 copper layers, 148.0 x 102.0 mm, 376 parts (36 on the bottom side), 373 nets.

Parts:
C1, C2, C3, C16, C19, C41, C42, C43, C44, C45, C46, C47, C48, C49, C50, C51, C57, C68, C70, C85, C86, C87, C88, C89, C94, C98, C100, C102, C103, C104, C105, C106, C107, C108, C109, C111, C112, C113, C114, C115, C116, C117, C118, C119: 0.1uF; C_0402_1005Metric
C4, C5, C14, C15, C91, C92, C93, C110: 4.7uF; C_0402_1005Metric
C6, C7, C10, C11, C12, C13, C95: 220pF; C_0402_1005Metric
C8, C9, C52, C56, C58, C67, C71: 10uF; CP_EIA-1608-08_AVX-J_Pad1.25x1.05mm_HandSolder
C17, C18, C20, C21, C22, C35, C96, C101, C120, C121: 10uF; C_0603_1608Metric_Pad1.05x0.95mm_HandSolder
C23, C24, C31, C32, C33, C34, C36, C37, C38, C39: 4.7uF; C_0603_1608Metric_Pad1.05x0.95mm_HandSolder
C25, C26: 0.1uF; C_0603_1608Metric_Pad1.05x0.95mm_HandSolder
C27, C28: 0.01uF; C_0603_1608Metric_Pad1.05x0.95mm_HandSolder
C29, C30, C61: 2.2uF; C_0402_1005Metric
C40, C53, C54, C59, C69, C90, C97, C99: 1uF; C_0402_1005Metric
C55, C60, C72: N/C; C_0402_1005Metric
C62: 100uF; CP_EIA-3528-15_AVX-H_Pad1.50x2.35mm_HandSolder
C63: 2.2uF; C_0402_1005Metric_Pad0.74x0.62mm_HandSolder
C83, C84: 18pF; C_0402_1005Metric
D1, D2: MBR130T1G; D_SOD-123
D3, D4, D5: RB531SM; D_SOD-523
D6: BAT54-SOT23; D_SOD-523
D7: LED_R; SML-LXR85GC-TR
D8: LED_G; SML-LXR85GC-TR
D9: LED_G; D_0805_2012Metric_Pad1.15x1.40mm_HandSolder
FB1: BEAD(BMJ1608HM180NTR); L_0603_1608Metric_Pad1.05x0.95mm_HandSolder
J1, J2: Conn_01x10; PinSocket_1x10_P2.54mm_Vertical
J4: Conn_01x01; Pin_D1.2mm_L10.2mm_W2.9mm_FlatFork
J5: ED060SC7_EPD; AXT334124
J6: RPI_Connector; PinSocket_2x20_P2.54mm_Vertical
J7: Micro_SD_Card; microSD_HC_Hirose_DM3AT-SF-PEJM5
J8: Conn_01x02; Molex_SPOX_5268-02A_1x02_P2.50mm_Horizontal
J11: Conn_02x20_Odd_Even; PinSocket_2x20_P2.54mm_Vertical
J12, J13: USB_B_Micro; USB_Micro-B_TE-1981568-1
L1, L2, L3, L4, L5, L6, L7: Ferrite; L_0402_1005Metric
L8: 2.2uH; L_1515(4040 metric)
L9: 4.7uH; L_1515(4040 metric)
L10: 68uH w/2A; L_12x12mm_H6mm
L12: 2.2uH (LQM2MPN2R2NG0); L_1008_2520Metric_Pad1.43x2.20mm_HandSolder
M1: TEA5767_Radio_Module; TEA5756-TJ-102BC
M2: GY-91
M3: GY-86
R1, R2, R3, R4, R5, R6, R7, R8, R9, R10, R13, R16, R17, R23, R24, R25, R26, R27, R28, R29, R32, R33, R34, R35, R38, R39, R40, R41, R42, R43, R44, R45, R47, R48, R49, R50, R51, R52, R53, R54, R55, R56, R57, R58, R59, R60, R61, R62, R63, R64, R65, R66, R67, R68, R69, R70, R71, R72, R73, R74, R75, R76, R77, R78, R79, R80, R81, R82, R83, R84, R85, R86, R87, R88, R89, R90, R91, R92, R93, R94, R97, R98, R99, R100, R101, R102, R107, R108, R109, R110, R111, R112, R122, R124, R131, R135, R141, R142, R143, R144, R145, R146, R147, R150, R151, R152, R153, R154, R155, R156, R177, R178, R179, R180, R181, R182, R206, R209, R210, R211, R212, R213, R214, R215, R216: 33R; R_0402_1005Metric
R11, R12, R117, R126, R148, R149, R185, R193, R195, R196, R197, R200: N/C; R_0402_1005Metric
R14, R30, R31, R36, R37, R46, R184, R189, R190, R191, R192, R207: 10K; R_0402_1005Metric
R18, R20, R115, R128, R140: 1M; R_0402_1005Metric
R19: 47.5K; R_0402_1005Metric
R21: 52.3K; R_0402_1005Metric
R22: 43K; R_0402_1005Metric
R95, R96, R103, R104, R105, R106: 47K; R_0402_1005Metric
R113, R116, R120, R123, R133, R136, R186, R188: 100K; R_0402_1005Metric
R114: 270K; R_0402_1005Metric
R118, R119, R134, R138, R187, R217: 1K; R_0402_1005Metric
R121: 15K; R_0402_1005Metric
R125, R129: 1.87M; R_0402_1005Metric
R130, R132: 340K; R_0402_1005Metric
R137: 560K; R_0402_1005Metric
R139, R157, R158, R159, R160, R165, R166, R167, R168, R173, R174, R175, R194, R198, R199, R201, R202, R203, R204, R205: 0R; R_0402_1005Metric
R208: 47k; R_0402_1005Metric
SW10, SW11: SW_Push; SW-TACT-436351045816
TH1: NCP18XH103F03RB(10K); R_0402_1005Metric
TP1: OUT3; TestPoint_Pad_D1.0mm
TP2: RINPUT3; TestPoint_Pad_D1.0mm
TP3: EINK_SPI_SCL; TestPoint_Pad_D1.0mm
TP4: EINK_SPI_SDI; TestPoint_Pad_D1.0mm
TP5: EINK_SPI_CS; TestPoint_Pad_D1.0mm
TP6: EINK_SPI_SDO; TestPoint_Pad_D1.0mm
TP7: TP_EXTRA_PWR; TestPoint_Pad_D1.0mm
TP13: PC2; TestPoint_Pad_D1.0mm
TP14: PC14; TestPoint_Pad_D1.0mm
TP15: PC15; TestPoint_Pad_D1.0mm
U1: WM8960; QFN-32-1EP_5x5mm_P0.5mm_EP3.3x3.3mm_ThermalVias
U2: TPS65186; VQFN-48-1EP_7x7mm_P0.5mm_EP5.15x5.15mm_ThermalVias
U3: MT25QL512ABB8ESF; SOP2-16_7.5x10.3mm_P1.27mm
U4: MT48LC16M16A2P; TSOP-II-54_22.2x10.16mm_P0.8mm
U5: MAX809TTRG; SOT-23
U6, U8: XC6220B331MR-G; SOT-23-5_HandSoldering
U7: MCP73871; QFN-20-1EP_4x4mm_P0.5mm_EP2.5x2.5mm
U10: TPS61032PWR; TSSOP-16-1EP_4.4x5mm_P0.65mm
U11: TPS22917DBV; SOT-23-6
U13: STM32H745IIT; LQFP-176_24x24mm_P0.5mm
U14: STMPS2151STR; SOT-23-5_HandSoldering
U15, U16: USBLC6-2SC6; SOT-23-6_Handsoldering
X1: 24MHz; Oscillator_SMD_Abracon_ASE-4Pin_3.2x2.5mm
Y1: 25MHz; Crystal_SMD_5032-4Pin_5.0x3.2mm

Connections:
+15V: C33.1, J5.2, J5.4, U2.44
+22V: C29.2, D3.1, J5.25, R18.1
+BATT: C56.1, J8.1, U7.14, U7.15, U7.16
-15V: C34.2, J5.1, J5.3, U2.3
-20V: C30.1, D6.2, J5.27, J5.29, R20.2
/Codec/HPDETECT: J1.4, R9.2
/Codec/I2C_SCL: J6.5, R7.2, R17.2, R96.2
/Codec/I2C_SDA: J6.3, R8.2, R16.2, R95.2
/Codec/I2S_DIN: J6.40, R5.2
/Codec/I2S_LRCK: J6.35, R1.2, R4.2
/Codec/I2S_MCLK: R2.2, X1.3
/Codec/I2S_SCLK: J6.12, R3.2
/Codec/RADIO_L: C17.2, R10.2, R11.2
/Codec/RADIO_R: C18.2, R12.2, R13.2
/DEBUG/DEBUG_JMS-SWDIO: R179.1, U13.132
/DEBUG/DEBUG_JTCK-SWCLK: R180.1, U13.138
/DEBUG/DEBUG_JTDI: R178.1, U13.139
/DEBUG/DEBUG_JTDO-SWO: R181.1, U13.162
/DEBUG/DEBUG_nJTRST: R177.1, U13.163
/DEBUG/nRST: C85.1, R182.1, R186.1, SW10.1, U13.33
/EINK-PMIC/EPD_CKV: R48.2, U13.101
/EINK-PMIC/EPD_CL: R32.1, U13.102
/EINK-PMIC/EPD_D0: R38.1, U13.145
/EINK-PMIC/EPD_D1: R39.2, U13.146
/EINK-PMIC/EPD_D2: R40.1, U13.147
/EINK-PMIC/EPD_D3: R41.2, U13.148
/EINK-PMIC/EPD_D4: R42.1, U13.149
/EINK-PMIC/EPD_D5: R43.2, U13.150
/EINK-PMIC/EPD_D6: R44.1, U13.94
/EINK-PMIC/EPD_D7: R45.2, U13.95
/EINK-PMIC/EPD_GMODE: R47.2, U13.103
/EINK-PMIC/EPD_LE: R33.2, U13.104
/EINK-PMIC/EPD_OE: R34.1, U13.107
/EINK-PMIC/EPD_PMIC_PWRUP: R26.1, U13.155
/EINK-PMIC/EPD_PMIC_PWR_GOOD: R29.2, U13.156
/EINK-PMIC/EPD_PMIC_SCL: R25.1, R189.2, U13.168
/EINK-PMIC/EPD_PMIC_SDA: R24.1, R190.2, U13.166
/EINK-PMIC/EPD_PMIC_VCOM: R23.1, U13.153
/EINK-PMIC/EPD_PMIC_WAKEUP: R27.1, U13.154
/EINK-PMIC/EPD_PMIC_nINT: R28.2, U13.157
/EINK-PMIC/EPD_SPH: R35.2, U13.108
/EINK-PMIC/EPD_SPV: R49.2, U13.109
/EINK-PMIC/VCOM: C36.1, J5.21, J5.23, U2.14
/EINK_MISO: R100.2, U13.51
/EINK_MOSI: R99.2, U13.52
/EINK_SCLK: R101.2, U13.50
/EINK_nCS: R102.1, U13.49
/IMU1_MISO: R143.2, U13.4
/IMU1_MOSI: R142.2, U13.5
/IMU1_SCLK: R141.2, U13.1
/IMU1_nCS1: R144.2, U13.2
/IMU1_nCS2: R145.2, U13.3
/IMU2_DRDY: R154.2, U13.55
/IMU2_FSYNC: R152.2, U13.56
/IMU2_SCL: R148.1, R150.2, R191.2, U13.78
/IMU2_SDA: R149.1, R151.2, R192.2, U13.79
/IMU2_nINT: R153.2, U13.57
/KEYBOARD/KEY_DOWN: R158.2, U13.123
/KEYBOARD/KEY_ENTER: R165.2, U13.41
/KEYBOARD/KEY_ESCAPE: R166.2, U13.9
/KEYBOARD/KEY_FUNC1: R167.2, U13.124
/KEYBOARD/KEY_FUNC2: R168.2, U13.125
/KEYBOARD/KEY_LEFT: R159.2, U13.53
/KEYBOARD/KEY_MENU: R173.2, U13.42
/KEYBOARD/KEY_RIGHT: R160.2, U13.54
/KEYBOARD/KEY_UP: R157.2, U13.122
/MCU/BAT_SENSING: R139.1, U13.37
/MCU/BOOT0: C86.1, R188.2, SW11.1, U13.167
/MCU/FMC_A0: R51.2, U13.18
/MCU/FMC_A1: R53.2, U13.19
/MCU/FMC_A2: R55.2, U13.20
/MCU/FMC_A3: R57.2, U13.21
/MCU/FMC_A4: R59.2, U13.22
/MCU/FMC_A5: R61.2, U13.23
/MCU/FMC_A6: R63.2, U13.59
/MCU/FMC_A7: R65.2, U13.60
/MCU/FMC_A8: R68.2, U13.61
/MCU/FMC_A9: R71.2, U13.62
/MCU/FMC_A10: R74.2, U13.63
/MCU/FMC_A11: R78.2, U13.66
/MCU/FMC_A12: R81.2, U13.110
/MCU/FMC_BA0: R85.2, U13.114
/MCU/FMC_BA1: R86.2, U13.115
/MCU/FMC_CKE1: R94.2, U13.164
/MCU/FMC_CLK: R93.2, U13.118
/MCU/FMC_D0: R50.1, U13.97
/MCU/FMC_D1: R52.1, U13.98
/MCU/FMC_D2: R54.1, U13.143
/MCU/FMC_D3: R56.1, U13.144
/MCU/FMC_D4: R58.1, U13.67
/MCU/FMC_D5: R60.1, U13.68
/MCU/FMC_D6: R62.1, U13.69
/MCU/FMC_D7: R64.1, U13.72
/MCU/FMC_D8: R67.1, U13.73
/MCU/FMC_D9: R70.1, U13.74
/MCU/FMC_D10: R73.1, U13.75
/MCU/FMC_D11: R77.1, U13.76
/MCU/FMC_D12: R80.1, U13.77
/MCU/FMC_D13: R82.1, U13.89
/MCU/FMC_D14: R83.1, U13.90
/MCU/FMC_D15: R84.1, U13.91
/MCU/FMC_nBL0: R87.2, U13.170
/MCU/FMC_nBL1: R88.2, U13.171
/MCU/FMC_nCAS: R90.2, U13.161
/MCU/FMC_nE1: R92.2, U13.165
/MCU/FMC_nRAS: R91.2, U13.58
/MCU/FMC_nWE: R89.2, U13.34
/MCU/LOW_BATTERY: R131.2, U13.35
/MCU/MCU_POWER/SMPS_OUT: C91.2, C92.2, C93.2, L12.1, R194.1, R198.1, R199.1, R200.1, R203.2, U13.17
/MCU/MCU_POWER/VCAP: R195.2, R196.2, R197.2, R198.2, R199.2, R200.2, U13.80, U13.133, U13.172
/MCU/MCU_POWER/VDDA: C97.1, C98.1, R201.1, U13.40
/MCU/MCU_POWER/VDDLDO: R193.2, R194.2, U13.82, U13.135, U13.175
/MCU/MCU_POWER/VDDSMPS: C96.1, FB1.2, R193.1, U13.16
/MCU/MCU_POWER/VLXSMPS: C95.1, L12.2, U13.15
/MCU/MCU_POWER/VREF+: C99.1, C100.1, R202.1, U13.39
/MCU/MCU_POWER/VSSA: C97.2, C98.2, C99.2, C100.2, R204.1, U13.38
/MCU/PWR_5V_EN: R124.1, U13.169
/MCU/PWR_BAT+_EN: R135.1, U13.111
/MCU/PWR_EXTRA_EN: R126.1, U13.158
/MCU/PWR_PERIPH_EN: R122.2, U13.117
/MCU/USB_FS_DN: R216.1, U13.130
/MCU/USB_FS_DP: R215.1, U13.131
/MCU/USB_FS_VBUS: R214.1, U13.142
/MCU/USB_HS_DN: R212.1, U13.87
/MCU/USB_HS_DP: R211.1, U13.88
/MCU/USB_HS_ID: R213.1, U13.85
/MCU/USB_HS_OVCR: R209.1, U13.127
/MCU/USB_HS_PWR_EN: R206.1, U13.96
/MCU/USB_HS_VBUS: R210.1, U13.86
/Memory/NOR_CLK: R79.1, U13.30
/Memory/NOR_DQ0: R66.2, U13.28
/Memory/NOR_DQ1: R69.2, U13.29
/Memory/NOR_DQ2: R72.2, U13.27
/Memory/NOR_DQ3: R76.2, U13.26
/Memory/NOR_nCS: R75.1, U13.116
/Raspberry/I2S_DIN: J6.38, R6.2
/Raspberry/SDIO_CLK: J6.15, R110.2
/Raspberry/SDIO_CMD: J6.16, R104.2, R109.2
/Raspberry/SDIO_DAT0: J6.18, R105.2, R111.2
/Raspberry/SDIO_DAT1: J6.22, R106.2, R112.2
/Raspberry/SDIO_DAT2: J6.37, R103.2, R107.2
/Raspberry/SDIO_DAT3: J6.13, R108.2, R113.1
/VARIO_RX: R97.1, U13.141
/VARIO_TX: R98.1, U13.140
/Vario/DEBUG_RX: R147.2, U13.128
/Vario/DEBUG_TX: R146.2, U13.129
/Vario/GPS_RX: R155.2, U13.43
/Vario/GPS_TX: R156.2, U13.46
GND: C1.2, C2.2, C3.2, C4.2, C5.2, C6.2, C7.2, C10.2, C11.2, C12.2, C13.2, C14.2, C15.1, C16.1, C19.2, C20.2, C21.2, C22.1, C23.2, C24.1, C25.2, C26.1, C29.1, C30.2, C31.2, C32.1, C33.2, C34.1, C35.2, C36.2, C37.1, C38.1, C39.1, C40.2, C41.2, C42.2, C43.1, C44.1, C45.1, C46.1, C47.1, C48.1, C49.1, C50.1, C51.2, C52.2, C53.2, C54.2, C55.2, C56.2, C57.2, C58.2, C59.2, C60.2, C61.2, C62.2, C63.2, C67.2, C68.2, C69.2, C70.2, C71.2, C72.2, C83.2, C84.2, C85.2, C86.2, C87.2, C88.2, C89.2, C90.2, C94.2, C102.2, C103.2, C104.2, C105.2, C106.2, C107.2, C108.2, C109.2, C110.2, C111.2, C112.2, C113.2, C114.2, C115.2, C116.2, C117.2, C118.2, C119.2, C120.2, C121.2, D9.1, J1.10, J2.10, J5.6, J5.8, J5.31, J5.32, J6.6, J6.9, J6.14, J6.20, J6.25, J6.30, J6.34, J6.39, J7.6, J8.2, J11.39, J11.40, J12.5, J12.6, J13.5, J13.6, L9.2, M1.3, M1.6, M2.3, M3.3, R19.1, R21.2, R22.1, R113.2, R116.2, R119.2, R120.2, R121.2, R123.1, R130.2, R132.2, R133.2, R136.1, R140.1, R185.1, R188.1, R204.2, R205.2, R207.2, SW10.2, TH1.2, U1.9, U1.20, U1.24, U1.28, U1.33, U2.6, U2.8, U2.33, U2.41, U2.48, U3.10, U4.6, U4.12, U4.28, U4.41, U4.46, U4.52, U4.54, U5.1, U6.2, U7.10, U7.11, U7.21, U8.2, U10.3, U10.4, U10.5, U10.8, U10.11, U10.17, U11.2, U13.6, U13.12, U13.24, U13.45, U13.47, U13.64, U13.70, U13.81, U13.83, U13.93, U13.100, U13.106, U13.112, U13.119, U13.134, U13.137, U13.151, U13.159, U13.173, U14.2, U15.2, U16.2, X1.2
GNDS: C91.1, C92.1, C93.1, C95.2, C96.2, C101.2, R205.1, U13.14
G_KEY_DOWN: J11.11, R158.1
G_KEY_ENTER: J11.13, R165.1
G_KEY_ESCAPE: J11.17, R166.1
G_KEY_FUNC1: J11.19, R167.1
G_KEY_FUNC2: J11.21, R168.1
G_KEY_LEFT: J11.5, R159.1
G_KEY_MENU: J11.15, R173.1
G_KEY_RIGHT: J11.7, R160.1
G_KEY_UP: J11.9, R157.1
unnamed: C6.1, J1.2, L1.2
unnamed: C7.1, J1.3, L2.2
unnamed: C8.1, U1.31
unnamed: C8.2, L1.1
unnamed: C9.1, U1.29
unnamed: C9.2, L2.1
unnamed: C10.1, J1.6, L3.2
unnamed: C11.1, J1.7, L4.2
unnamed: C12.1, J1.8, L5.2
unnamed: C13.1, J1.9, L6.2
unnamed: C14.1, U1.1
unnamed: C15.2, U1.27
unnamed: C16.2, R14.1, X1.1
unnamed: C17.1, M1.8
unnamed: C18.1, M1.7
unnamed: C19.1, C20.1, L7.2, M1.5
unnamed: C23.1, C31.1, D1.1, U2.37, U2.42, U2.43
unnamed: C24.2, C32.2, C39.2, D2.2, U2.4, U2.16, U2.23, U2.28, U2.29, U2.49
unnamed: C25.1, D4.2, U2.35
unnamed: C26.2, D5.1, U2.31
unnamed: C27.1, U2.36
unnamed: C27.2, D3.2, D4.1
unnamed: C28.1, D5.2, D6.1
unnamed: C28.2, U2.30
unnamed: C37.2, U2.7
unnamed: C38.2, U2.1
unnamed: C53.1, R115.1, U6.3
unnamed: C55.1, U6.4
unnamed: C60.1, U8.4
unnamed: C72.1, U11.4
unnamed: C83.1, R174.1, Y1.3
unnamed: C84.1, R175.1, Y1.1
unnamed: C87.1, R195.1
unnamed: C88.1, R196.1
unnamed: C89.1, R197.1
unnamed: C101.1, R203.1
unnamed: C120.1, J12.1, R210.2, U14.1, U15.5
unnamed: D1.2, L8.2, U2.40
unnamed: D2.1, L9.1, U2.25
unnamed: D7.1, R117.1, R217.1
unnamed: D8.1, R118.1
unnamed: D9.2, R138.2
unnamed: J2.4, R155.1
unnamed: J2.5, R156.1
unnamed: J2.7, R147.1
unnamed: J2.8, R146.1
unnamed: J4.1, M1.10
unnamed: J5.9, R32.2
unnamed: J5.10, R33.1
unnamed: J5.11, R34.2
unnamed: J5.12, R35.1
unnamed: J5.13, R38.2
unnamed: J5.14, R39.1
unnamed: J5.15, R40.2
unnamed: J5.16, R41.1
unnamed: J5.17, R42.2
unnamed: J5.18, R43.1
unnamed: J5.19, R44.2
unnamed: J5.20, R45.1
unnamed: J5.22, R36.2, TP3.1
unnamed: J5.24, R37.2, TP4.1
unnamed: J5.26, R47.1
unnamed: J5.28, R48.1
unnamed: J5.30, R49.1
unnamed: J5.33, R46.2, TP5.1
unnamed: J5.34, TP6.1
unnamed: J6.8, R97.2
unnamed: J6.10, R98.2
unnamed: J6.19, R99.1
unnamed: J6.21, R100.1
unnamed: J6.23, R101.1
unnamed: J6.24, R102.2
unnamed: J7.1, R107.1
unnamed: J7.2, R108.1
unnamed: J7.3, R109.1
unnamed: J7.5, R110.1
unnamed: J7.7, R111.1
unnamed: J7.8, R112.1
unnamed: J11.25, R177.2
unnamed: J11.27, R178.2
unnamed: J11.29, R179.2
unnamed: J11.31, R180.2
unnamed: J11.33, R181.2
unnamed: J11.35, R182.2
unnamed: J12.2, U15.1
unnamed: J12.3, U15.3
unnamed: J12.4, R213.2
unnamed: J13.2, U16.1
unnamed: J13.3, U16.3
unnamed: L3.1, U1.25
unnamed: L4.1, U1.23
unnamed: L5.1, U1.22
unnamed: L6.1, U1.19
unnamed: L10.2, U10.1, U10.2
unnamed: M1.1, R16.1
unnamed: M1.2, R17.1
unnamed: M2.4, R141.1, R148.2
unnamed: M2.5, R142.1, R149.2
unnamed: M2.6, R143.1
unnamed: M2.7, R144.1
unnamed: M2.8, R145.1
unnamed: M3.4, R150.1
unnamed: M3.5, R151.1
unnamed: M3.6, R152.1
unnamed: M3.7, R153.1
unnamed: M3.8, R154.1
unnamed: R1.1, U1.15
unnamed: R2.1, U1.11
unnamed: R3.1, U1.12
unnamed: R4.1, U1.13
unnamed: R5.1, U1.14
unnamed: R6.1, U1.16
unnamed: R7.1, U1.17
unnamed: R8.1, U1.18
unnamed: R9.1, U1.2
unnamed: R10.1, U1.3
unnamed: R11.1, U1.4
unnamed: R12.1, U1.5
unnamed: R13.1, U1.6
unnamed: R18.2, R19.2, U2.34
unnamed: R20.1, R21.1, U2.32
unnamed: R22.2, TH1.1, U2.47
unnamed: R23.2, U2.12
unnamed: R24.2, U2.18
unnamed: R25.2, U2.17
unnamed: R26.2, U2.22
unnamed: R27.2, U2.5
unnamed: R28.1, R30.2, U2.2
unnamed: R29.1, R31.2, U2.24
unnamed: R50.2, U4.2
unnamed: R51.1, U4.23
unnamed: R52.2, U4.4
unnamed: R53.1, U4.24
unnamed: R54.2, U4.5
unnamed: R55.1, U4.25
unnamed: R56.2, U4.7
unnamed: R57.1, U4.26
unnamed: R58.2, U4.8
unnamed: R59.1, U4.29
unnamed: R60.2, U4.10
unnamed: R61.1, U4.30
unnamed: R62.2, U4.11
unnamed: R63.1, U4.31
unnamed: R64.2, U4.13
unnamed: R65.1, U4.32
unnamed: R66.1, U3.15
unnamed: R67.2, U4.42
unnamed: R68.1, U4.33
unnamed: R69.1, U3.8
unnamed: R70.2, U4.44
unnamed: R71.1, U4.34
unnamed: R72.1, U3.9
unnamed: R73.2, U4.45
unnamed: R74.1, U4.22
unnamed: R75.2, U3.7
unnamed: R76.1, U3.1
unnamed: R77.2, U4.47
unnamed: R78.1, U4.35
unnamed: R79.2, U3.16
unnamed: R80.2, U4.48
unnamed: R81.1, U4.36
unnamed: R82.2, U4.50
unnamed: R83.2, U4.51
unnamed: R84.2, U4.53
unnamed: R85.1, U4.20
unnamed: R86.1, U4.21
unnamed: R87.1, U4.15
unnamed: R88.1, U4.39
unnamed: R89.1, U4.16
unnamed: R90.1, U4.17
unnamed: R91.1, U4.18
unnamed: R92.1, U4.19
unnamed: R93.1, U4.38
unnamed: R94.1, U4.37
unnamed: R114.2, R116.1, U7.2
unnamed: R115.2, U5.2
unnamed: R117.2, U7.8
unnamed: R118.2, U7.7
unnamed: R119.1, U7.13
unnamed: R120.1, U7.12
unnamed: R121.1, U7.5
unnamed: R122.1, R123.2, U8.3
unnamed: R124.2, R133.1, U10.9
unnamed: R125.2, R130.1, U10.12
unnamed: R126.2, TP7.1
unnamed: R128.2, R131.1, U10.10
unnamed: R129.2, R132.1, U10.7
unnamed: R134.1, U11.5
unnamed: R135.2, R136.2, U11.3
unnamed: R137.2, R139.2, R140.2
unnamed: R174.2, U13.31
unnamed: R175.2, U13.32
unnamed: R184.2, R185.2, U13.174
unnamed: R187.1, SW11.2
unnamed: R206.2, R207.1, U14.4
unnamed: R208.1, R209.2, U14.3
unnamed: R211.2, U15.4
unnamed: R212.2, U15.6
unnamed: R215.2, U16.4
unnamed: R216.2, U16.6
unnamed: R217.2, U7.6
unnamed: TP1.1, U1.30
unnamed: TP2.1, U1.7
unnamed: TP13.1, U13.36
unnamed: TP14.1, U13.10
unnamed: TP15.1, U13.11
VCC_3V3: C1.1, C2.1, C3.1, C50.2, J1.1, J6.1, J7.4, L7.1, R14.2, R95.1, R96.1, R103.1, R104.1, R105.1, R106.1, U1.8, U1.10, U1.32, X1.4
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

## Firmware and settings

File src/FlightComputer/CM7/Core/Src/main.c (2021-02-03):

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
/* Includes ------------------------------------------------------------------*/
#include "main.h"
#include "adc.h"
#include "fatfs.h"
#include "i2c.h"
#include "quadspi.h"
#include "spi.h"
#include "usart.h"
#include "usb_device.h"
#include "usb_host.h"
#include "gpio.h"
#include "fmc.h"
#include "sdram_drv.h"

/* USER CODE BEGIN PD */

#ifndef HSEM_ID_0
#define HSEM_ID_0 (0U) /* HW semaphore 0*/
#endif
/* USER CODE END PD */


void SystemClock_Config(void);
/**
  * @brief  The application entry point.
  * @retval int
  */
int main_obsolete(void)
{
/* USER CODE BEGIN Boot_Mode_Sequence_0 */
  int32_t timeout;
/* USER CODE END Boot_Mode_Sequence_0 */

/* USER CODE BEGIN Boot_Mode_Sequence_1 */
  /* Wait until CPU2 boots and enters in stop mode or timeout*/
  timeout = 0xFFFF;
  while((__HAL_RCC_GET_FLAG(RCC_FLAG_D2CKRDY) != RESET) && (timeout-- > 0));
  if ( timeout < 0 )
  {
  Error_Handler();
  }
/* USER CODE END Boot_Mode_Sequence_1 */
  /* MCU Configuration--------------------------------------------------------*/

  /* Reset of all peripherals, Initializes the Flash interface and the Systick. */
  HAL_Init();

  /* Configure the system clock */
  SystemClock_Config();
/* USER CODE BEGIN Boot_Mode_Sequence_2 */
/* When system initialization is finished, Cortex-M7 will release Cortex-M4 by means of
HSEM notification */
/*HW semaphore Clock enable*/
__HAL_RCC_HSEM_CLK_ENABLE();
/*Take HSEM */
HAL_HSEM_FastTake(HSEM_ID_0);
/*Release HSEM in order to notify the CPU2(CM4)*/
HAL_HSEM_Release(HSEM_ID_0,0);
/* wait until CPU2 wakes up from stop mode */
timeout = 0xFFFF;
while((__HAL_RCC_GET_FLAG(RCC_FLAG_D2CKRDY) == RESET) && (timeout-- > 0));
if ( timeout < 0 )
{
Error_Handler();
}
/* USER CODE END Boot_Mode_Sequence_2 */

  /* Initialize all configured peripherals */
  MX_GPIO_Init();
  MX_FMC_Init();
  MX_I2C2_Init();
  MX_QUADSPI_Init();
  MX_SPI1_Init();
  MX_USART1_UART_Init();
  MX_USB_DEVICE_Init();
  MX_FATFS_Init();
  //MX_ADC3_Init();
  MX_I2C1_Init();
  MX_SPI4_Init();
  MX_USART2_UART_Init();
  MX_USART3_UART_Init();
  MX_USB_HOST_Init();
  /* USER CODE BEGIN 2 */
  HAL_GPIO_WritePin(PWR_EN_PERIPH_GPIO_Port, PWR_EN_PERIPH_Pin, GPIO_PIN_SET);
  HAL_Delay(100);
  SDRAM_Do_InitializeSequence(&hsdram1);
  /* USER CODE END 2 */

  /* Infinite loop */
  /* USER CODE BEGIN WHILE */
  while (1)
  {
    /* USER CODE END WHILE */

    /* USER CODE BEGIN 3 */
  }
  /* USER CODE END 3 */
}

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


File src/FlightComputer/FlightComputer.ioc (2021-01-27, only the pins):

Mcu.UserName=STM32H745IITx
PA0.GPIO_Label=PWR_WKUP0/KEY_ENTER
PA0.Signal=PWR_WKUP0
PA1.GPIO_Label=KEY_MENU
PA1.Signal=GPIO_Input
PA10.GPIO_Label=DEBUG_RX
PA10.Signal=USART1_RX
PA11.Signal=USB_OTG_FS_DM
PA12.Signal=USB_OTG_FS_DP
PA2.GPIO_Label=GPS_TX
PA2.Signal=USART2_TX
PA3.GPIO_Label=GPS_RX
PA3.Signal=USART2_RX
PA4.GPIO_Label=EINK_nCS
PA4.Signal=SPI1_NSS
PA5.GPIO_Label=EINK_SCLK
PA5.Signal=SPI1_SCK
PA6.GPIO_Label=EINK_MISO
PA6.Signal=SPI1_MISO
PA7.GPIO_Label=EINK_MOSI
PA7.Signal=SPI1_MOSI
PA8.GPIO_Label=USB_OTG_HS_OVCR
PA8.Signal=GPIO_Input
PA9.GPIO_Label=DEBUG_TX
PA9.Signal=USART1_TX
PB0.GPIO_Label=IMU_DRDY
PB0.Signal=GPIO_Input
PB1.GPIO_Label=IMU_FSYNC
PB1.Signal=GPIO_Input
PB10.Signal=I2C2_SCL
PB11.Signal=I2C2_SDA
PB12.GPIO_Label=USB_OTG_HS_ID
PB12.Signal=GPIO_Input
PB13.Signal=USB_OTG_HS_VBUS
PB14.Signal=USB_OTG_HS_DM
PB15.Signal=USB_OTG_HS_DP
PB2.GPIO_Label=IMU_nINT
PB2.Signal=GPIO_Input
PB5.Signal=FMC_SDCKE1
PB6.Signal=FMC_SDNE1
PB7.Signal=I2C1_SDA
PB8.Signal=I2C1_SCL
PB9.GPIO_Label=PWR_5V_EN
PB9.Signal=GPIO_Output
PC0.Signal=FMC_SDNWE
PC1.GPIO_Label=RPI_STATUS
PC1.Signal=GPIO_Input
PC10.GPIO_Label=VARIO_TX
PC10.Signal=USART3_TX
PC11.GPIO_Label=VARIO_RX
PC11.Signal=USART3_RX
PC12.GPIO_Label=USB_OTG_FS_VBUS
PC12.Signal=GPIO_Input
PC13.GPIO_Label=KEY_ESCAPE
PC13.Signal=GPIO_Input
PC3_C.Signal=ADC3_INP1
PC4.GPIO_Label=KEY_LEFT
PC4.Signal=GPIO_Input
PC5.GPIO_Label=KEY_RIGHT
PC5.Signal=GPIO_Input
PC6.GPIO_Label=KEY_UP
PC6.Signal=GPIO_Input
PC7.GPIO_Label=KEY_DOWN
PC7.Signal=GPIO_Input
PC8.GPIO_Label=KEY_FUNC1
PC8.Signal=GPIO_Input
PC9.GPIO_Label=KEY_FUNC2
PC9.Signal=GPIO_Input
PD0.Signal=FMC_D2_DA2
PD1.Signal=FMC_D3_DA3
PD10.Signal=FMC_D15_DA15
PD11.GPIO_Label=EPD_D6
PD11.Signal=GPIO_Output
PD12.GPIO_Label=EPD_D7
PD12.Signal=GPIO_Output
PD13.GPIO_Label=USB_OTG_HS_PWR_EN
PD13.Signal=GPIO_Output
PD14.Signal=FMC_D0_DA0
PD15.Signal=FMC_D1_DA1
PD2.GPIO_Label=EPD_D0
PD2.Signal=GPIO_Output
PD3.GPIO_Label=EPD_D1
PD3.Signal=GPIO_Output
PD4.GPIO_Label=EPD_D2
PD4.Signal=GPIO_Output
PD5.GPIO_Label=EPD_D3
PD5.Signal=GPIO_Output
PD6.GPIO_Label=EPD_D4
PD6.Signal=GPIO_Output
PD7.GPIO_Label=EPD_D5
PD7.Signal=GPIO_Output
PD8.Signal=FMC_D13_DA13
PD9.Signal=FMC_D14_DA14
PE0.Signal=FMC_NBL0
PE1.Signal=FMC_NBL1
PE10.Signal=FMC_D7_DA7
PE11.Signal=FMC_D8_DA8
PE12.Signal=FMC_D9_DA9
PE13.Signal=FMC_D10_DA10
PE14.Signal=FMC_D11_DA11
PE15.Signal=FMC_D12_DA12
PE2.GPIO_Label=IMU1_SCLK
PE2.Signal=SPI4_SCK
PE3.GPIO_Label=IMU1_nCS1
PE3.Signal=GPIO_Output
PE4.GPIO_Label=IMU1_nCS2
PE4.Signal=GPIO_Output
PE5.GPIO_Label=IMU1_MISO
PE5.Signal=SPI4_MISO
PE6.GPIO_Label=IMU1_MOSI
PE6.Signal=SPI4_MOSI
PE7.Signal=FMC_D4_DA4
PE8.Signal=FMC_D5_DA5
PE9.Signal=FMC_D6_DA6
PF0.Signal=FMC_A0
PF1.Signal=FMC_A1
PF10.Signal=QUADSPI_CLK
PF11.Signal=FMC_SDNRAS
PF12.Signal=FMC_A6
PF13.Signal=FMC_A7
PF14.Signal=FMC_A8
PF15.Signal=FMC_A9
PF2.Signal=FMC_A2
PF3.Signal=FMC_A3
PF4.Signal=FMC_A4
PF5.Signal=FMC_A5
PF6.Signal=QUADSPI_BK1_IO3
PF7.Signal=QUADSPI_BK1_IO2
PF8.Signal=QUADSPI_BK1_IO0
PF9.Signal=QUADSPI_BK1_IO1
PG0.Signal=FMC_A10
PG1.Signal=FMC_A11
PG10.GPIO_Label=PMIC_WAKEUP
PG10.Signal=GPIO_Output
PG11.GPIO_Label=PMIC_PWRUP
PG11.Signal=GPIO_Output
PG13.GPIO_Label=PWR_LED2
PG13.Signal=GPIO_Output
PG14.GPIO_Label=PWR_LED1
PG14.Signal=GPIO_Output
PG15.Signal=FMC_SDNCAS
PG2.Signal=FMC_A12
PG3.GPIO_Label=PWR_EN_PMIC
PG3.Signal=GPIO_Output
PG4.Signal=FMC_A14_BA0
PG5.Signal=FMC_A15_BA1
PG6.Signal=QUADSPI_BK1_NCS
PG7.GPIO_Label=PWR_EN_PERIPH
PG7.Signal=GPIO_Output
PG8.Signal=FMC_SDCLK
PG9.GPIO_Label=PMIC_VCOM
PG9.Signal=GPIO_Output
PJ10.GPIO_Label=EPD_GMODE
PJ10.Signal=GPIO_Output
PJ11.GPIO_Label=EPD_LE
PJ11.Signal=GPIO_Output
PJ8.GPIO_Label=EPD_CKV
PJ8.Signal=GPIO_Output
PJ9.GPIO_Label=EPD_CL
PJ9.Signal=GPIO_Output
PK0.GPIO_Label=EPD_OE
PK0.Signal=GPIO_Output
PK1.GPIO_Label=EPD_SPH
PK1.Signal=GPIO_Output
PK2.GPIO_Label=EPD_SPV
PK2.Signal=GPIO_Output

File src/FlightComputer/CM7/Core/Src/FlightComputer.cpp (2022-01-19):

/*
 * FlightComputer.cpp
 *
 *  Created on: 2021. 12. 31.
 *      Author: akkdong
 */

#include "main.h"
#include "FlightComputer.h"
#if SUPPORT_LVGL
#include "lv_port.h"
#endif
#include "common.h"
#include "debug.h"


#include "Adafruit_GFX/Fonts/FreeSans16pt7b.h"
#include "Adafruit_GFX/Fonts/FreeSans10pt7b.h"


/////////////////////////////////////////////////////////////////////////////////////
//


/* Ringbuffer variables */
extern lwrb_t* rb_cm4_to_cm7;
extern lwrb_t* rb_cm7_to_cm4;


//static HardwareSerial& Debug = Serial;
//static HardwareSerial& RPI = Serial3;


int32_t shell_hello(int32_t argc, char** argv)
{
	TRACE("Hi~\r\n");

	return 0;
}


/////////////////////////////////////////////////////////////////////////////////////
// class FlightComputer

FlightComputer::FlightComputer()
	: rb_cm4_to_cm7((lwrb_t *)BUFF_CM4_TO_CM7_ADDR)
	, rb_cm7_to_cm4((lwrb_t *)BUFF_CM7_TO_CM4_ADDR)
	, varioState((vario_t *)BUFF_VARIO_STATE_ADDR)
	, displayUpdateCount(0)
	, enterStandby(0)
{
	// mm.registerClient(&debug);
}

bool FlightComputer::flash_ok = false;
bool FlightComputer::sdram_ok = false;



void FlightComputer::setup(void)
{
	//
	pinMode(PWR_LED1, OUTPUT);
	digitalWrite(PWR_LED1, LOW);

	//RPI.begin(115200);
	//delay(100);

	// device check
	if (!flash_ok)
		TRACE("[DEBUG] Flash initialization failed.\r\n");
	if (!sdram_ok)
		TRACE("[DEBUG] SDRAM initialization failed.\r\n");

	//
#if SUPPORT_LVGL
	lv_init();
	hal_init();
	app_init();
#endif

	//
	//epdCont.begin();
	epdDisp.begin();
	keyPad.begin();

	//
	lwshell_init();
	lwshell_register_cmd("hello", shell_hello, "Answer me!");

	//
	line_len = 0;
	disp_front = disp_rear = 0;

	//
	drawVarioState();
	updateScreen(false);
}

void FlightComputer::loop()
{
	// sleep now
	if (enterStandby)
		standby();

	// process debug-shell event
	procDebugShell();
	// process keyboard event
	procKeyboard();
	// process interprocess event
	procInterProcess();

#if SUPPORT_LVGL
	// lvgl timer handler
	procLVGL();
#endif

	// update sreen
	if (millis() - displayUpdateTick > 1000)
		updateScreen();

	// debug purpose: blink LED
	{
		static uint32_t tick = millis();
		if ((millis() - tick) > 1000)
		{
			digitalToggle(PWR_LED1);
			tick = millis();
		}
	}



	// [TEST] forward GPS to Debug console
	//if (GPS.available())
	//	Debug.write(GPS.read());
	// [TEST] echo RPI & forward to Debug console
	//if (RPI.available())
	//{
	//	int ch = RPI.read();
	//	Debug.write(ch);
	//	RPI.write(ch);
	//}

	// console
	// CommandConsole console;
	//
	// console.SetInterface(Debug);
	// console.SetClient(SerialShell);

	//
	//epdCont.run();

	/*
	SPIClass spi(SPI4_MOSI, SPI4_MISO, SPI4_SCLK);

	spi.begin();
	spi.transfer(data);
	spi.transfer(ptr, size);
	spi.end();

	SPIClassEx spiEx;

	spiEx.begin(init_function);
	spiEx.transfer(sendPtr, sendLen, recvPtr, recvLen);

	spiEx.receive(dataPtr, dataLen, timeout, callback);


	Timer aaa;
	aaa.Expire(1000, class::callback);
	spiEx.end();
	*/
}


void FlightComputer::OnUpdateVario()
{
	TRACE("OnUpdateVario\r\n");

	drawVarioState();
	//updateScreen();
}

void FlightComputer::OnUpdateGPS()
{
	TRACE("OnUpdateGPS\r\n");

	drawVarioState();
	//updateScreen();
}

void FlightComputer::standby()
{
	TRACE("Enter standby mode\r\n");
	// flush cm4 message during 1s
	uint32_t tick = millis();
	while (millis() - tick < 500)
		procInterProcess();

	// show standby-screen
	drawStandby();
	updateScreen(false);
	HAL_Delay(200);

	// setup wakeup pin
	PWREx_WakeupPinTypeDef sPinParams;
	sPinParams.WakeUpPin    = PWR_WAKEUP_PIN1;
	sPinParams.PinPolarity  = PWR_PIN_POLARITY_LOW;
	sPinParams.PinPull      = PWR_PIN_NO_PULL;
	HAL_PWREx_EnableWakeUpPin(&sPinParams);

	// enter standby mode
	HAL_SuspendTick();
	HAL_PWREx_ClearPendingEvent();
	HAL_PWREx_EnterSTANDBYMode(PWR_D1_DOMAIN);

	// never comes here
	while(1);
	//TRACE("CM7 standby failed!!\r\n");
}


void FlightComputer::procDebugShell()
{
	// process shell command
	//while (Serial.available())
	//{
	//	int ch = Serial.read();
	//	lwshell_input(&ch, 1);
	//}
}

void FlightComputer::procInterProcess()
{
#if FETCH_LINE || 1
	//
	while (lwrb_get_full(rb_cm4_to_cm7) > 0)
	{
		uint8_t data;

		if (lwrb_read(rb_cm4_to_cm7, &data, 1) == 0)
			break;

		line_buf[line_len++] = data;
		if (line_len == sizeof(line_buf) || data == '\n')
		{
			//Serial.write((const char *)line_buf, line_len);
			if (line_buf[0] == '$')
			{
				for (int i = 0; i < line_len; i++)
				{
					disp_buf[disp_front] = line_buf[i];
					disp_front = (disp_front + 1) & 0x7FF;
					if (disp_rear == disp_front)
						disp_rear = (disp_rear + 1) & 0x7FF;
				}
			}

			line_len = 0;
		}
	}
#else
	//
	size_t len;
	void* addr;

	while ((len = lwrb_get_linear_block_read_length(rb_cm4_to_cm7)) > 0)
	{
		addr = lwrb_get_linear_block_read_address(rb_cm4_to_cm7);

		// forward to debug-shell
		Serial.write((const char *)addr, len);
		// or you can parse message and doing something

		// mark buffer as read
		lwrb_skip(rb_cm4_to_cm7, len);
	}
#endif
}

void FlightComputer::procKeyboard()
{
	// process key-event
	Key.run();

	// key-event handling
	int event = Key.getEvent();
	if (event == EVENT_NOKEY)
		return;
	TRACE("Key event: %X\r\n", event);

	//
	if ((event & EVENT_MASK_STATE) == EVENT_KEYUP)
	{
		if ((event & EVENT_MASK_KEY) == KeyPad::ENTER)
		{
#if 0 // bitmap drawing examples
			uint32_t lastTick = millis();

			if (imageType == 0)
			{
				epdDisp.drawBitmapBM(alien_bytes,  0,  0,  EPD_WIDTH, EPD_HEIGHT, COLOR_BLACK, bm_invert);
			}
			else if (imageType == 1)
			{
				epdDisp.drawBitmapBM(landscape_bytes,  0,  0,  EPD_WIDTH, EPD_HEIGHT, COLOR_BLACK, bm_invert);
			}
			else if (imageType == 2)
			{
				volatile uint8_t* ptr = epdDisp.getCanvas();

				// draw check-pattern
				for (int y = 0; y < 600; y++)
					{
						for (int x = 0; x < 100 /*800/8*/; x++)
						{
							int iy = y / 60; // 0 ~ 9
							int ix = x / 10; // 0 ~ 9

							*ptr++ = ((iy % 2) == (ix % 2)) ? 0xFF : 0x00;
						}
				}
			}
			imageType = (imageType + 1) % 3;

			updateScreen();
			TRACE("draw bitmap!: %u ms\r\n", millis() - lastTick);
#endif
		}
		else if ((event & EVENT_MASK_KEY) == KeyPad::ESCAPE)
		{
			// refresh screen
			updateScreen(false);
		}
		else if ((event & EVENT_MASK_KEY) == KeyPad::MENU)
		{

		}
		else if ((event & EVENT_MASK_KEY) == KeyPad::UP)
		{
		}
		else if ((event & EVENT_MASK_KEY) == KeyPad::DOWN)
		{
		}
		else if ((event & EVENT_MASK_KEY) == KeyPad::FUNC1)
		{
		}
		else if ((event & EVENT_MASK_KEY) == KeyPad::FUNC2)
		{
			// go to standby: signal to CM4
			HAL_HSEM_FastTake(HSEM_GOTO_STANDBY);
			HAL_HSEM_Release(HSEM_GOTO_STANDBY, 0);

			// now turn-on standby flag
			enterStandby = 1;
		}
	}
}

#if SUPPORT_LVGL
void FlightComputer::procLVGL()
{
	// lvgl timer handler
	static uint32_t tick = millis();
	if ((millis() - tick) > 5)
	{
		lv_timer_handler();
		tick = millis();
	}
}
#endif
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

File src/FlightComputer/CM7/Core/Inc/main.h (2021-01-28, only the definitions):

#define IMU1_SCLK_Pin GPIO_PIN_2
#define IMU1_SCLK_GPIO_Port GPIOE
#define IMU1_MISO_Pin GPIO_PIN_5
#define IMU1_MISO_GPIO_Port GPIOE
#define IMU1_MOSI_Pin GPIO_PIN_6
#define IMU1_MOSI_GPIO_Port GPIOE
#define KEY_ESCAPE_Pin GPIO_PIN_13
#define KEY_ESCAPE_GPIO_Port GPIOC
#define EINK_CMD_Pin GPIO_PIN_14
#define EINK_CMD_GPIO_Port GPIOC
#define EINK_BUSY_Pin GPIO_PIN_15
#define EINK_BUSY_GPIO_Port GPIOC
#define RPI_STATUS_Pin GPIO_PIN_1
#define RPI_STATUS_GPIO_Port GPIOC
#define PWR_WKUP0_KEY_ENTER_Pin GPIO_PIN_0
#define PWR_WKUP0_KEY_ENTER_GPIO_Port GPIOA
#define KEY_MENU_Pin GPIO_PIN_1
#define KEY_MENU_GPIO_Port GPIOA
#define GPS_TX_Pin GPIO_PIN_2
#define GPS_TX_GPIO_Port GPIOA
#define GPS_RX_Pin GPIO_PIN_3
#define GPS_RX_GPIO_Port GPIOA
#define EINK_nCS_Pin GPIO_PIN_4
#define EINK_nCS_GPIO_Port GPIOA
#define EINK_SCLK_Pin GPIO_PIN_5
#define EINK_SCLK_GPIO_Port GPIOA
#define EINK_MISO_Pin GPIO_PIN_6
#define EINK_MISO_GPIO_Port GPIOA
#define EINK_MOSI_Pin GPIO_PIN_7
#define EINK_MOSI_GPIO_Port GPIOA
#define KEY_LEFT_Pin GPIO_PIN_4
#define KEY_LEFT_GPIO_Port GPIOC
#define KEY_RIGHT_Pin GPIO_PIN_5
#define KEY_RIGHT_GPIO_Port GPIOC
#define USB_OTG_HS_ID_Pin GPIO_PIN_12
#define USB_OTG_HS_ID_GPIO_Port GPIOB
#define EPD_D6_Pin GPIO_PIN_11
#define EPD_D6_GPIO_Port GPIOD
#define EPD_D7_Pin GPIO_PIN_12
#define EPD_D7_GPIO_Port GPIOD
#define USB_OTG_HS_PWR_EN_Pin GPIO_PIN_13
#define USB_OTG_HS_PWR_EN_GPIO_Port GPIOD
#define EPD_CKV_Pin GPIO_PIN_8
#define EPD_CKV_GPIO_Port GPIOJ
#define EPD_CL_Pin GPIO_PIN_9
#define EPD_CL_GPIO_Port GPIOJ
#define EPD_GMODE_Pin GPIO_PIN_10
#define EPD_GMODE_GPIO_Port GPIOJ
#define EPD_LE_Pin GPIO_PIN_11
#define EPD_LE_GPIO_Port GPIOJ
#define EPD_OE_Pin GPIO_PIN_0
#define EPD_OE_GPIO_Port GPIOK
#define EPD_SPH_Pin GPIO_PIN_1
#define EPD_SPH_GPIO_Port GPIOK
#define EPD_SPV_Pin GPIO_PIN_2
#define EPD_SPV_GPIO_Port GPIOK
#define PWR_EN_PMIC_Pin GPIO_PIN_3
#define PWR_EN_PMIC_GPIO_Port GPIOG
#define PWR_EN_PERIPH_Pin GPIO_PIN_7
#define PWR_EN_PERIPH_GPIO_Port GPIOG
#define KEY_UP_Pin GPIO_PIN_6
#define KEY_UP_GPIO_Port GPIOC
#define KEY_DOWN_Pin GPIO_PIN_7
#define KEY_DOWN_GPIO_Port GPIOC
#define KEY_FUNC1_Pin GPIO_PIN_8
#define KEY_FUNC1_GPIO_Port GPIOC
#define KEY_FUNC2_Pin GPIO_PIN_9
#define KEY_FUNC2_GPIO_Port GPIOC
#define USB_OTG_HS_OVCR_Pin GPIO_PIN_8
#define USB_OTG_HS_OVCR_GPIO_Port GPIOA
#define DEBUG_TX_Pin GPIO_PIN_9
#define DEBUG_TX_GPIO_Port GPIOA
#define DEBUG_RX_Pin GPIO_PIN_10
#define DEBUG_RX_GPIO_Port GPIOA
#define VARIO_TX_Pin GPIO_PIN_10
#define VARIO_TX_GPIO_Port GPIOC
#define VARIO_RX_Pin GPIO_PIN_11
#define VARIO_RX_GPIO_Port GPIOC
#define USB_OTG_FS_VBUS_Pin GPIO_PIN_12
#define USB_OTG_FS_VBUS_GPIO_Port GPIOC
#define EPD_D0_Pin GPIO_PIN_2
#define EPD_D0_GPIO_Port GPIOD
#define EPD_D1_Pin GPIO_PIN_3
#define EPD_D1_GPIO_Port GPIOD
#define EPD_D2_Pin GPIO_PIN_4
#define EPD_D2_GPIO_Port GPIOD
#define EPD_D3_Pin GPIO_PIN_5
#define EPD_D3_GPIO_Port GPIOD
#define EPD_D4_Pin GPIO_PIN_6
#define EPD_D4_GPIO_Port GPIOD
#define EPD_D5_Pin GPIO_PIN_7
#define EPD_D5_GPIO_Port GPIOD
#define PMIC_VCOM_Pin GPIO_PIN_9
#define PMIC_VCOM_GPIO_Port GPIOG
#define PMIC_WAKEUP_Pin GPIO_PIN_10
#define PMIC_WAKEUP_GPIO_Port GPIOG
#define PMIC_PWRUP_Pin GPIO_PIN_11
#define PMIC_PWRUP_GPIO_Port GPIOG
#define PWR_LED1_Pin GPIO_PIN_14
#define PWR_LED1_GPIO_Port GPIOG
#define PWR_5V_EN_Pin GPIO_PIN_9
#define PWR_5V_EN_GPIO_Port GPIOB

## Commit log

2019-01-31 test: sine-wave generator --> for esp32
2020-08-07 pcb working...
    [Codec.sch, FlightComputer.kicad_pcb, FlightComputer.sch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]
2020-08-12 schematic working...
    [Codec.sch, FlightComputer.sch, Power.sch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]
2020-08-14 add raspberry pi zero pinout
    [Codec.sch, FlightComputer.sch, Power.sch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]
2020-09-15 add missing schematic
    [EINK-PMIC.sch]
2020-09-24 add stm32h745 pinout
    [Pinout.xlsx]
2020-09-25 schematic working....
    [EINK-PMIC.sch, FlightComputer.sch, KEYBOARD.sch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]
2020-10-03 update pin-map bom working... case working...
    [FlightComputer.FCStd, FlightComputer.xlsx, Pinout.xlsx]
2020-10-04 update pinmap
    [Pinout.xlsx]
2020-10-10 add keypad pcb & share library
    [FlightComputer-Keypad.kicad_pcb, FlightComputer-Keypad.sch, FlightComputer.FCStd]
2020-10-12 change folder tree
    [Codec.sch, DEBUG.sch, EINK-PMIC.sch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]
2020-10-16 pcb dimension
    [FlightComputer-Extra-Outline.dxf, FlightComputer-Extra-Parts.dxf, FlightComputer-Extra.kicad_pcb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]
2020-10-24 pcb complete 1st
    [Codec.sch, EINK-PMIC.sch, FlightComputer-Extra.kicad_pcb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]
2020-11-04 gerber final
    [FlightComputer-B_Cu.gbr, FlightComputer-B_Mask.gbr, FlightComputer-B_Paste.gbr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]
2020-11-09 trace length matching & generate gerber files
    [FlightComputer-B_Cu.gbr, FlightComputer-B_Mask.gbr, FlightComputer-B_Paste.gbr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]
2020-11-09 stm32cubemx configuration
    [Pinout.xlsx]
2020-11-13 schematic pdf files
2020-11-17 reconf mcu
    [Pinout.xlsx]
2020-11-23 fixed eink position
    [FlightComputer.FCStd]
2020-11-24 test sdram(ok), quad-spi-nor(cond)
2020-11-25 h/w test GPS: OK NOR-FLASH: Direct(OK), MemoryMapped(FAIL: NEED MORE TIME) IMU(SPI): H/W Fault -> swapped Pin 3,4 PMIC: Communication(OK), Turn on Power Rail(FAIL)
    [MPU9250.c, main.c, main.h]
2020-11-25 stm32 usb documents
2020-11-26 h/w test cont - spi1: ok - uart3: ok - spi4: communication ok. but device does not response properly
2020-11-26 H/W Test: change imu interface (SPI -> I2C)
2020-12-03 fixing pcb layout (cont)
    [FlightComputer.sch, MCU.sch, Pinout.xlsx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]
2020-12-04 reinforce PMIC layout
    [EINK-PMIC.sch, FlightComputer.sch, MCU.sch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]
2020-12-04 add missing footprints
    [Power.sch]
2020-12-04 change 5v booster --> TPS61022
    [FlightComputer.sch, MCU.sch, Pinout.xlsx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]
2020-12-05 rework pcb design
    [CurrentMeasure.kicad_pcb, CurrentMeasure.sch, DEBUG.sch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]
2020-12-06 update current sensor
    [CurrentMeasure.kicad_pcb, CurrentMeasure.sch]
2020-12-07 PIMIC rework finished
    [CurrentMeasure-B_Cu.gbr, CurrentMeasure-B_Mask.gbr, CurrentMeasure-B_Paste.gbr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]
2020-12-07 rename to Current sensor
    [CurrentMeasure-B_Cu.gbr, CurrentMeasure-B_Mask.gbr, CurrentMeasure-B_Paste.gbr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]
2020-12-09 USB Host Test(cont)
    [FlightComputer.xlsx, Raspberry.sch, Vario.sch]
2020-12-09 update extra purchase
    [FlightComputer.xlsx]
2020-12-27 removed FC_HWTest added FC_Test
    [FlightComputer.FCStd]
2021-01-02 fixed memory-mapped mode (dummy cycle)
    [main.c, quadspi.c]
2021-01-05 External EINK PMIC
    [EINKPower.kicad_pcb, EINKPower.sch]
2021-01-10 EINK Test (OK)
    [epd-waveform.xlsx]
2021-01-15 another waveform
    [epd-waveform.xlsx]
2021-01-22 pcb rev2 (TBD)
    [Codec.sch, DEBUG.sch, EINK-PMIC.sch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]
2021-01-23 FC rev2
    [EINK-PMIC.sch, EINKPower.kicad_pcb, EINKPower.sch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]
2021-01-24 change board outline
2021-01-24 fixed incorrect connection
    [EINKPowerMod.kicad_pcb, EINKPowerMod.sch]
2021-01-25 LT1945 voltage calculator
    [LT1945-Voltage-Calculator.xlsx]
2021-01-26 add drivers & middlewares
2021-01-27 usb device/host
    [LT1945-Voltage-Calculator.xlsx]
2021-01-27 bat_sense add capacitor
    [EINK-PMIC.sch, Power.sch]
2021-01-28 Arduino porting (TBD)
2021-02-19 framebuffer outline
2021-02-20 buzzer (TBD)
    [MCU.sch, Pinout.xlsx, Vario.sch]
2021-03-01 on/off vcom
    [EINKPowerMod.kicad_pcb, EINKPowerMod.sch, FlightComputer-rev2-BOM.xlsx]
2021-03-16 mod BOM
    [FlightComputer-rev2-BOM.xlsx]
2021-04-22 PMIC driver (TBD)
    [FlightComputer-rev2-BOM.xlsx]
2021-04-30 another vario: AcousticVario
    [AcousticVario.sch, Pinout.xlsx]
2021-05-07 case mod
    [FlightComputer.FCStd]
2021-05-14 case bottom/spacer stl
    [FC-Bottom.stl, FC-EPaperSpacer.stl, FlightComputer.FCStd]
2021-05-15 fixed bottom case re-design spacer
    [FC-Bottom.stl, FC-EPaperSpacer.stl, FlightComputer.FCStd]
2021-05-27 update cover, enclosure
    [FlightComputer.FCStd]
2021-05-28 usb power-delivery stubs
2021-06-09 redraw waveform
    [epd-waveform.xlsx]
2021-11-05 fixed miss connection
    [CurrentMeasure.kicad_pcb, CurrentMeasure.sch]
2021-11-16 show raw pressure data
2021-11-21 EPD Display (working)
    [epd-waveform.xlsx]
2021-12-06 extra core-board
2021-12-22 GY-91 test
    [FlightComputer_ButtonDesign.FCStd]
2021-12-22 timer test
2021-12-26 arduino code: current measurement
2021-12-29 replace arduino code with latest (not working)
    [Main.cpp, PeripheralPins.c, fc_main.cpp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]
2021-12-31 - sensor & variometer library - update SPI, Wire library
2022-01-01 optimize voltage reading
2022-01-01 current-sensor zero calibration
2022-01-02 display sensor info

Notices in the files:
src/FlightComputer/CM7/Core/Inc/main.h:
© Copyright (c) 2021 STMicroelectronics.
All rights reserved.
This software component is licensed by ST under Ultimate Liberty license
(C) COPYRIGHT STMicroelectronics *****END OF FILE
